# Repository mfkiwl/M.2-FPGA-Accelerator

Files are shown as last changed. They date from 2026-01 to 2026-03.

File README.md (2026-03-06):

# M.2 FPGA Hardware Accelerator Devboard

This is my in-progress FPGA hardware accelerator! It'll essentially plug into an SSD slot on your computer, and function as a programmable FPGA fabric that you can use to practice hardware acceleration and other things in HDL! Not just that though, it also functions as a standalone devboard with USB to JTAG and HDMI and ontop of that, you can use it for hybrid purposes involving external devices AND your computer! 









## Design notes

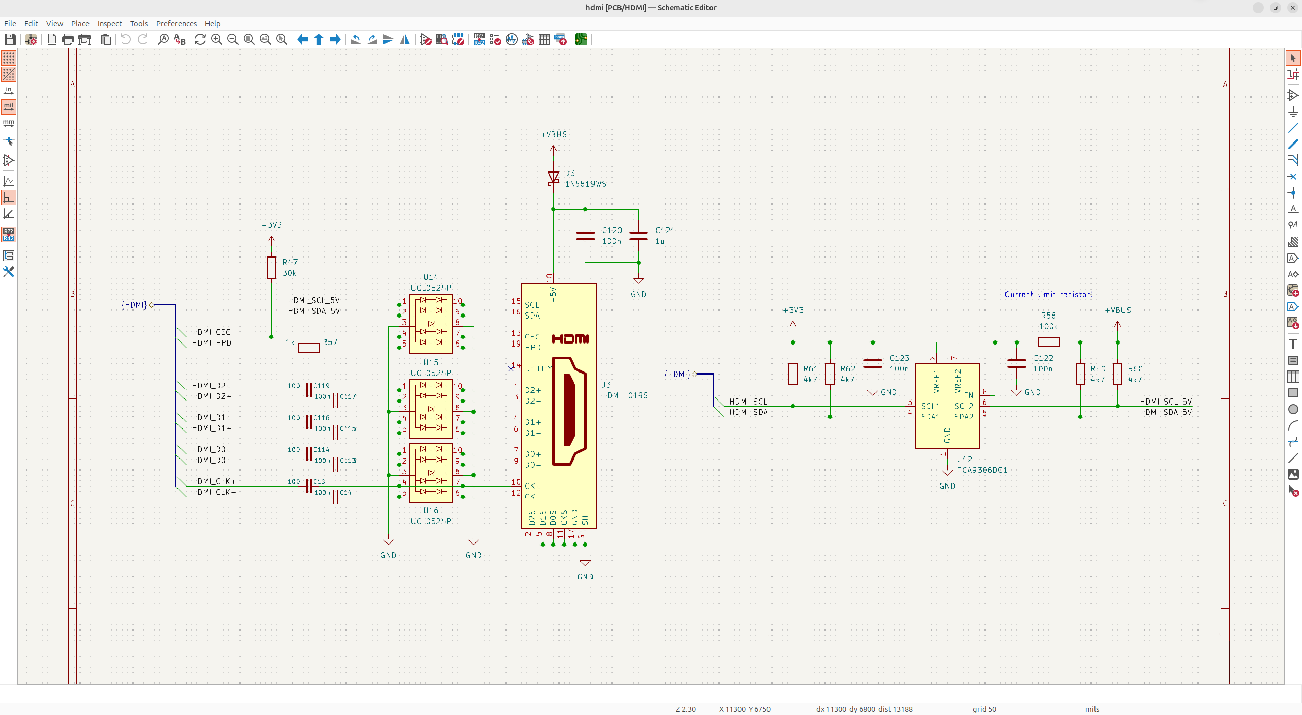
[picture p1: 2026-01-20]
images/Pasted image 20260120061538.png

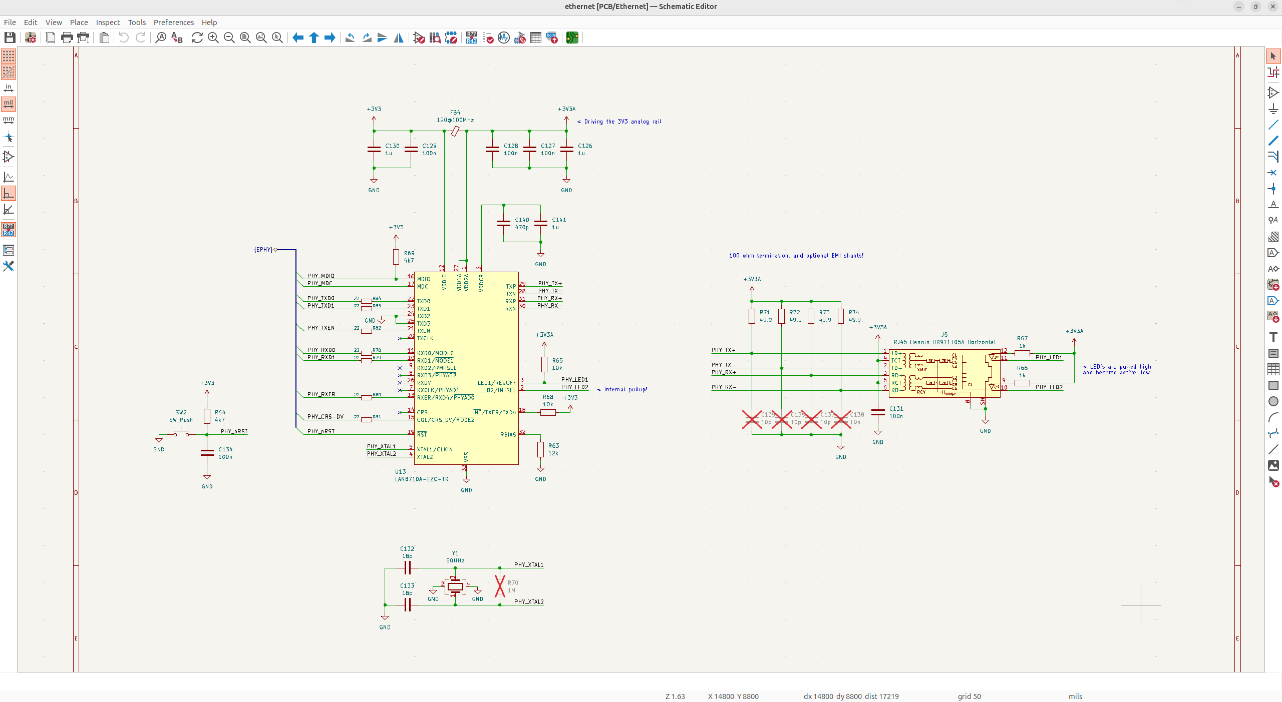
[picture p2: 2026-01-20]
images/Pasted image 20260120062520.png

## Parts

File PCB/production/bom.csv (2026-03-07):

Designator | Footprint | Quantity | Value | LCSC Part #
C1, C101, C103, C126, C130, C133, C134, C141, C142, C15, C152, C153, C159, C160, C166, C167, C2, C21, C22, C23, C32, C33, C37, C40, C41, C42, C43, C44, C56, C66, C68, C70, C87, C89, C90, C94, C98 | 0603 | 37 | 4u7
C10, C11, C12, C3, C4, C5, C6, C7, C8, C9 | 0402 | 10 | 220n
C100, C102, C104, C105, C106, C107, C108, C109, C118, C124, C125, C127, C129, C135, C136, C137, C138, C143, C144, C145, C146, C148, C150, C151, C154, C155, C156, C157, C161, C162, C163, C164, C168, C169, C17, C170, C171, C18, C19, C20, C25, C27, C28, C29, C30, C31, C35, C36, C38, C39, C47, C54, C55, C67, C69, C71, C91, C92, C95, C99 | 0201 | 60 | 470n
C110, C111, C113, C114, C115, C116, C117, C119, C120, C122, C123, C139, C14, C16, C57, C58, C59, C60, C61, C62, C63, C64, C65, C73, C74, C76, C77, C78, C79, C80, C81, C82, C83, C84, C86, C93 | 0402 | 36 | 100n
C112, C121, C46 | 0402 | 3 | 1u
C128, C72 | 0603 | 2 | 47n
C13, C172 | 0402 | 2 | 10n
C131, C132, C140, C147, C149, C158, C165, C34, C45, C49, C51, C53, C75, C85, C88 | 1206 | 15 | 47u
C24 | CP_EIA-3528-21_Kemet-B | 1 | 330u | C542287
C26 | 1206 | 1 | 100u | C15008
C48 | 0402 | 1 | 68pF
C50, C96, C97 | 0402 | 3 | 33p
C52 | 0402 | 1 | 22pF
D1, D2 | 0805 | 2 | KT-0805Y | C2296
D3 | D_SOD-323 | 1 | 1N5819WS | 1N5819WS
D4 | 0805 | 1 | KT-0805G | C2297
FB1, FB2 | 0805 | 2 | 120@100MHz | C5120901
J1 | M.2 M-Key 2242 | 1 | Bus_M.2_Edge_M
J4 | USB_C_Receptacle_HRO_TYPE-C-31-M-12 | 1 | TYPE-C-31-M-12 | C165948
J7 | HDMI_Micro-D_Molex_46765-1xxx | 1 | HDMI_D_1.4 | C711358
L1, L2, L3, L4, L6 | L_Sunlord_SWPA4030S | 5 | 1u5 | C42100
R1, R31 | 0402 | 2 | 100
R10, R11, R12, R13, R34, R38, R39, R40, R41, R45, R46, R5, R51, R53, R54, R7, R9 | 0402 | 17 | 10k
R14, R15, R17, R18, R2, R24, R3, R42, R43, R44, R56, R57, R76, R77 | 0402 | 14 | 1k
R16 | 0402 | 1 | 240
R19, R20, R21, R22, R23, R27, R28, R30, R59, R60, R61, R62 | 0402 | 12 | 4k7
R25, R26, R29, R32, R36, R37, R75 | 0402 | 7 | 22
R33, R47 | 0603 | 2 | 30k
R35, R6 | 0603 | 2 | 4k99
R4 | 0402 | 1 | 2k
R48, R49 | 0402 | 2 | 5k1
R52 | 0402 | 1 | 2k2
R55 | 0402 | 1 | 12k
R58, R65 | 0402 | 2 | 100k
R8 | 0603 | 1 | 8k2
SW1 | SW_SPST_TS-1088-xR020 | 1 | SW_Push | C720477
U1 | Xilinx_FGG484 | 1 | XC7A50T-FGG484
U10 | QFN-64-1EP_9x9mm_P0.5mm_EP4.35x4.35mm | 1 | FT2232HQ
U11 | FBGA-96_8x14mm_Layout9x16_P0.8mm | 1 | MT41J128M16JT-125:K | C426885
U12 | VSSOP-8_2.3x2mm_P0.5mm | 1 | PCA9306DC1 | C129510
U14, U15, U16 | Diodes_UDFN-10_1.0x2.5mm_P0.5mm | 3 | UCL0524P | C2835428
U17 | VQFN-16-1EP_3x3mm_P0.5mm_EP1.68x1.68mm_ThermalVias | 1 | TPS62132
U2 | QFN-28_L5.0-W5.0-P0.50-TL-EP3.2 | 1 | MAX20029ATIA/V+ | C1235515
U3, U4, U6 | Texas_DRT-3 | 3 | TPD2EUSB30
U5 | Texas_VQFN-HR-12_2x2.5mm_P0.5mm_ThermalVias | 1 | TPS2121RUXR | C485916
U7 | W-PDFN-8-1EP_6x5mm_P1.27mm_EP3x3mm | 1 | MT25QL128ABA1EW7-0SIT | C2887898
U9 | SOIC-8_3.9x4.9mm_P1.27mm | 1 | M93C56-WMN6TP
Y2 | Crystal_SMD_3225-4Pin_3.2x2.5mm | 1 | 12MHz | C9002
Y3 | Oscillator_SMD_SiT_PQFN-4Pin_5.0x3.2mm | 1 | 100MHz | C78882

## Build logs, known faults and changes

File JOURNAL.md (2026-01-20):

---
title: FPGA Accelerator
author: Kai Pereira
description: " A low-cost, PCIe FPGA accelerator M.2 M-Key form factor devboard for hobbyists"
created_at: 2025-12-16
---
## The idea - 2 Hours

I've worked on a ton of different boards ranging from keyboards, to motherboards to hackathon badges to even carriers, but now I want to work on something next level.

I've always been fascinated by hybrid computing in a consumer setting and building complicated stuff, so with that in mind, I've come up with my next idea.

FPGA's are becoming much more mainstream for parallelization and computing so I want to explore how hobbyists can leverage this technology in an affordable and cool way.

The thing about FPGA's, is while they're really useful, it's hard to make practical applications of them as a hobbyist, because it's not like you're going to innovate the next big chip or something, but that's where I want to leverage the fact that FPGA's aren't just useful for mainstream chips, but also more niche applications like very specific hardware acceleration, that consumers can actually make cool use of and practice.

Pasted image 20251216201028.png

So the idea is simple, I want a low-cost way, hobbyists can make practical applications of FPGA's in a bunch of different settings.

To do this, I want to provide an FPGA devboard of sorts, that can interface with your computer hardware so you can practice on real-world applications in more niche settings. But I want to go a step further and also make it function as a standard devboard in case you don't have access to an M.2 slot, so I need to break out like standard USB-C and whatnot.

This also means that I want to add other functions like HDMI, maybe even GbE and just generally make it insanely useful to hobbyists!

There's a couple key goals I have for this project:
- Learn to route BGA and high-density impedance controlled traces
- Learn GbE, HDMI and PCIe routing
- Understand at a high level, the physics behind the board
- Focus on routing best practices, specifically minimizing loops

This project has already been similarly done by Phil's lab, but his project was more-so focused on acceleration instead of as a hobbyist development board, but this video will still be really useful to reference during development of this project! https://www.youtube.com/watch?v=8bw80LiCl7g

## Connectors!! - 4 Hours

Now the first thing I have to decided, is what type of edge connector I want to use. Now NVMe SSD's are standard M.2 size, but have different type of "keys" which is essentially where the different holes are on it:

Pasted image 20251219113929.png

NVMe SSD's mostly just use M-Key edge connectors, so that's what I'm going to use.

But now, there's also more than just one type of size, there's actually 5 of them (probably more than that, but the 5 most common)

Pasted image 20251219114039.png

Now 2280 is by far the most common, but I don't actually think I'll use all that space, so for now, I think I'm going to go with 2242 which is decently common still but for other applications most of the time.

The numbering system is really simple. 2242 means 22mm x 42mm, 2280 means 22mm x 80mm.

So now i have to create my footprint and symbol for these edge connectors. I can also easily change my form factor after making the footprint because it's legitimately just the height that changes.

Lucky for me, someone's already made some M.2 footprints and symbols, so I'm going to use these ones from https://github.com/timonsku/M.2-Card-Footprints

Now this person didn't actually make an M-Key, so I had to modify one of the existing ones to make it. M.2 footprints are really interesting, because they literally just remove the pins where the key is and don't really shift anything, so it's easy to make footprints for:

Pasted image 20251219114720.png

Now I was thinking I might be able to use a B+M-Key to be more compatible, but the ECP5 only has a soft SATA PHY or SERDES which would be really complicated and annoying to implement, so I'm just keeping it symbol.

And then this library I downloaded included the symbols already, so I'm all set to get working:

Pasted image 20251219115014.png

## Edge connector and choosing an FPGA - 4 Hours

Now I want to get working on actually wiring the edge connector! The first thing I'm going to do is wire the power and ground.

I decided to use one 100nF cap per pin, and then one 1uF + 10uF per group of them like so:

Pasted image 20251219121205.png

I'm referencing the M.2 PCI express electromechanical datasheet for pins https://picture.iczhiku.com/resource/eetop/sHksKPigIJigRbbx.pdf

Pasted image 20251219121236.png

I've decided to 0402 for 100nF, and 1uF, and then 0603 for 10uF to save as much space as possible, but still be pretty efficient at decoupling.

Next, I need to choose what FPGA I actually want to use. The first thing that comes to mind is the ECP5. It's a small and cheap FPGA with SERDES so it works with PCIe which is really cool. 

It has a faster (5G) and slower version, so I can have gen 2 PCIe speeds which is pretty cool. The minimum 5G FPGA costs around $18.50 https://jlcpcb.com/partdetail/Lattice-LFE5UM5G_25F8MG285C/C1551932 so it's a pretty good option.

But there's also the Xilinx Artix FPGA which is significantly more powerful, the XC7A100T has nearly 4x the LUTS and is way more powerful, but is also significantly larger, having 4x lanes. The price is actually pretty good though, coming in at just $29.

So the Artix FPGA is probably a better option, because the price and accessibility of the ECP5 for the specs I need is just kind of out of scope. It'll also give me really good practice with a really popular AMD FPGA which could be really helpful for the future! 

Now the Xilinx Aritix has MANY different packages, ranging from 12K to 215K LUTs and 720 to 13000 Kb of memory. I also need a minimum of 4 GTP transceivers which are essentially just high speed pins so 15K LUTs minimum.

But let's stay within the price range, so I want under $20 for the FPGA and preferably over 25K LUTs which gives me many good options!

This means I should also increase the size of my board from 2242 to 2280 which I actually wanted an excuse to do, and I can also add all those other features. 

So in the end, I think I'm going to go with the XC7A50T-1FGG484C, the Xilinx Artix 7, with 50K LUTs, coming in at just $17 at minimum quantities, and having 484 pins!!! https://jlcpcb.com/partdetail/AMDXILINX-XC7A50T1FGG484C/C1521780

I think this is honestly the perfect option, and I know Phil's Lab uses the same one, but it's the best for the job!

## Working on the FPGA - 3 Hours

Now that I know I want to use the Artix 7 FPGA, I need to add it into KiCad. I'm really lucky because KiCad actually has this symbol built in, but the footprint doesn't seem to come up, so I'll need to look into that:

Pasted image 20251220104108.png

Pasted image 20251220104157.png

And lucky me, a footprint actually does exist!!

Pasted image 20251220104406.png

Next, I want to figure out what voltage lines I need for my project. Based off of the datasheet, I'll need:
- VCCINT 1V, FPGA fabric logic, lowest voltage for CMOS is 1V
- VCCBRAM 1V. internal block RAM, needs to be really stable
- VMGTAVCC 1V, analog GTP transceivers voltage, might need to be seperate from VCCINT
- VCCAUX 1V8, powers configuration and clocking stuff, 1V8 for noise margin
- VCCO 3V3, powers I/O banks 3V3 because connector is 3V3 and I use 3V3 logic
- VMGTAVTT 1V2, very interesting termination voltage, it basically controls the impedance of the GTP transceiver/PCIe lines, and makes sure they don't see reflections and too much nosie!
- DDR3 Voltage, 1V5 for DDR3 I/O bank pins which are 1V5 for standard DDR3 (1V35 for DDR3L)

Pasted image 20251220165608.png

So now that I have all the theory worked out, I can get working on making the actual thing! 

This was just a bunch of datasheet reading today and a couple video's, but I have a really good idea on how to do this now!

## Decoupling time! - 5 Hours

Decoupling is fairly simple with the Artix 7, the datasheets tell you almost exactly how to do it:

Pasted image 20251221082541.png
Pasted image 20251221082558.png

So just like that, I organized everything and added in the decoupling: 

Pasted image 20251221082621.png

And I'll also need ferrite beads on these lines, but before that, I want to figure out what PMIC I'm going to use. I have 4 rails, and I need 3V3, so a quad switching buck converter would be a really good option! 

I want to do this, because the characteristics of the bucks will help me determine the values of the ferrite beads!

I spent nearly 6 hours straight, fueled from Yerba and classical music trying to find the best buck, and I've found 2 possible options.

The [MAX20029](https://www.analog.com/en/products/max20029.html) is the lower cost option, with up to 1.5A channels, and is fixed/adjustable, though I would only use the fixed part. It's high efficiency, but the efficiency kind of drops off at lower current, but it has a smaller package and is designed for automotive. You can use the same value inductor on all the rails and it has power sequencing. This is the same one that Phil's lab uses, and it's really good!

The [LTC3370](https://www.digikey.ca/en/products/detail/analog-devices-inc/LTC3370IUH-TRPBF/5155587) is a bit more overkill, with strong 2A channels, and really good efficiency characteristics. It's a bit larger and a bit more expensive, and it's a bit overkill, but you can have the same value inductors, and is also a fantastic option! 

I've legitimately looked at 100's of buck converters, and these are probably the 2 best options! 

In the end, I think I'm going to go with the MAX20029 because it has smaller inductors, is cheaper and perfectly fits the specs. Even though it's what phil uses, it honestly just is the superior option and the only downfall is I can't use any of the fixed variants, so I have to use quite a few voltage dividers. 

I've done a lot of research today, so I think I'm going to hop off for now! 

## Power management! - 8 Hours

Now that I've found what PMIC I want to use, we need to add it into KiCad.

But after some second thought, I've decided that the LTC3370 is actually probably a better choice because of it's higher current demands which means better power tolerance, and I want support for all the extra peripherals I might add too. 

So let's add that in! 

The first thing I need to do is create the symbol for my buck converter. After referencing the datatsheet and tuning things up, I've come up with this pretty clean symbol that will probably change to my likings, but it's good as a template, and has all the necessary pins and footprint! 

Pasted image 20251225000450.png

Pasted image 20251225000521.png

Next, I'm going to wire all the important stuff for the buck converter. Per the datasheet, each input should have a 22uF cap, VCC should have 10uF, and each 2A channel output should have 47uF! 

I calculated the voltage dividers using VOUT = VFB(1 + R2/R1), and used 100K as my bottom resistor to minimize my BOM. This gives me a really nice and convenient voltage divider setup:

I also used 2.2uH inductors which are recommended by the datasheet for 2A, and they have a really low ESR to minimize power loss:

Pasted image 20251225000820.png

BUTTTT, this is kind of when I had a brain blast and decided to just outright switch to the MAX20029.

I realized that I would be saving over $7 with the MAX20029 and it has way simpler power sequencing and smaller package, so it's just significantly better.

So let's make the symbol for the MAX20029! I came up with this tall little symbol, I might make it larger but it kind of fits my needs:

Pasted image 20251227142741.png

And then it's really simple wiring, you just need pullups on PG to have a stable state, and also calculate the voltage dividers and frequency matching capacitors:

Pasted image 20251227142844.png

PG1 will go high when it's active, and the pullup just helps to ensure it gets there. There's no voltage divider on 1V0, because the VOUT is already 1V, and then the rest have voltage dividers to get there and frequency matching rounded down to the nearest E6 capacitor!

## More decoupling and filtering - 5 Hours

Now that I've finished with my power supply, I need to figure out how to properly filter it for my analog rails! 

This actually took me a really long time to figure out because I've never fully understood ferrite beads, but after a bit of research and talking with the KiCad guys, I've done a simple but effective implementation in my opinion:

Pasted image 20251229001159.png

I chose 600R@100MHz to filter out the high frequency noise moderately and it's low DCR so it has a minimal drop and is up to 2A. I made a little low pass filter LC filter by adding some shunts to ground, and added a bulk before the cap on MGTAVCC because it's higher current!

I decided to also set up an LTSpice simulation for these ferrite beads, just to make sure everything will be fine, and I can use it in the future for more accurate testing and adjusting once I've finished routing the board!

This took me a really long time to figure out, but I think it turned out really well! 

Pasted image 20251231173655.png

This isn't too relevant right now, but will be really useful once I've finished routing! 

I also fixed up some of the decoupling on my m.2 edge connector because it wasn't using the standard values in my schematic.

Pasted image 20260106130817.png
It actually took me so long to figure out LTSpice, but that was essentially how my day went! 

## Configurations and JTAG, oh no - 15 hours

So now I have the majority of my fundamental power system in place, but I actually need a way to program this thing. The first thing I have to do is configure the artix 7 to work over master SPI. I referenced the datasheet for this part and it pretty much tells you what to do:

Pasted image 20260106131135.png

A 0 means tie it low, and a 1 means tie it high. I also added this DNP resistor in case you want to use the artix 7 built in flash for debugging, so it's just kind of handy:

Pasted image 20260106131305.png

I also learned how buses work, and created a JTAG bus which connects to a hierarchial label which will connect to my USB to JTAG/TC2030.

The next thing I need to figure out is my JTAG. This is how the board will be programmed, the JTAG interface will feed into the artix 7, and the artix 7 will feed it into SPI.

Now the first thing I want to do is add on a TC2030 interface which is a compact way of programming JTAG using this little debugger:

Pasted image 20260106131603.png

I also wanted to have USB to JTAG because it's way easier and actually cheaper to debug with it because you don't need an external probe. Now I probably spent over 10 hours thinking about how I should do my USB to JTAG, I put so much thought into this.

But at the end of the day, Vivado, the tool I'm probably going to use to program my board, and all the other tools only really support FT2232H, and because I'm probably going to be debugging a bunch, I didn't want to bitbang, so I decided to go with the large and expensive IC for programming!

The thing is, I don't have to place the FT2232H in my production runs, only in my prototypes runs so it's perfectly fine to have for prototyping, it'll just cost more for those boards though....

I also wanted to have USB to power and program the board, so I came up with this monstrosity of a schematic:

Pasted image 20260106131956.png

USB-C comes in, get's bucked down and has some ESD protection. The data lines go into the FT2232H USB to JTAG, and then JTAG get's pulled up so nothing's floating, and goes into my bus for use in the configurations schematic. The TC2030 will go underneath the USB-C receptacle and if you DNP the USB to JTAG logic, it'll still be programmable via the probe. Pretty cool huh :D

I did some really good work for these couple days, but I'm still missing some fundamental logic for this circuit that's really important, but we'll see this in the next section!

## Power architecture - 6 Hours

Now there's a bit of a problem that arises with having both USB-C and an m.2 edge connector supplying our board. What if the current just flows right onto the motherboard, completely frying and destroying it.

This is why we need to implement a power mux on our board! I usually try to shy away from power mux's because there's usually a smarter way of solving power issues, but in this case, it was pretty much necessary, and the slight added cost is important so that our board functions smoothly.

I found this nearly perfect IC, which let's met control the ramp up of the inrush, the max current, switchover and so much more, all in a small package! This is THE TPS2121RUXR.

This beauty took me a whole to wrap my head around, but it does everything for me:

Pasted image 20260106132555.png

I prioritized the M.2 connector source because the motherboard is always going to supply smooth power because you need to be able to have a reliable computer right!

And then of course I added some smooth decoupling, and we got that finished after some time! 

I'm going to end off this section here, because now we're going to get into some really technical territory, figuring out the pinouts for my flash, ram, etc. It's going to be a wild ride! 

## Flash storage and configurations - 4 Hours

Now that I've finished with the power architecture of my board, I need to implement all the configurations for my board and also add the flash storage.

The flash storage is fairly simple, there's some fixed pins on the artix 7 for it, so I can just wire it to those with some pullups according to the artix datasheet. I then added some decoupling:

Pasted image 20260111151005.pngPasted image 20260111151023.png

Next, I added a basic configuration to the board to make it work according to UG470:

Pasted image 20260111151114.png

- DONE is wired so that the LED will turn OFF when the configuration is finished and ON when it's actively configuring. 
- INIT is just a configuration pin that tells you if there's any configuration errors and needs to be pulled high <= 4k7R
- PROGRAM is another configuration pin that's used for configuration reset, and I just needed to pull this high. After reading this a second time, I decided to actually add a button to manually reset it if I wanted to, because this board is technically a devboard ya know (shown below)
- CFGBVS is a bank voltage configuration, it's needed because there's configuration pins on multiple banks so to maintain a near the same voltage of all of the them, I pulled this high to tell the artix 7, they're all 3V3 essentially
- And then, VP/VN, VREFP/VREFN and DXP_0/DXN_0 are essentially just part of the XADC to get internal reads of the FPGA and whatnot, and I just tied them low for now to disable all of that, but I want to revisit it, but not necessarily change any of it!

Pasted image 20260111153814.png

## Fun DDR3 wiring time now :D - 6 Hours

Now that I've wired up the flash storage, I need to add in the DDR3 memory! Flash storage is non-volatile which means it stores information long term, retaining all of it without power, while RAM is volatile and is used for active tasks (but you probably knew that ;). 

DDR3 works pretty fast, so you have to pay attention to how you wire it! I chose my RAM from an artix 7 datasheet which specifies the compatible ones you can use, and I chose MT41J128M16JT.

This is a 2 Gb (gigabit) memory with 16 bit data width which means it's 256 MB (2Gb / 8) of memory that can fit 128M words 16 bits wide, because 2Gb / 16 = 128! 

Pasted image 20260111211326.png

I created this custom DDR3 symbol because I like to have my decoupling pins visible so I don't make any dumb mistakes. I did a 100nF cap per VDD pin and then a bulk cap near both sides to keep it stable.

Next, I wired all of the address, command, data and clock buses to hierarchical sheets to keep it clean.

CS# is then tied low, because I'm only using one memory IC, and I have pulldowns on ODT, CKE and RESET as suggested from most reference boards. I put a 100R shunt resistor (an AC resistor) to match the differential impedance of 100R, and then ZQ is tied to 240R which is like a calibration pin and needs to be tied with this exact value! 

You'll notice a perfect split voltage divider on Vref, which is essentially just half of VCC, and it needs to be really precise to distinguish cleanly between high and low data signals for fast DDR3 signals. I put a bunch of decoupling on it to make sure it's really precise with very low noise! 

And that's our DDR3 wired, it was a lot more complicated to do than I described, but that's the gist of it! 

## PCIe and the GTP WHAA transceivers ;) - 5 Hours

Now that I've added DDR3 in, I can power on my board, fully program it and execute commands on it too! Now I need to wire the PCIe lanes to the GTP transceivers which lets me board connect to your computer via the m.2 connector! 

Remember earlier how we added in the m.2 connector for power, well now I just have to wire all the lanes up and came up with this:

Pasted image 20260111213647.png

I changed up the decoupling to instead be a mid range cap per group of pins, because all I really care about is dampening the inrush when plugging the board in/out and powering it on. 

Now let's list out what all of these signals are for! All except for SUSCLK are SATA only pins, and SUSCLK is just for low power states, when you sleep your computer and want to still maintain basic functions which I don't want.

Next, I actually modified my old symbol to create this edge connector symbol which basically just inverses the PCIe text to be more accurate of what's happening on our board. So the pins that were originally receiving PCIe in the form of a bus, are SENDING them now on our board. So all of these transmits, are what's transmitting to our card.

It's mutually known that the side receiving the signals should handle it's own AC coupling, so my FPGA TX lanes, which are sending from the edge connector, and receiving into my board, are going to be AC coupled! 

Because PCIe is close to a fundamental square waveform, it's got sharp edges. So these capacitors in parallel filter out the DC noise, and only allow the switching waveform noise to pass through, pretty cool huh! I used 220nF because it's suggested for if you want multiple generation backwards compatibility because you can use like gen 3 in gen 2 systems, gen 4 in gen 2 and so on and so forth.

CLK also has AC coupling because the direction isn't fixed so they should both be handling it regardless! 

Next, you'll notice 22R dampening resistors on some of the command lines. These are the longer and slower command lines which just travel really far, so I just want to make sure nothing got messed up on the way. PERST is a bit faster so I don't want to cause anti-resonance by adding in dampening resistors on it.

Now we need to just wire these PCIe signals into our FPGA, and BOOM, we're done!

Pasted image 20260111214553.png

We don't use the other clock and it's probably reserved for some other uses, so I'm just going to no connect it for now! I want to double check I did this right later, but it should be fine! 

## Time to HDMI - 6 Hours

Because I want my FPGA hardware accelerator devboard to function as a standalone devboard, I really want to add HDMI so that I can use it as a linux capable device, and some other very fun shenanigans. 

Because you could plug it into both your computer and HDMI, you could do fun things like low latency video output or video processing or even data visualization for the whole acceleration!

So I came up with this little schematic:

![[Pasted image 20260120061538.png]]

First of all, I don't want ethernet powering my board, so I added a diode to prevent that, and it's connected to VBUS so if USB is plugged in, you get the extra features from HDMI.

I want to actually add a really small boost onto the board so that I can get these features, so I'll think about the best way of adding that! 

My board is pretty noisy, so I added a 1uF cap just because I can, and then of course 100nF for basic decoupling.

The only signals that actually need level shifting is DDC because it's I2C so it's decently fast and important signals. I decided to do some fancy current limiting on HPD so it's a really weak 5V signal that can't damage my FPGA but the FPGA can clamp the voltage to still be able to read it! 

And then CEC is just the electronics control and it's a 3V3 signal that I just need a weak pullup on! 

I added ESD protection to all of the lines, just because I want to create a pretty professional board, and I also added minor AC coupling because it's really fast edge-rate signals.

I think I had a really strong fundamental understanding of this wiring which I'm really proud of myself for, but I really need to get that 5V sorted out, and a $1 boost might be the best way to do that. 

## Ethernet shenanigans - 7

The second peripheral I wanted to add onto the board is ethernet! 

Ethernet is really cool to add to an FPGA board like this, because it allows you to use the FPGA as like a firewall of sort, or even send signals, and it just has some really neat use cases.

I decided to use a magjack with integrated magnetics and other useful stuff because I don't want to have to worry about all of that working with ethernet for the first time. 

![[Pasted image 20260120062520.png]]

First, you'll notice really strong pullups on MDI lines. These aren't actually pullups, and are instead parallel termination. Essentially when signal reflections hit these lines, they'll sink into the power/ground instead of just continuously reflecting, and this is why it's on the analog rail, so the power can get filtered! 

Next, you'll notice my basic decoupling and termination on TX/RX lanes. The RX termination will be close to the PHY, and the TX termination will be closer to the MAC.

RMII needs a 50 MHz crystal, so I've added that in, alongside a feedback resistor which just makes the crystal function smoothly, but you don't really need that so it's just DNP.

I added a button onto the ethernet PHY to force reset, because it's a devboard, I just want a bit more customization, so I decided to just add this!

Finally, we have the LED's, one is pulled up internally, and one needs an external pullup, but once they have pullups they act as current sinks so I can just wire those as sinks to the PHY LED's.

And BOOM, we have ethernet fully wired on our board! I'm really excited to work more with ethernet and understand the PHY and magnetics some more, because they seem really cool!

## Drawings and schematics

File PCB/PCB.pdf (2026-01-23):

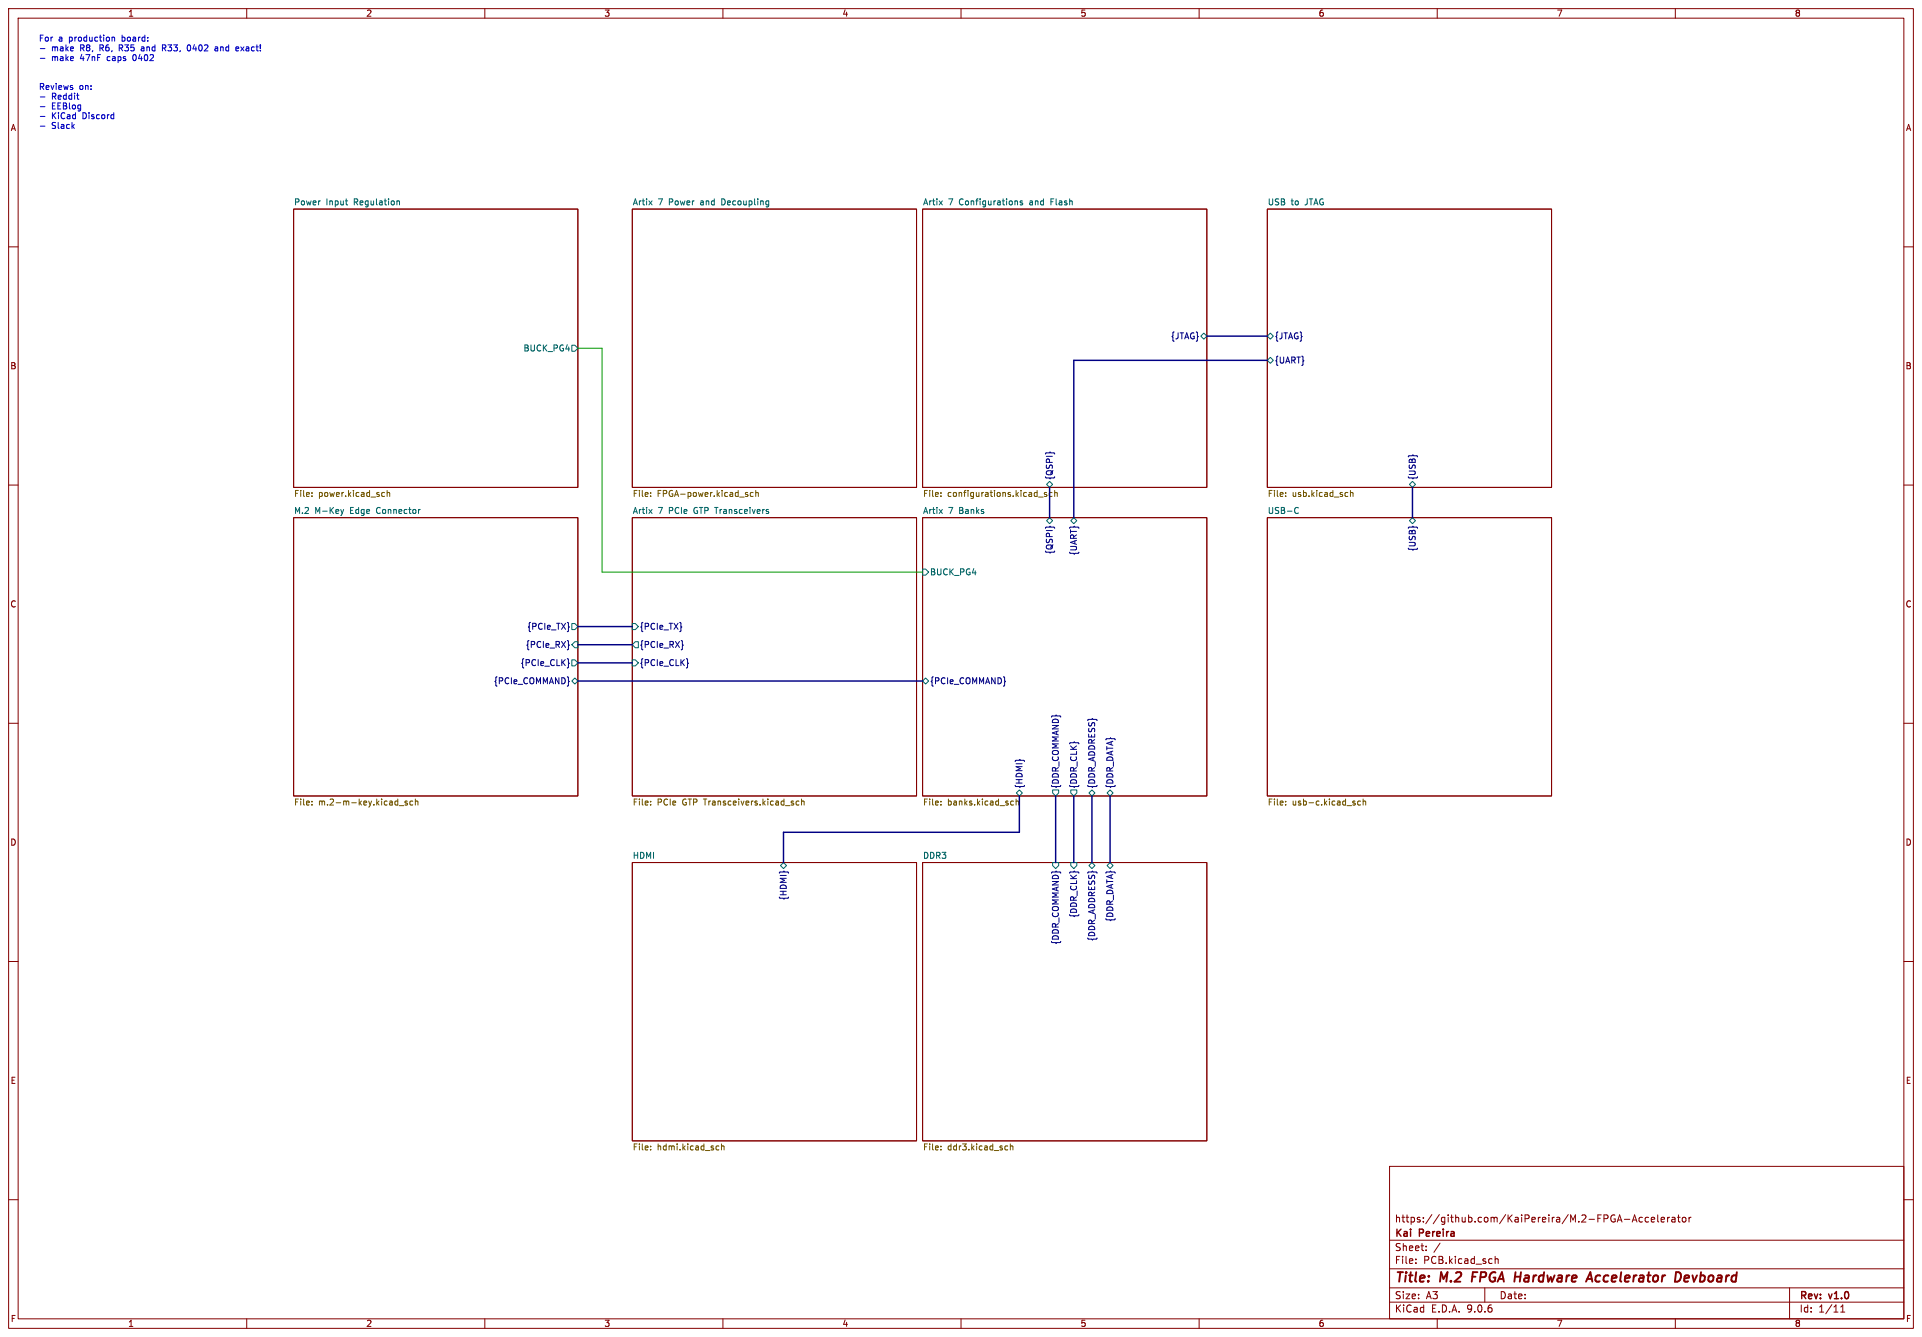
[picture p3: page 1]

BUCK_PG4 Power Input Regulation File: power.kicad_sch

Artix 7 Power and Decoupling File: FPGA-power.kicad_sch

{PCIe_COMMAND} M.2 M-Key Edge Connector File: m.2-m-key.kicad_sch

{PCIe_CLK} Artix 7 PCIe GTP Transceivers File: PCIe GTP Transceivers.kicad_sch

https://github.com/KaiPereira/M.2-FPGA-Accelerator

Id: 1/11 Title: M.2 FPGA Hardware Accelerator Devboard

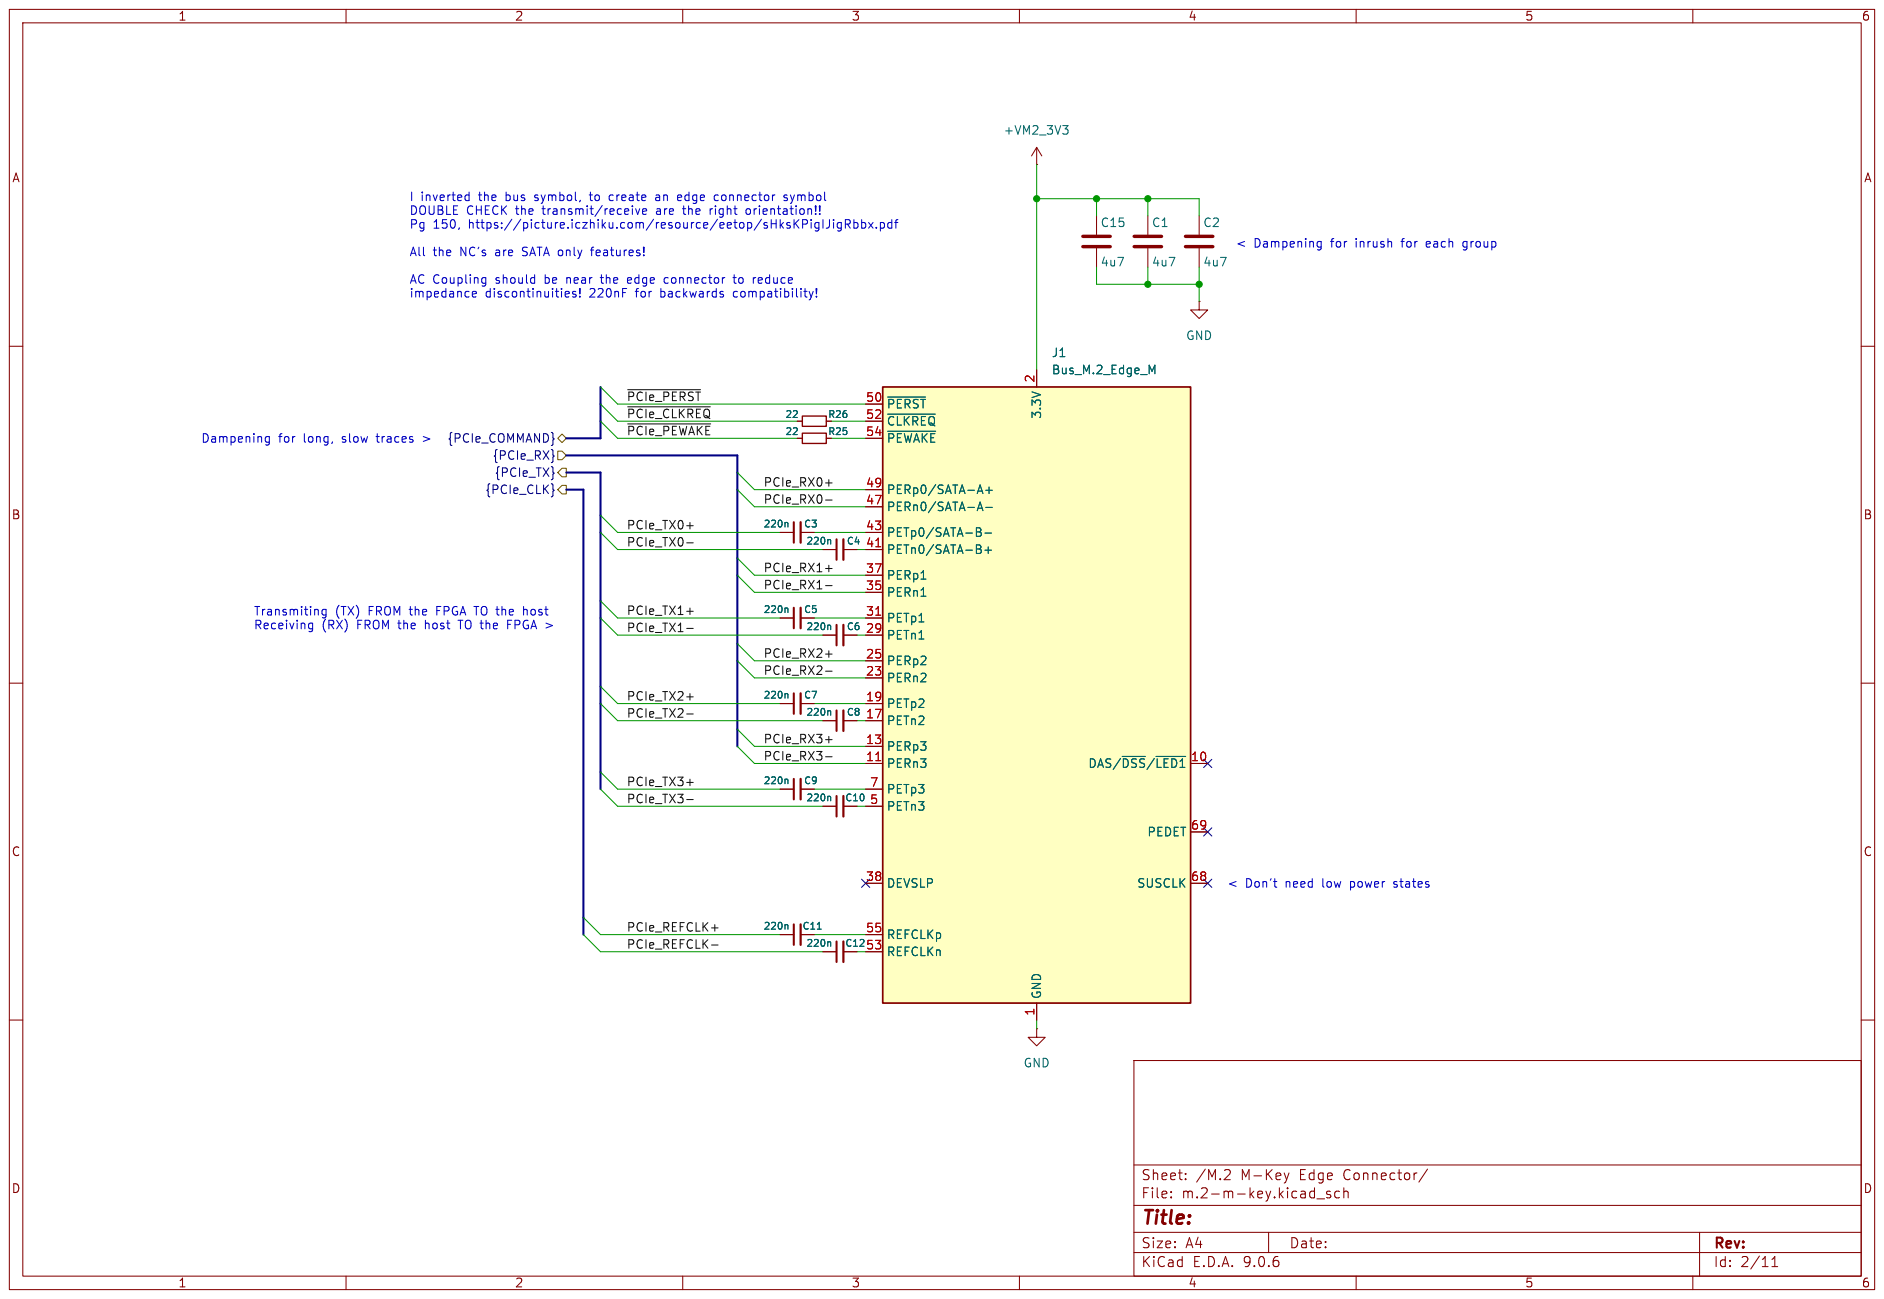
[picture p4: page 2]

1 DAS/~{DSS}/~{LED1} 10 PEDET 69 SUSCLK 68

< Don't need low power states

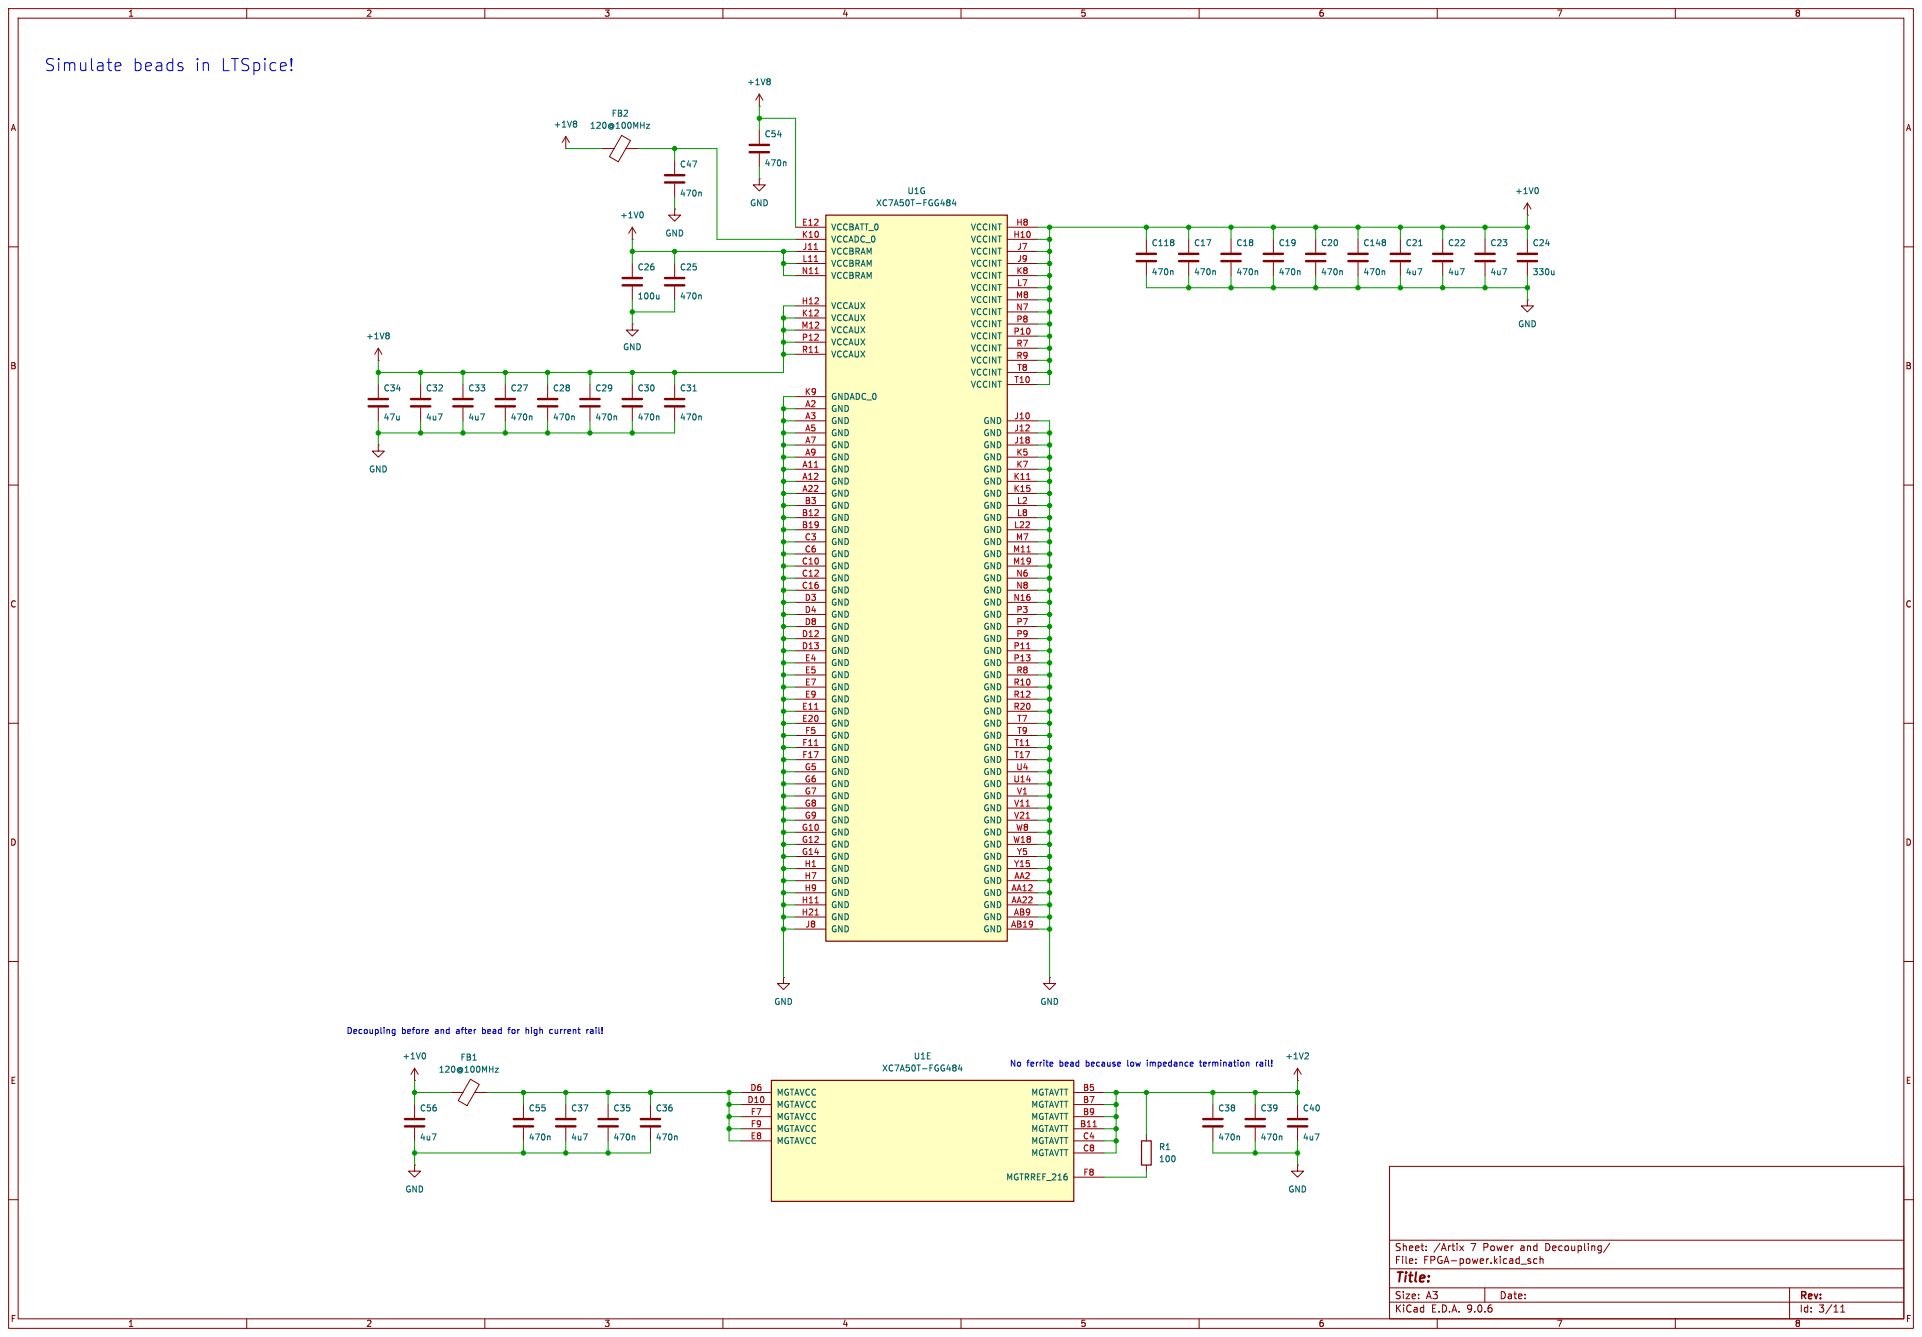
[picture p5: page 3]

Simulate beads in LTSpice!

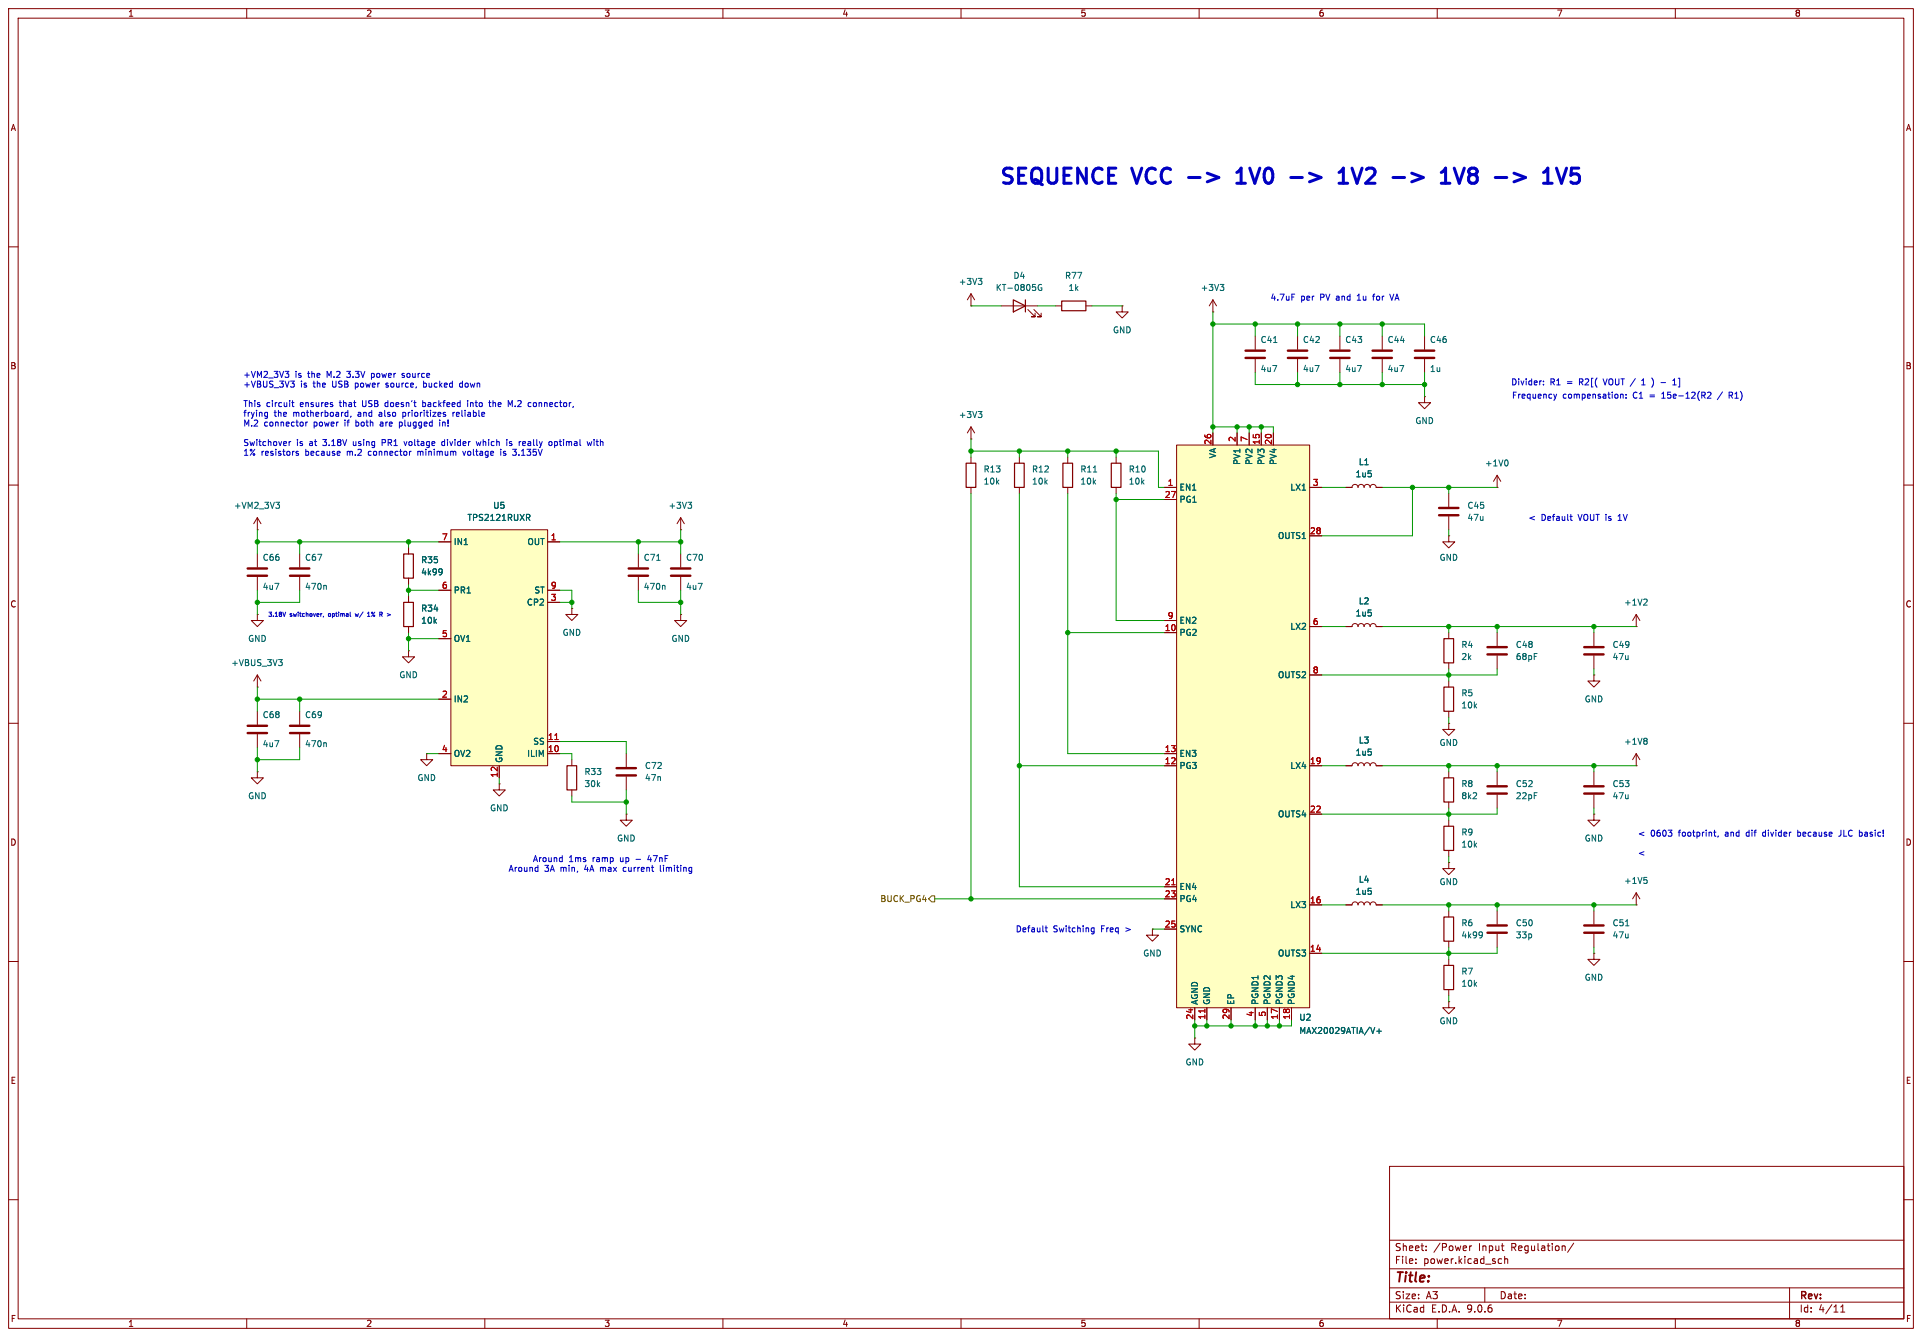
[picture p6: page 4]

4.7uF per PV and 1u for VA

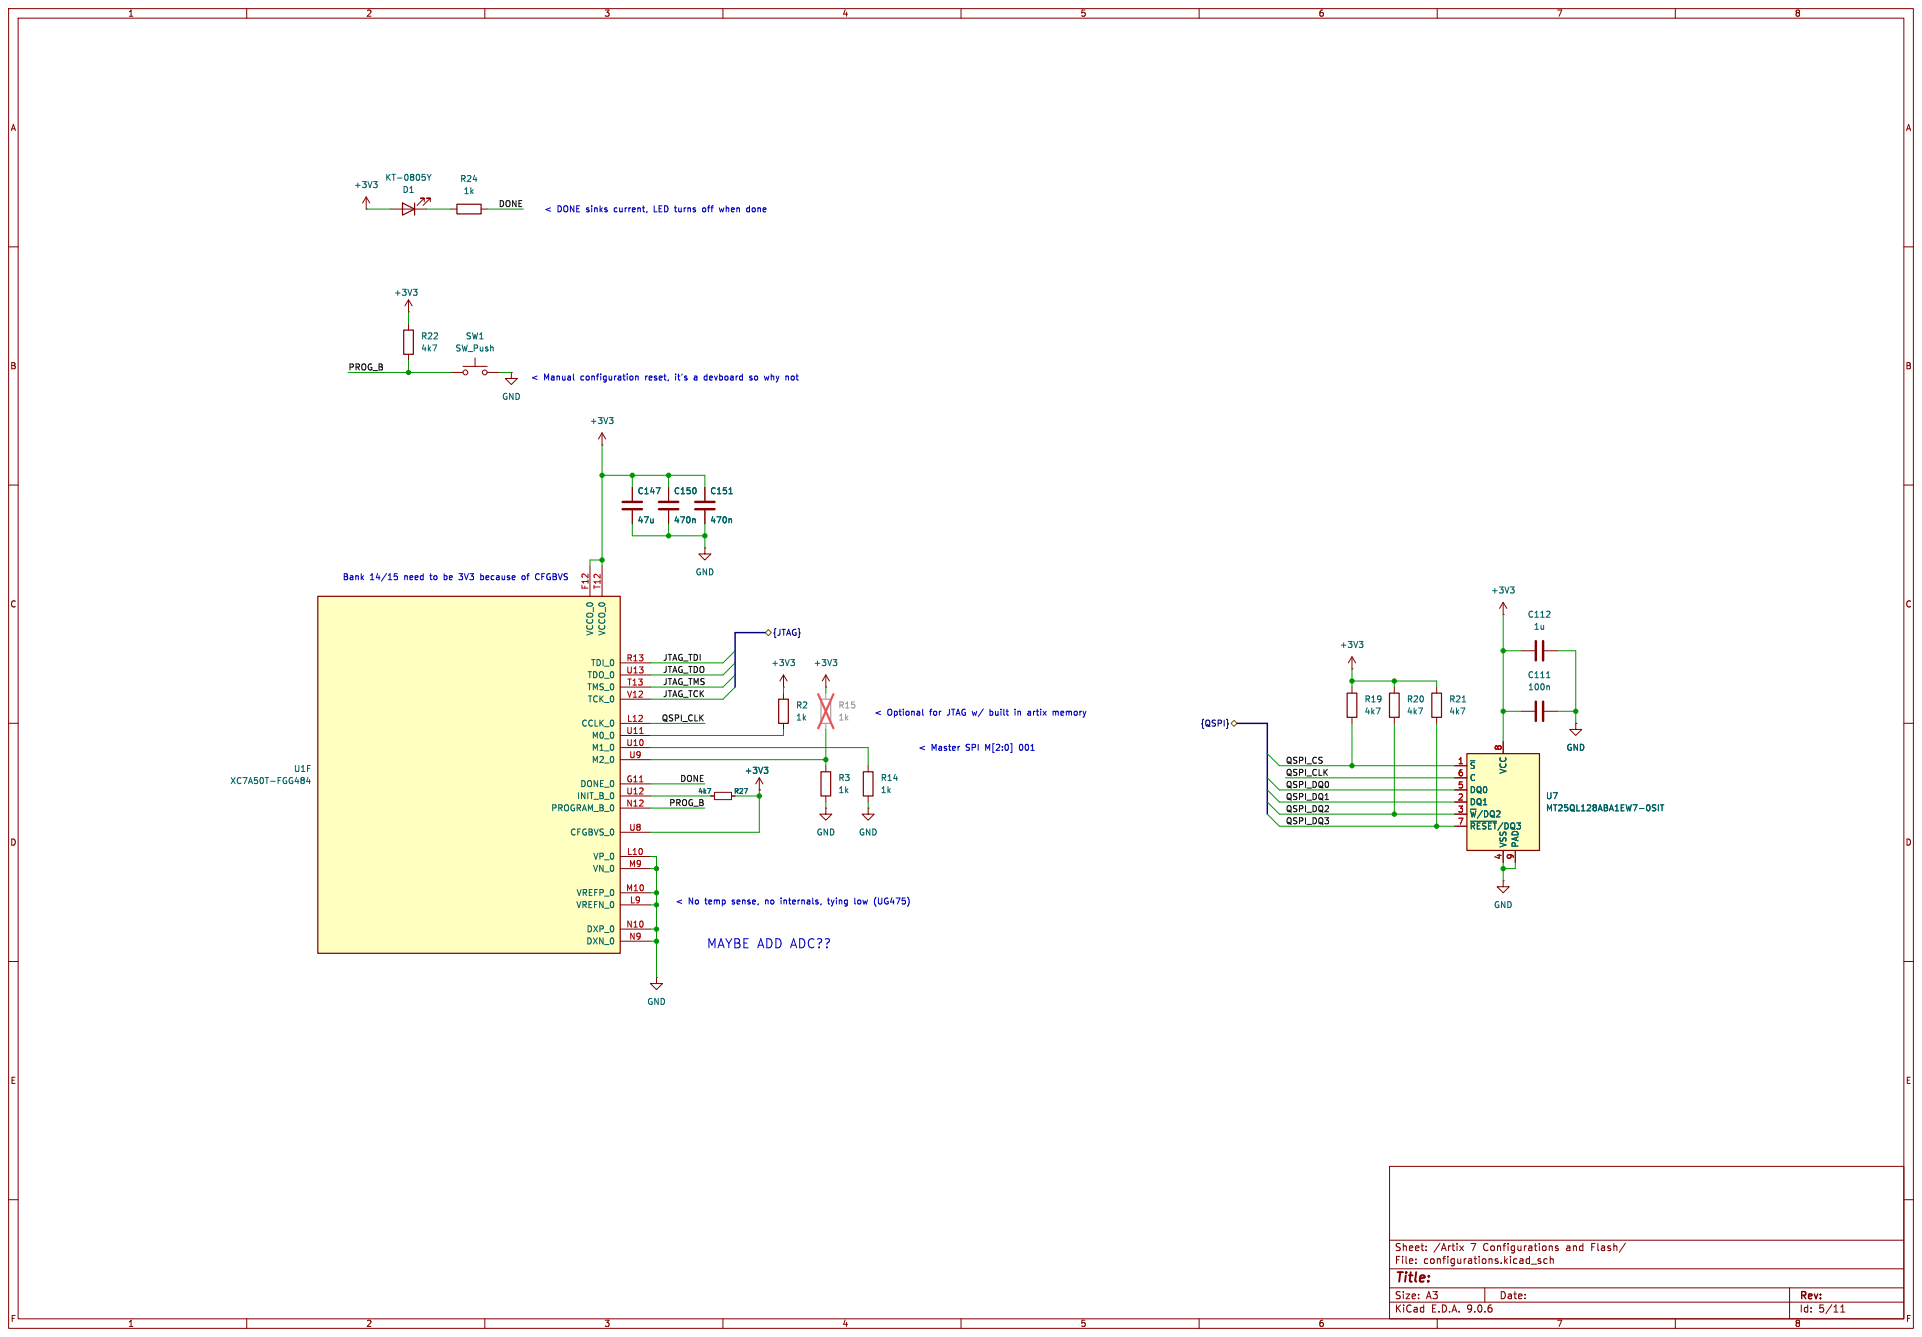
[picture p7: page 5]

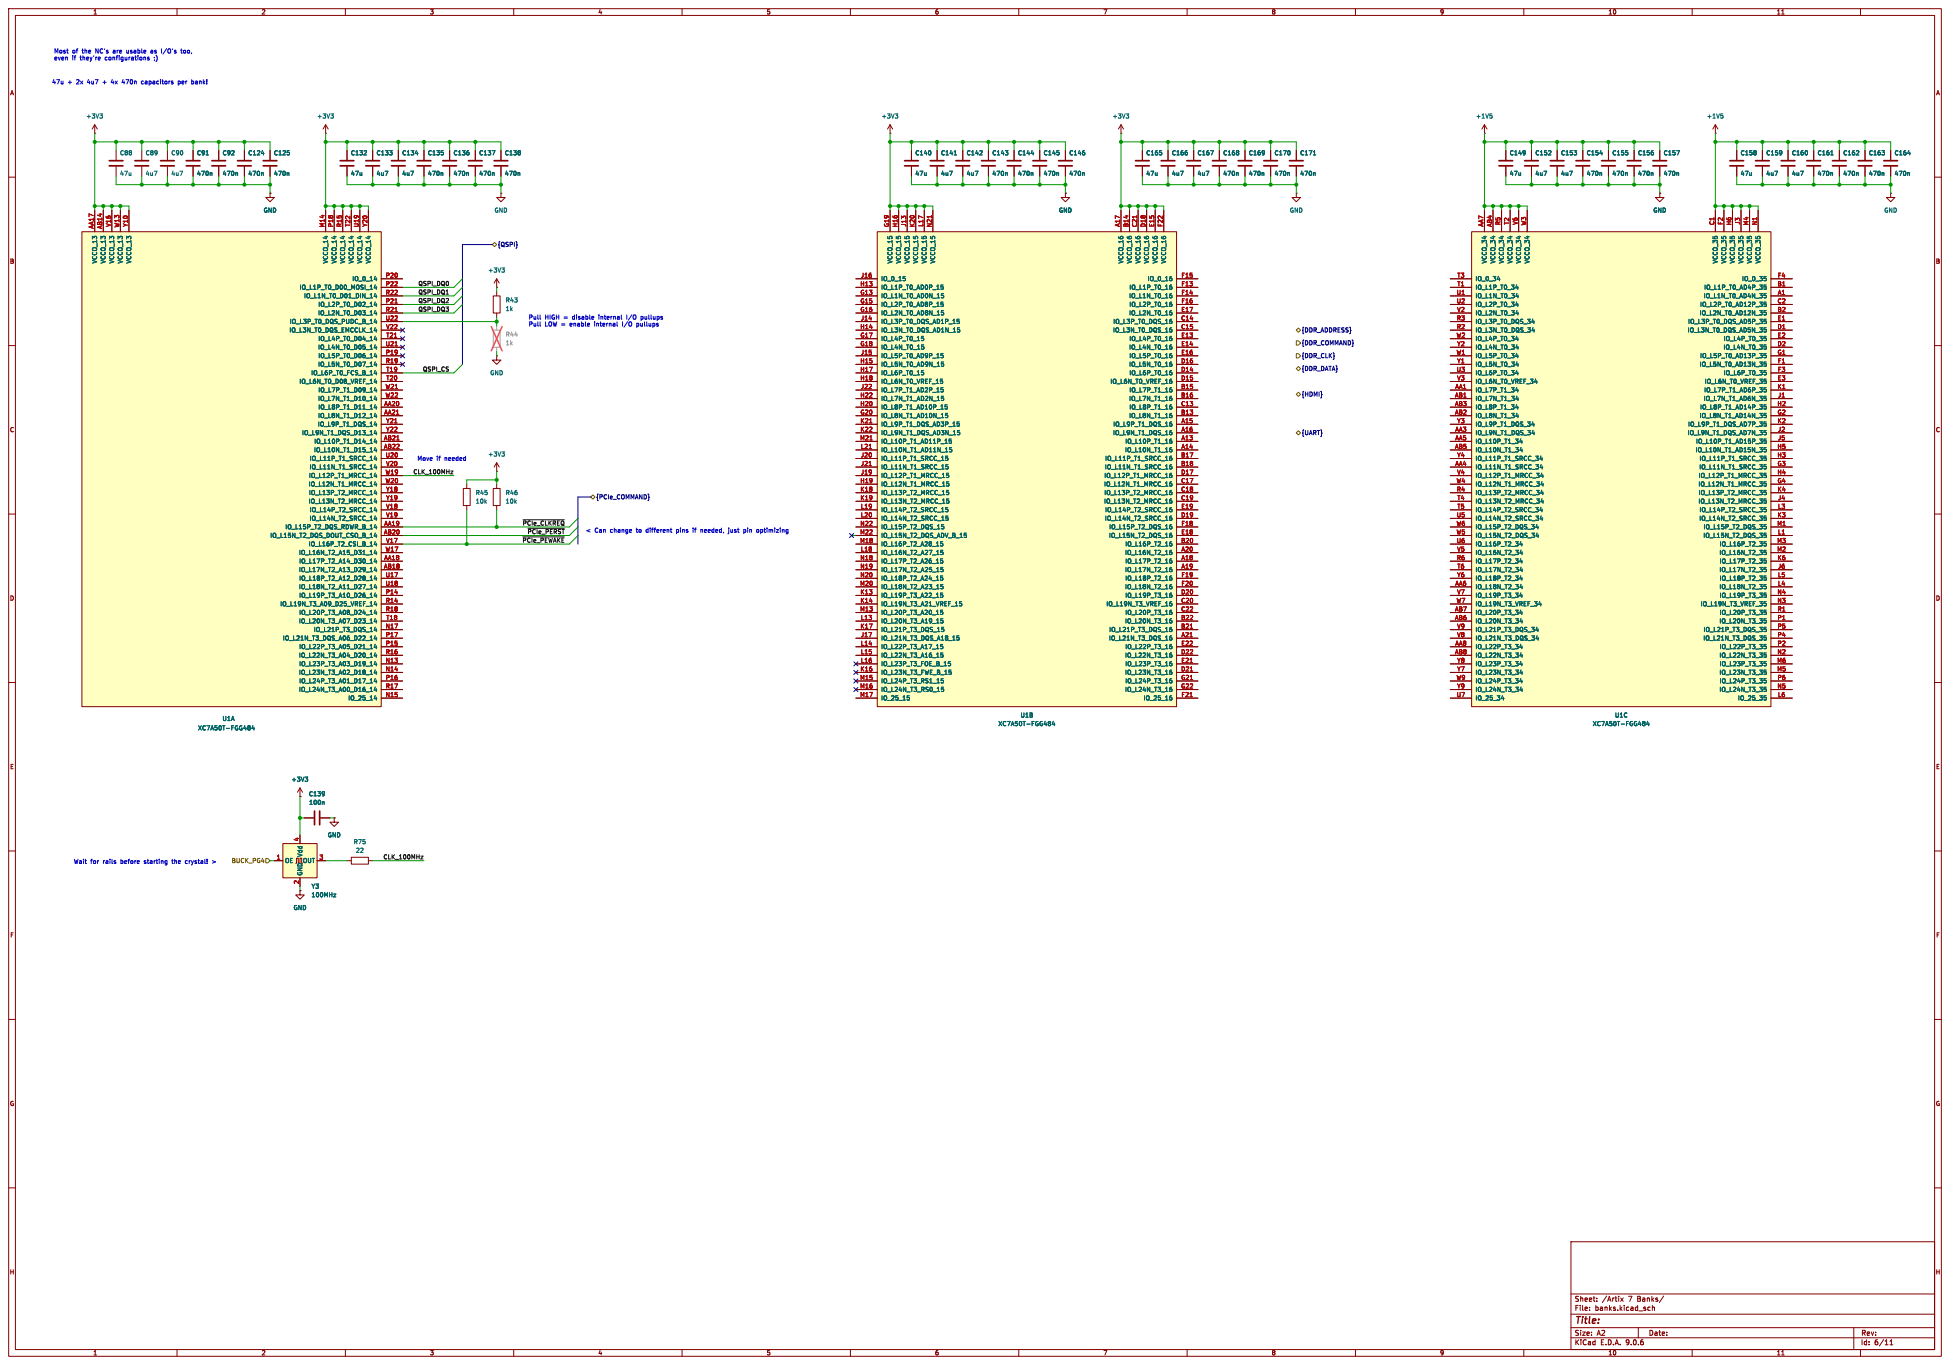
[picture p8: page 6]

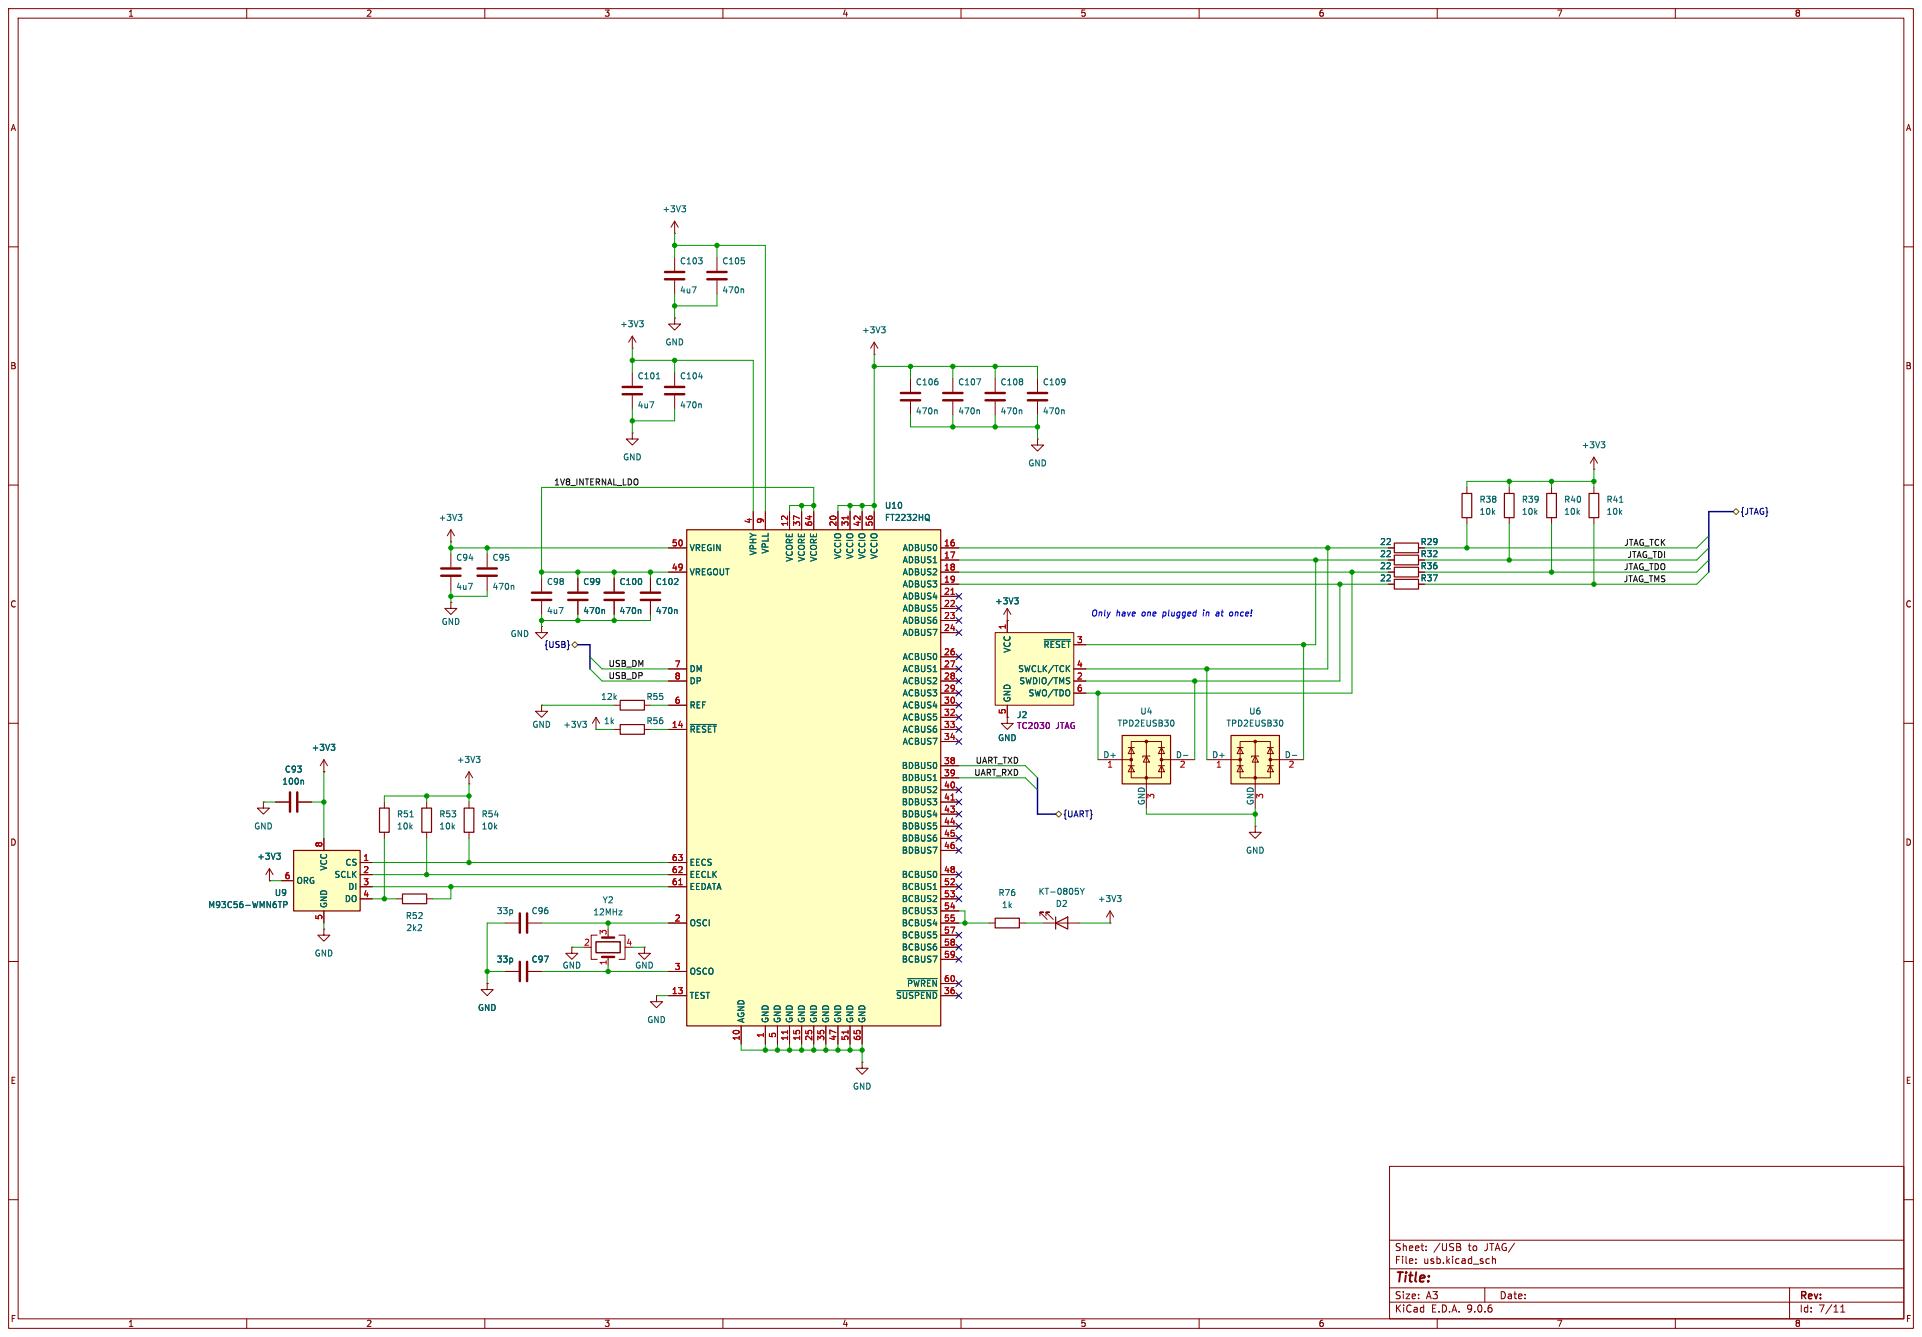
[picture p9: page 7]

Only have one plugged in at once! U10 FT2232HQ

5 VCORE 12 GND 11 VCORE 37 GND 15 VCORE 64 GND 25 GND 35 VCCIO 20 GND 47 VCCIO 31 GND 51 VCCIO 42 GND 65 VCCIO 56 ADBUS0 16 ADBUS1 17 ADBUS2 18 ADBUS3 19 ADBUS4 21 ADBUS5 22 ADBUS6 23 ADBUS7 24 ACBUS0 26 ACBUS1 27 ACBUS2 28 ACBUS3 29 ACBUS4 30 ACBUS5 32 ACBUS6 33 ACBUS7 34 BDBUS0 38 BDBUS1 39 BDBUS2 40 BDBUS3 41 BDBUS4 43 BDBUS5 44 BDBUS6 45 BDBUS7 46 BCBUS0 48 BCBUS1 52 BCBUS2 53 BCBUS3 54 BCBUS4 55 BCBUS5 57 BCBUS6 58 BCBUS7 59 ~{PWREN}60 ~{SUSPEND}36 C102

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

5 CS 1 SCLK 2 DI 3 DO 4 +3V3

5 ~{RESET}3 SWCLK/TCK 4 SWDIO/TMS 2 SWO/TDO 6 GND

5 ~{RESET}3 SWCLK/TCK 4 SWDIO/TMS 2 SWO/TDO 6

5 CS 1 SCLK 2 DI 3 DO U9 4 M93C56-WMN6TP

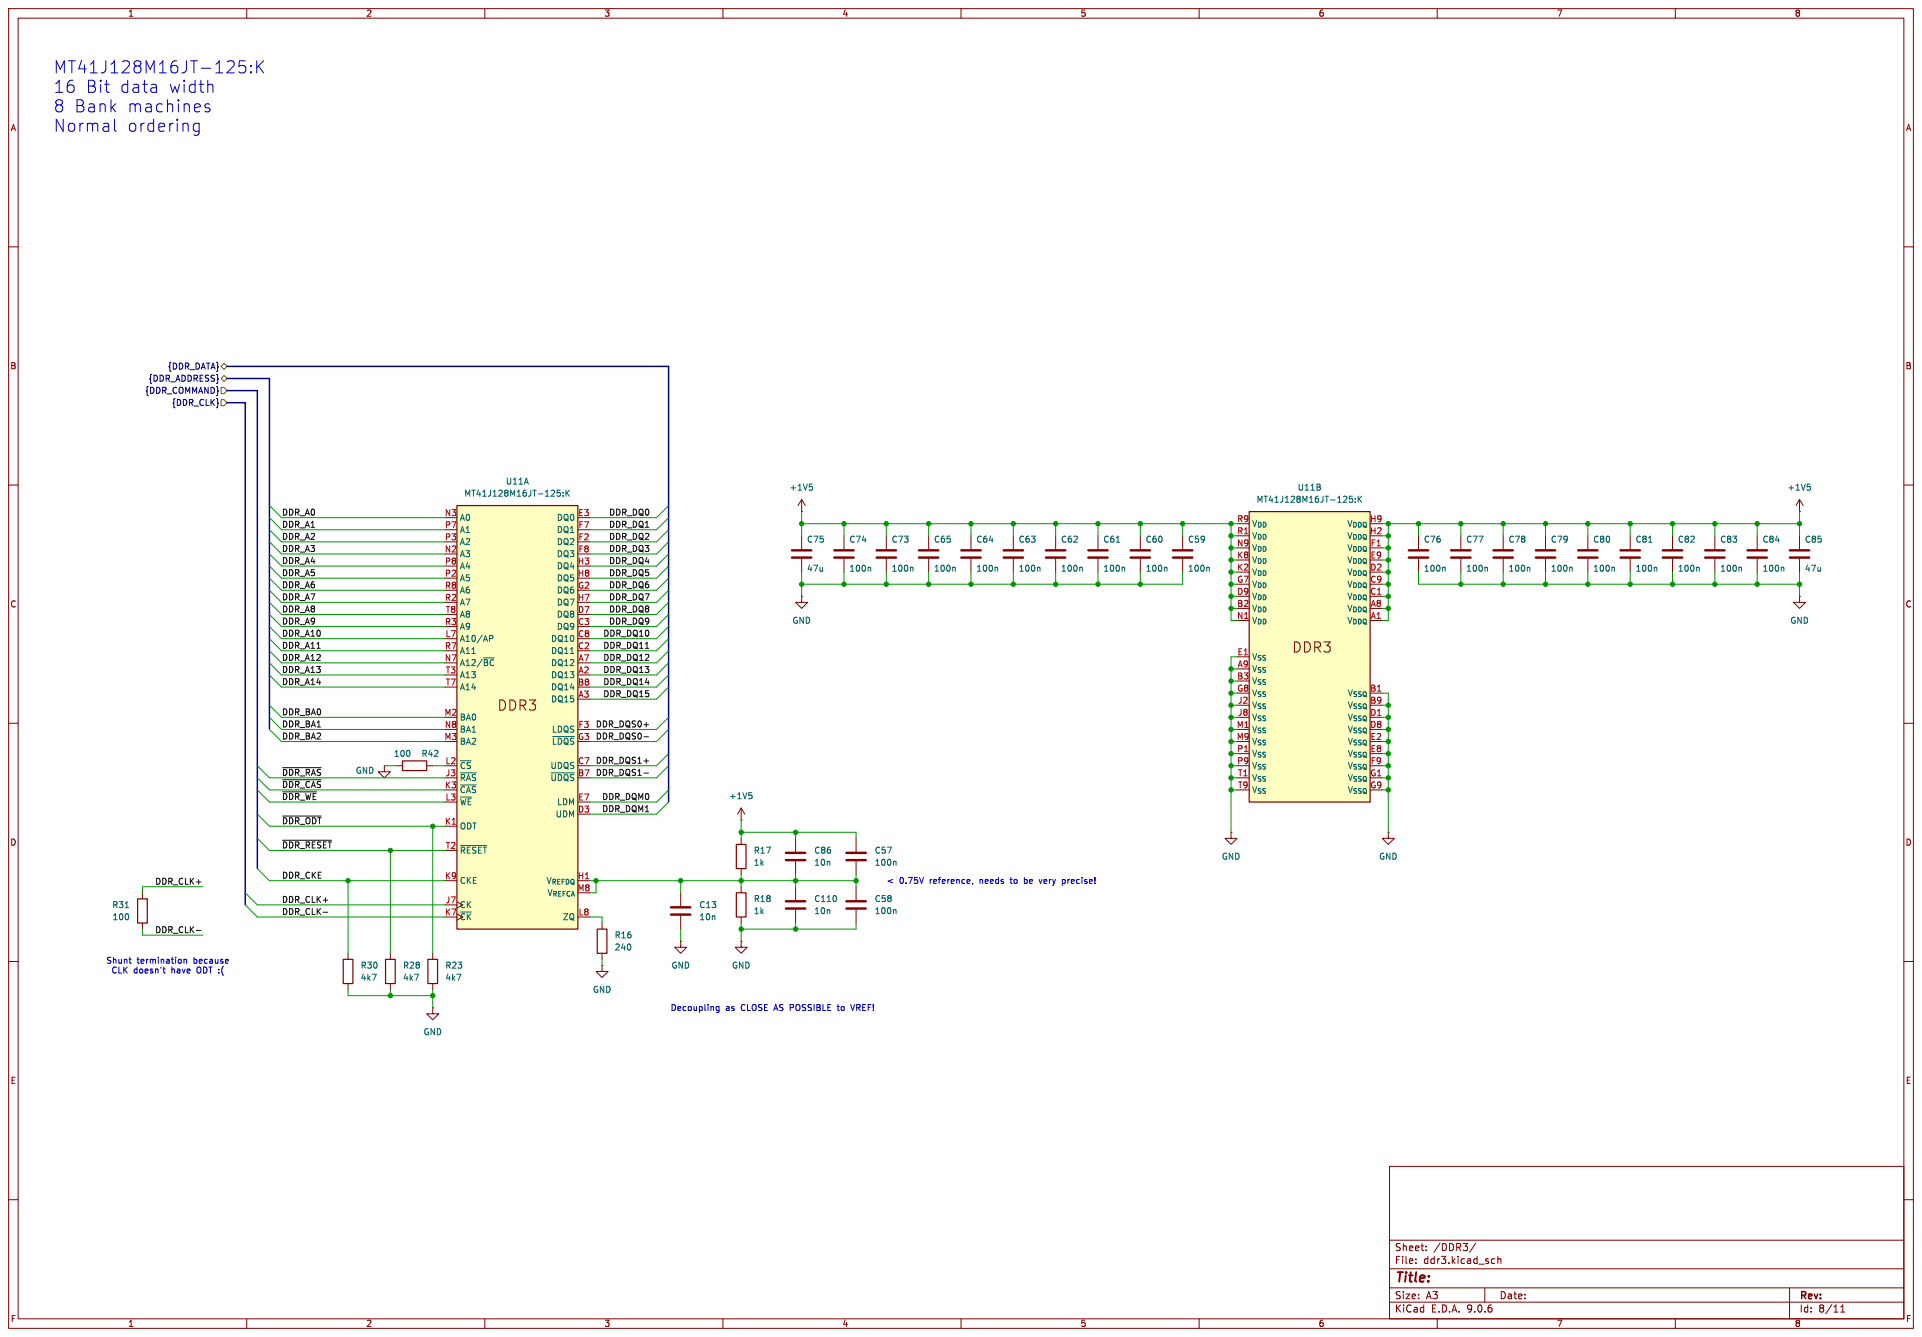
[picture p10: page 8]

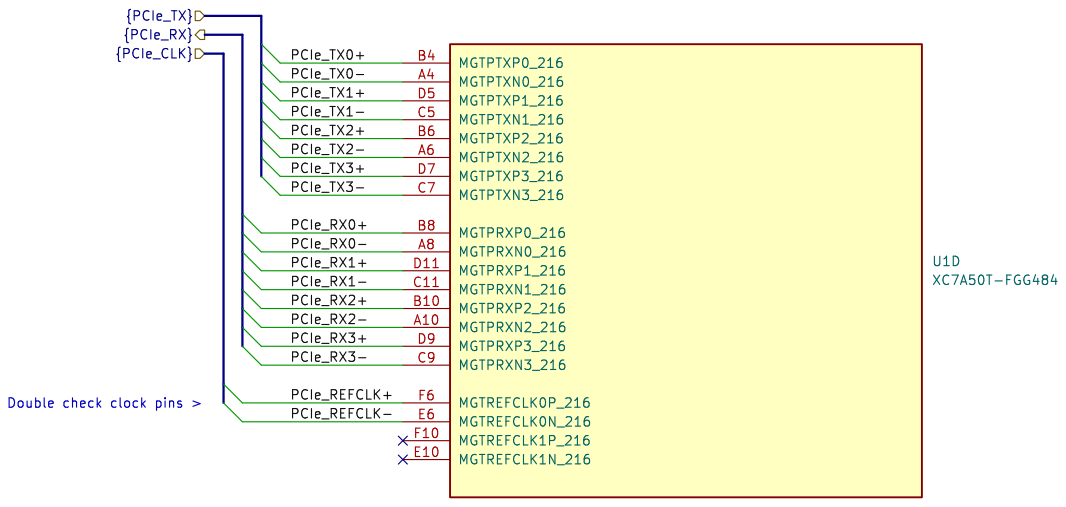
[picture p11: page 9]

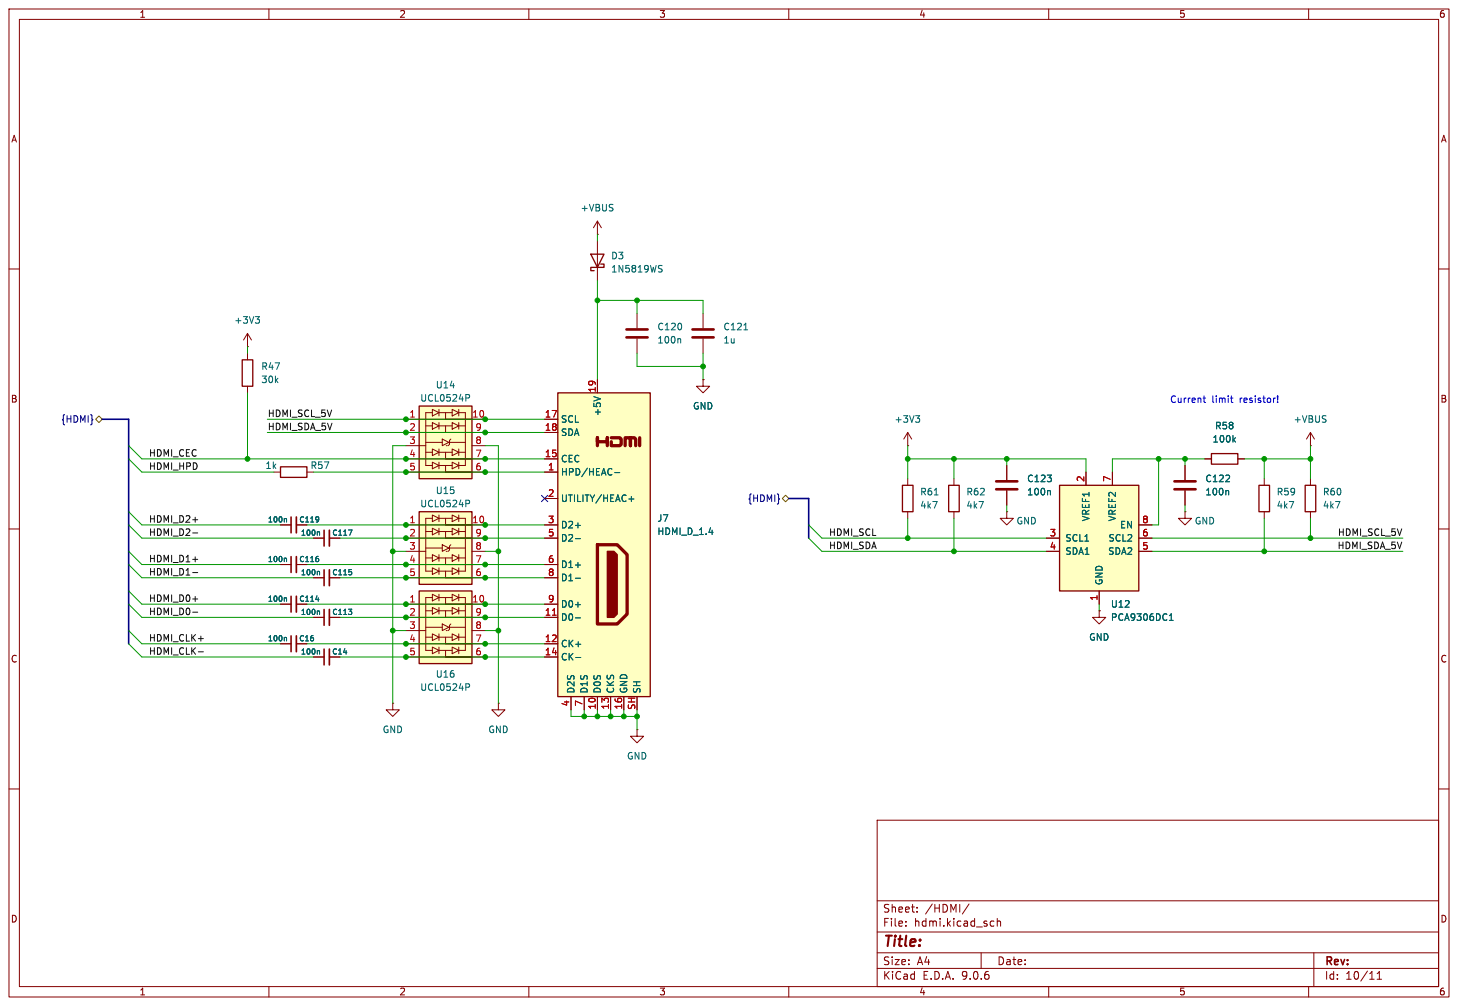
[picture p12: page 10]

7 +5V 19 D0S 10 CKS 13 GND 16 SH SH

7 +5V 19 D0S 10 CKS 13 GND 16 SH SH GND

Id: 10/11 Title: File: hdmi.kicad_sch Sheet: /HDMI/

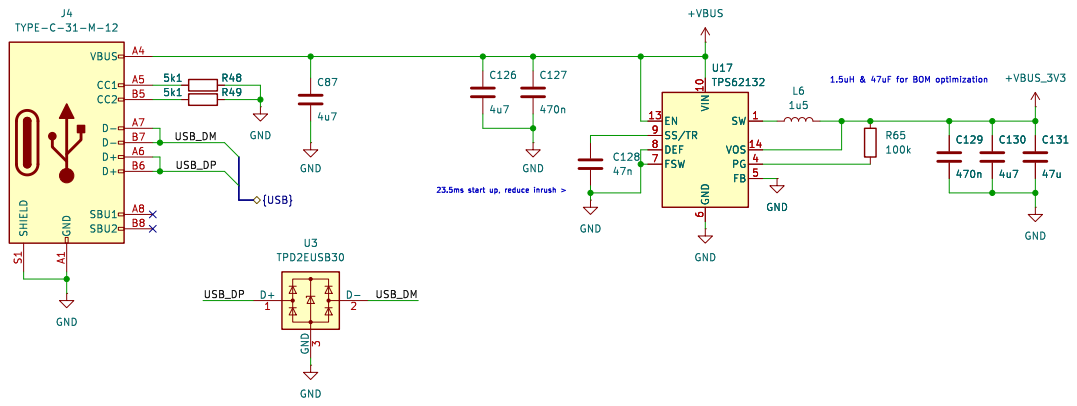
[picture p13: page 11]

6 SW 1 VOS 14 PG 4 FB 5 U17 TPS62132 D+

6 SW 1 VOS 14 PG 4 FB 5

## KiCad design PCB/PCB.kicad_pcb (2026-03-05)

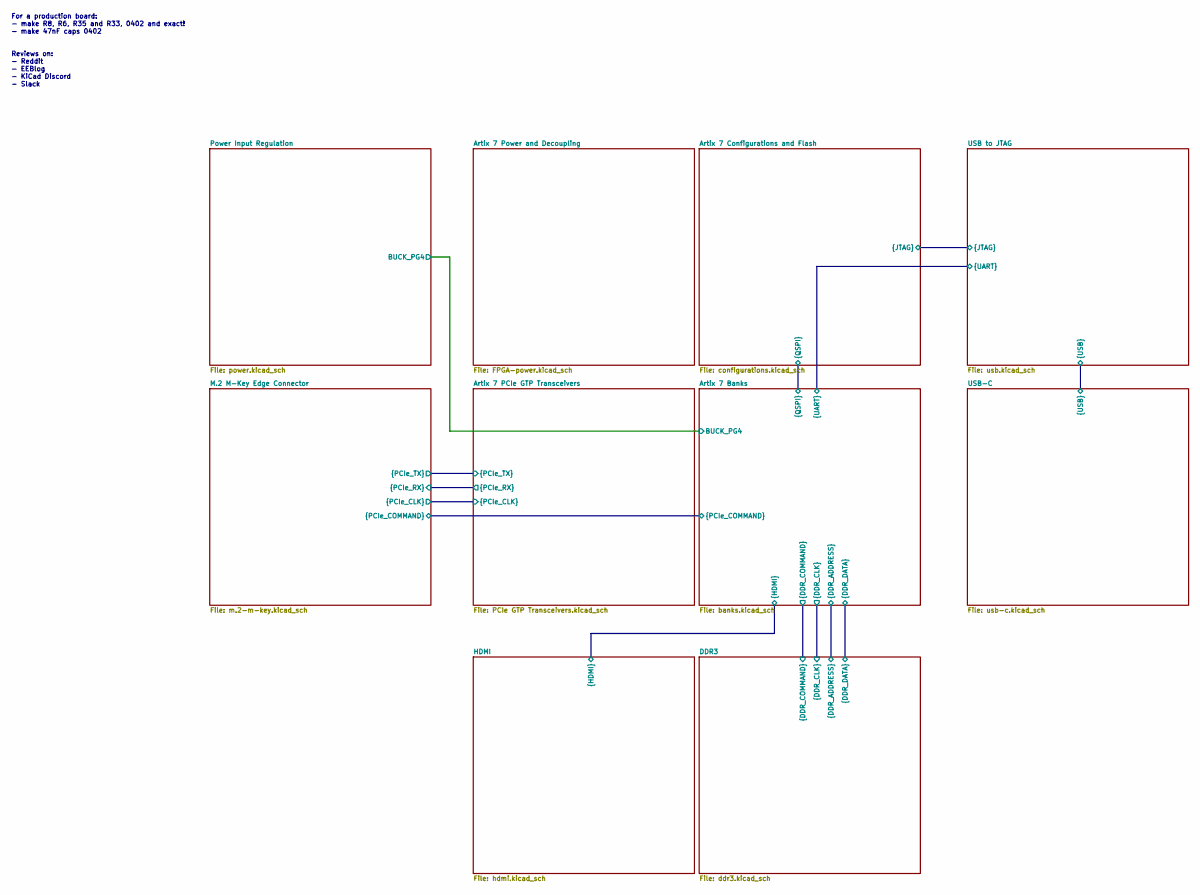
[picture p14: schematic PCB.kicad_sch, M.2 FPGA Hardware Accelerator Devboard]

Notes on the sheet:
For a production board: - make R8, R6, R35 and R33, 0402 and exact! - make 47nF caps 0402
Reviews on: - Reddit - EEBlog - KiCad Discord - Slack

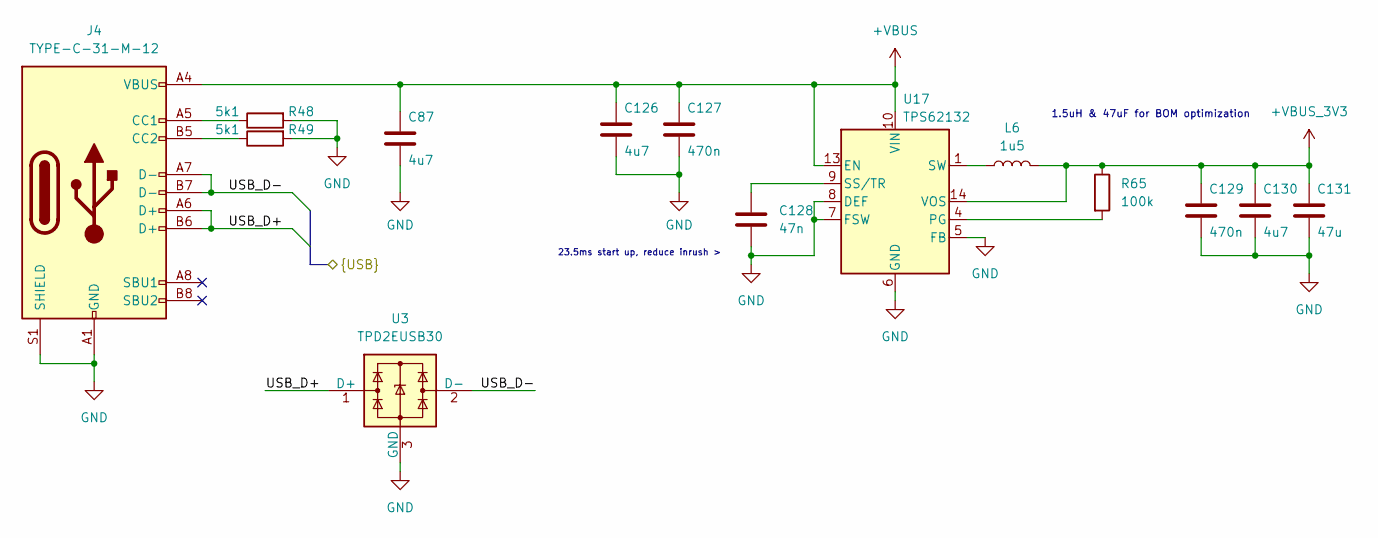
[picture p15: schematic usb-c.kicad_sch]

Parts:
C87, C126, C130: 4u7; C_0603_1608Metric
C127, C129: 470n; C_0201_0603Metric
C128: 47n; C_0603_1608Metric
C131: 47u; C_1206_3216Metric
J4: TYPE-C-31-M-12; USB_C_Receptacle_HRO_TYPE-C-31-M-12; MPN TYPE-C-31-M-12; LCSC C165948
L6: 1u5; L_Sunlord_SWPA4030S; MPN SWPA4030S1R5NT; LCSC C42100
R48, R49: 5k1; R_0402_1005Metric
R65: 100k; R_0402_1005Metric
U3: TPD2EUSB30; Texas_DRT-3
U17: TPS62132; VQFN-16-1EP_3x3mm_P0.5mm_EP1.68x1.68mm_ThermalVias

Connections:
+VBUS: C87.1, C126.1, C127.1, J4.A4 (VBUS), J4.A9 (VBUS), J4.B4 (VBUS), J4.B9 (VBUS), U17.10 (VIN), U17.11 (VIN), U17.12 (VIN), U17.13 (EN); also elsewhere on the board
+VBUS_3V3: C129.1, C130.1, C131.1, L6.2, R65.1, U17.14 (VOS); also elsewhere on the board
/USB to JTAG/USB_D+: J4.A6 (D+), J4.B6 (D+), U3.1 (D+); also elsewhere on the board
/USB to JTAG/USB_D-: J4.A7 (D-), J4.B7 (D-), U3.2 (D-); also elsewhere on the board
GND: C87.2, C126.2, C127.2, C128.2, C129.2, C130.2, C131.2, J4.A1 (GND), J4.A12 (GND), J4.B1 (GND), J4.B12 (GND), J4.S1 (SHIELD), R48.2, R49.2, U3.3 (GND), U17.5 (FB), U17.6 (GND), U17.7 (FSW), U17.8 (DEF), U17.15 (GND), U17.16 (GND), U17.17 (GND); also elsewhere on the board
unnamed: J4.A5 (CC1), R48.1
unnamed: J4.B5 (CC2), R49.1
unnamed: L6.1, U17.1 (SW), U17.2 (SW), U17.3 (SW)
unnamed: R65.2, U17.4 (PG)
unnamed: C128.1, U17.9 (SS/TR)

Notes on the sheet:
23.5ms start up, reduce inrush >
1.5uH & 47uF for BOM optimization

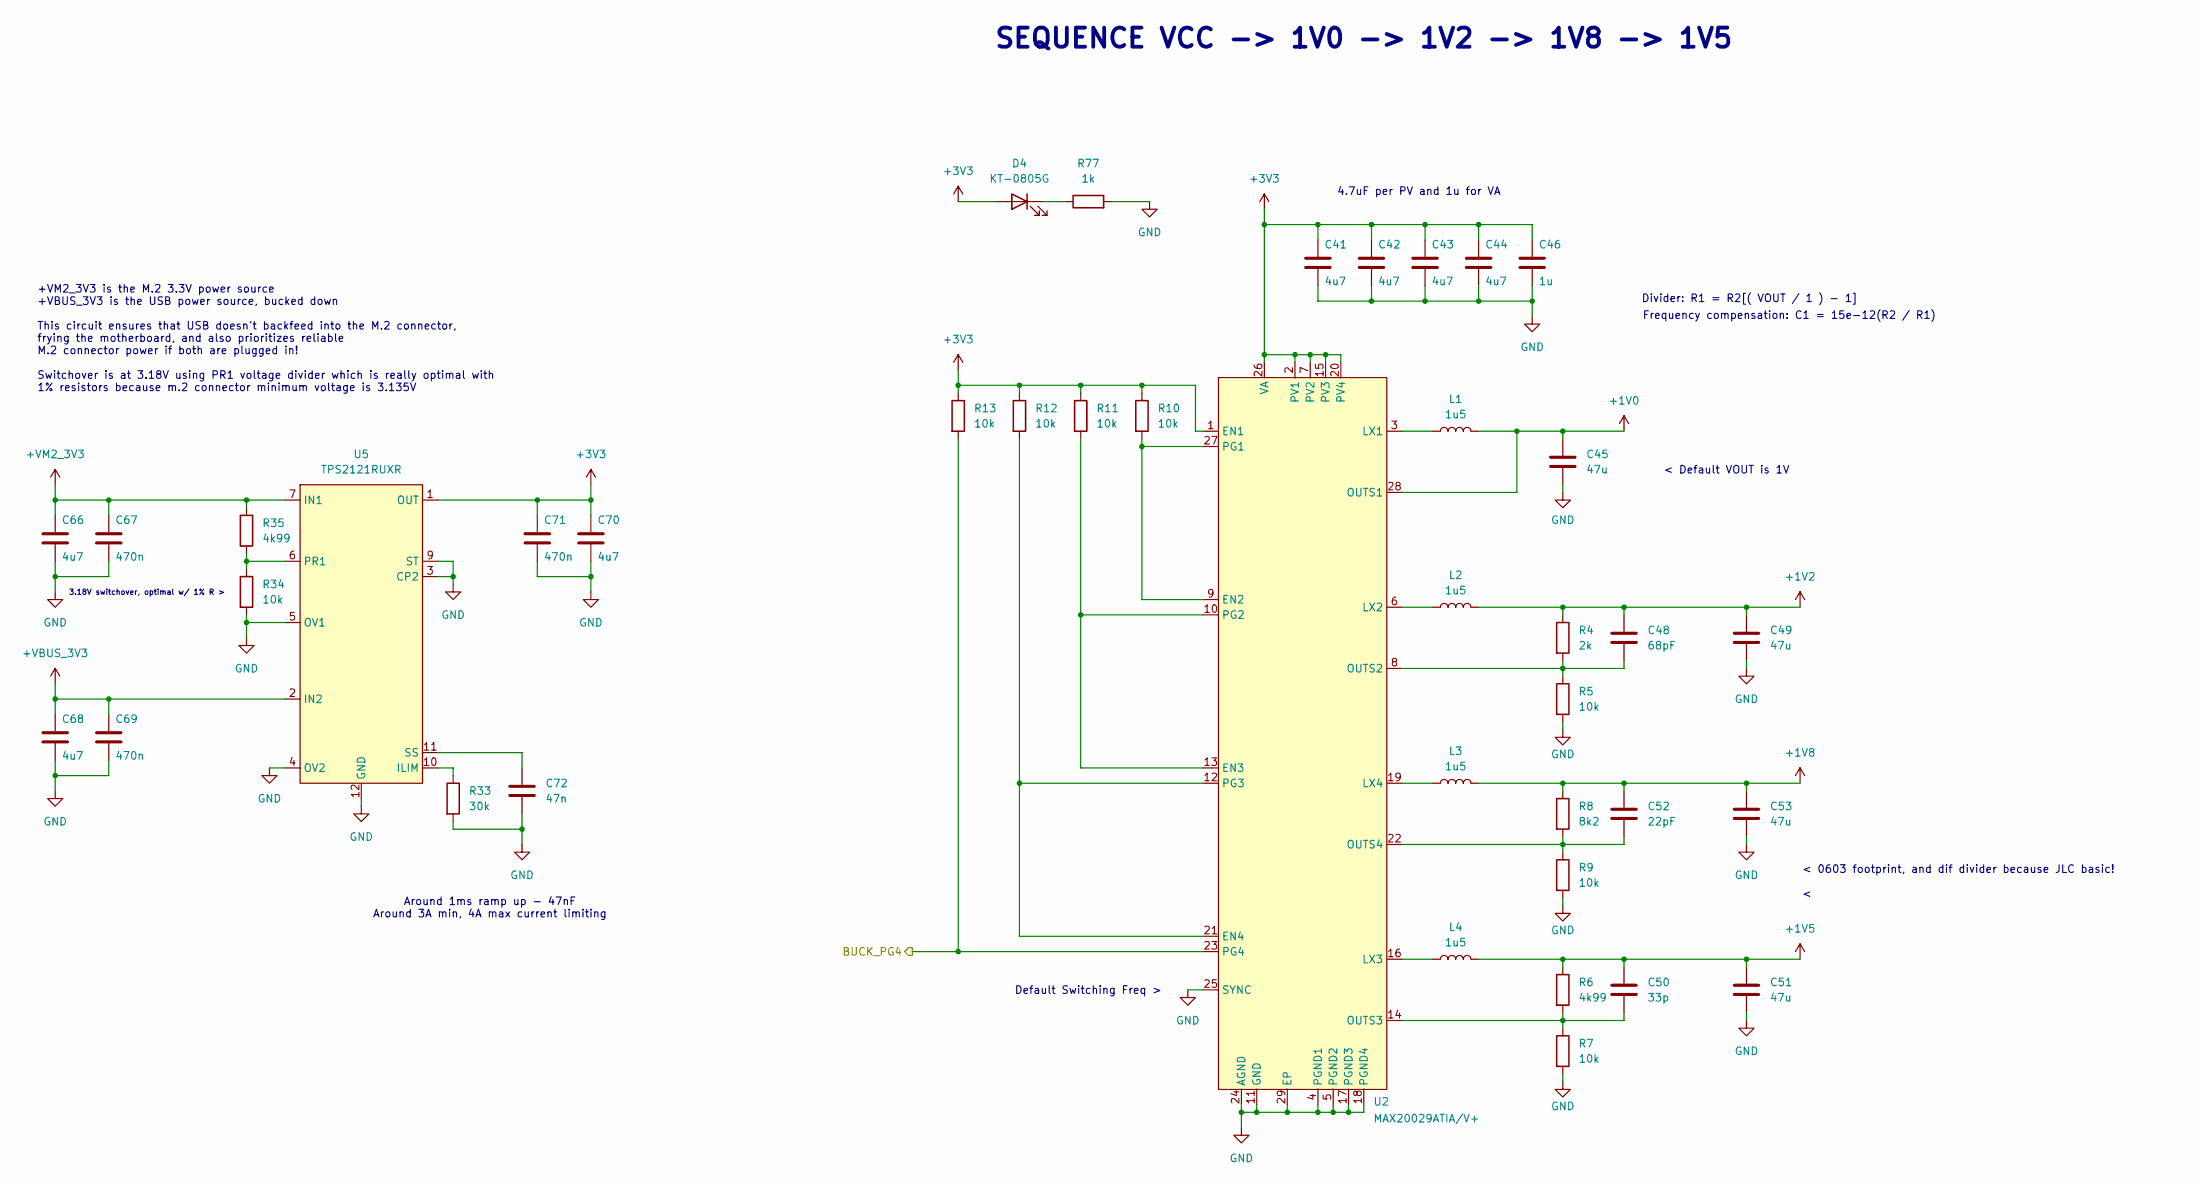
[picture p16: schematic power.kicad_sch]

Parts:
C41, C42, C43, C44, C66, C68, C70: 4u7; C_0603_1608Metric
C45, C49, C51, C53: 47u; C_1206_3216Metric
C46: 1u; C_0402_1005Metric
C48: 68pF; C_0402_1005Metric
C50: 33p; C_0402_1005Metric
C52: 22pF; C_0402_1005Metric
C67, C69, C71: 470n; C_0201_0603Metric
C72: 47n; C_0603_1608Metric
D4: KT-0805G; LED_0805_2012Metric; MPN KT-0805G; LCSC C2297
L1, L2, L3, L4: 1u5; L_Sunlord_SWPA4030S; MPN SWPA4030S1R5NT; LCSC C42100
R4: 2k; R_0402_1005Metric
R5, R7, R9, R10, R11, R12, R13, R34: 10k; R_0402_1005Metric
R6, R35: 4k99; R_0603_1608Metric
R8: 8k2; R_0603_1608Metric
R33: 30k; R_0603_1608Metric
R77: 1k; R_0402_1005Metric
U2: MAX20029ATIA/V+; QFN-28_L5.0-W5.0-P0.50-TL-EP3.2; LCSC Part C1235515
U5: TPS2121RUXR; Texas_VQFN-HR-12_2x2.5mm_P0.5mm_ThermalVias; MPN TPS2121RUXR; LCSC C485916

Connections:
+1V0: C45.1, L1.2, U2.28 (OUTS1); also elsewhere on the board
+1V2: C48.1, C49.1, L2.2, R4.1; also elsewhere on the board
+1V5: C50.1, C51.1, L4.2, R6.1; also elsewhere on the board
+1V8: C52.1, C53.1, L3.2, R8.1; also elsewhere on the board
+3V3: C41.1, C42.1, C43.1, C44.1, C46.1, C70.1, C71.1, D4.2 (A), R10.1, R11.1, R12.1, R13.1, U2.1 (EN1), U2.2 (PV1), U2.7 (PV2), U2.15 (PV3), U2.20 (PV4), U2.26 (VA), U5.1 (OUT), U5.8 (OUT); also elsewhere on the board
+VBUS_3V3: C68.1, C69.1, U5.2 (IN2); also elsewhere on the board
+VM2_3V3: C66.1, C67.1, R35.1, U5.7 (IN1); also elsewhere on the board
/Artix 7 Banks/BUCK_PG4: R13.2, U2.23 (PG4); also elsewhere on the board
GND: C41.2, C42.2, C43.2, C44.2, C45.2, C46.2, C49.2, C51.2, C53.2, C66.2, C67.2, C68.2, C69.2, C70.2, C71.2, C72.2, R5.2, R7.2, R9.2, R33.2, R34.2, R77.2, U2.4 (PGND1), U2.5 (PGND2), U2.11 (GND), U2.17 (PGND3), U2.18 (PGND4), U2.24 (AGND), U2.25 (SYNC), U2.29 (EP), U5.3 (CP2), U5.4 (OV2), U5.5 (OV1), U5.9 (ST), U5.12 (GND); also elsewhere on the board
unnamed: D4.1 (K), R77.1
unnamed: R10.2, U2.9 (EN2), U2.27 (PG1)
unnamed: R11.2, U2.10 (PG2), U2.13 (EN3)
unnamed: R12.2, U2.12 (PG3), U2.21 (EN4)
unnamed: L1.1, U2.3 (LX1)
unnamed: L2.1, U2.6 (LX2)
unnamed: L4.1, U2.16 (LX3)
unnamed: L3.1, U2.19 (LX4)
unnamed: C48.2, R4.2, R5.1, U2.8 (OUTS2)
unnamed: C50.2, R6.2, R7.1, U2.14 (OUTS3)
unnamed: C52.2, R8.2, R9.1, U2.22 (OUTS4)
unnamed: R33.1, U5.10 (ILIM)
unnamed: R34.1, R35.2, U5.6 (PR1)
unnamed: C72.1, U5.11 (SS)

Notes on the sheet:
Default Switching Freq >
Divider: R1 = R2[( VOUT / 1 ) − 1]
4.7uF per PV and 1u for VA
< 0603 footprint, and dif divider because JLC basic! <
Around 1ms ramp up - 47nF Around 3A min, 4A max current limiting
Frequency compensation: C1 = 15e-12(R2 / R1)
SEQUENCE VCC -> 1V0 -> 1V2 -> 1V8 -> 1V5
+VM2_3V3 is the M.2 3.3V power source +VBUS_3V3 is the USB power source, bucked down This circuit ensures that USB doesn't backfeed into the M.2 connector, frying the motherboard, and also prioritizes reliable M.2 connector power if both are plugged in! Switchover is at 3.18V using PR1 voltage divi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
< Default VOUT is 1V
3.18V switchover, optimal w/ 1% R >

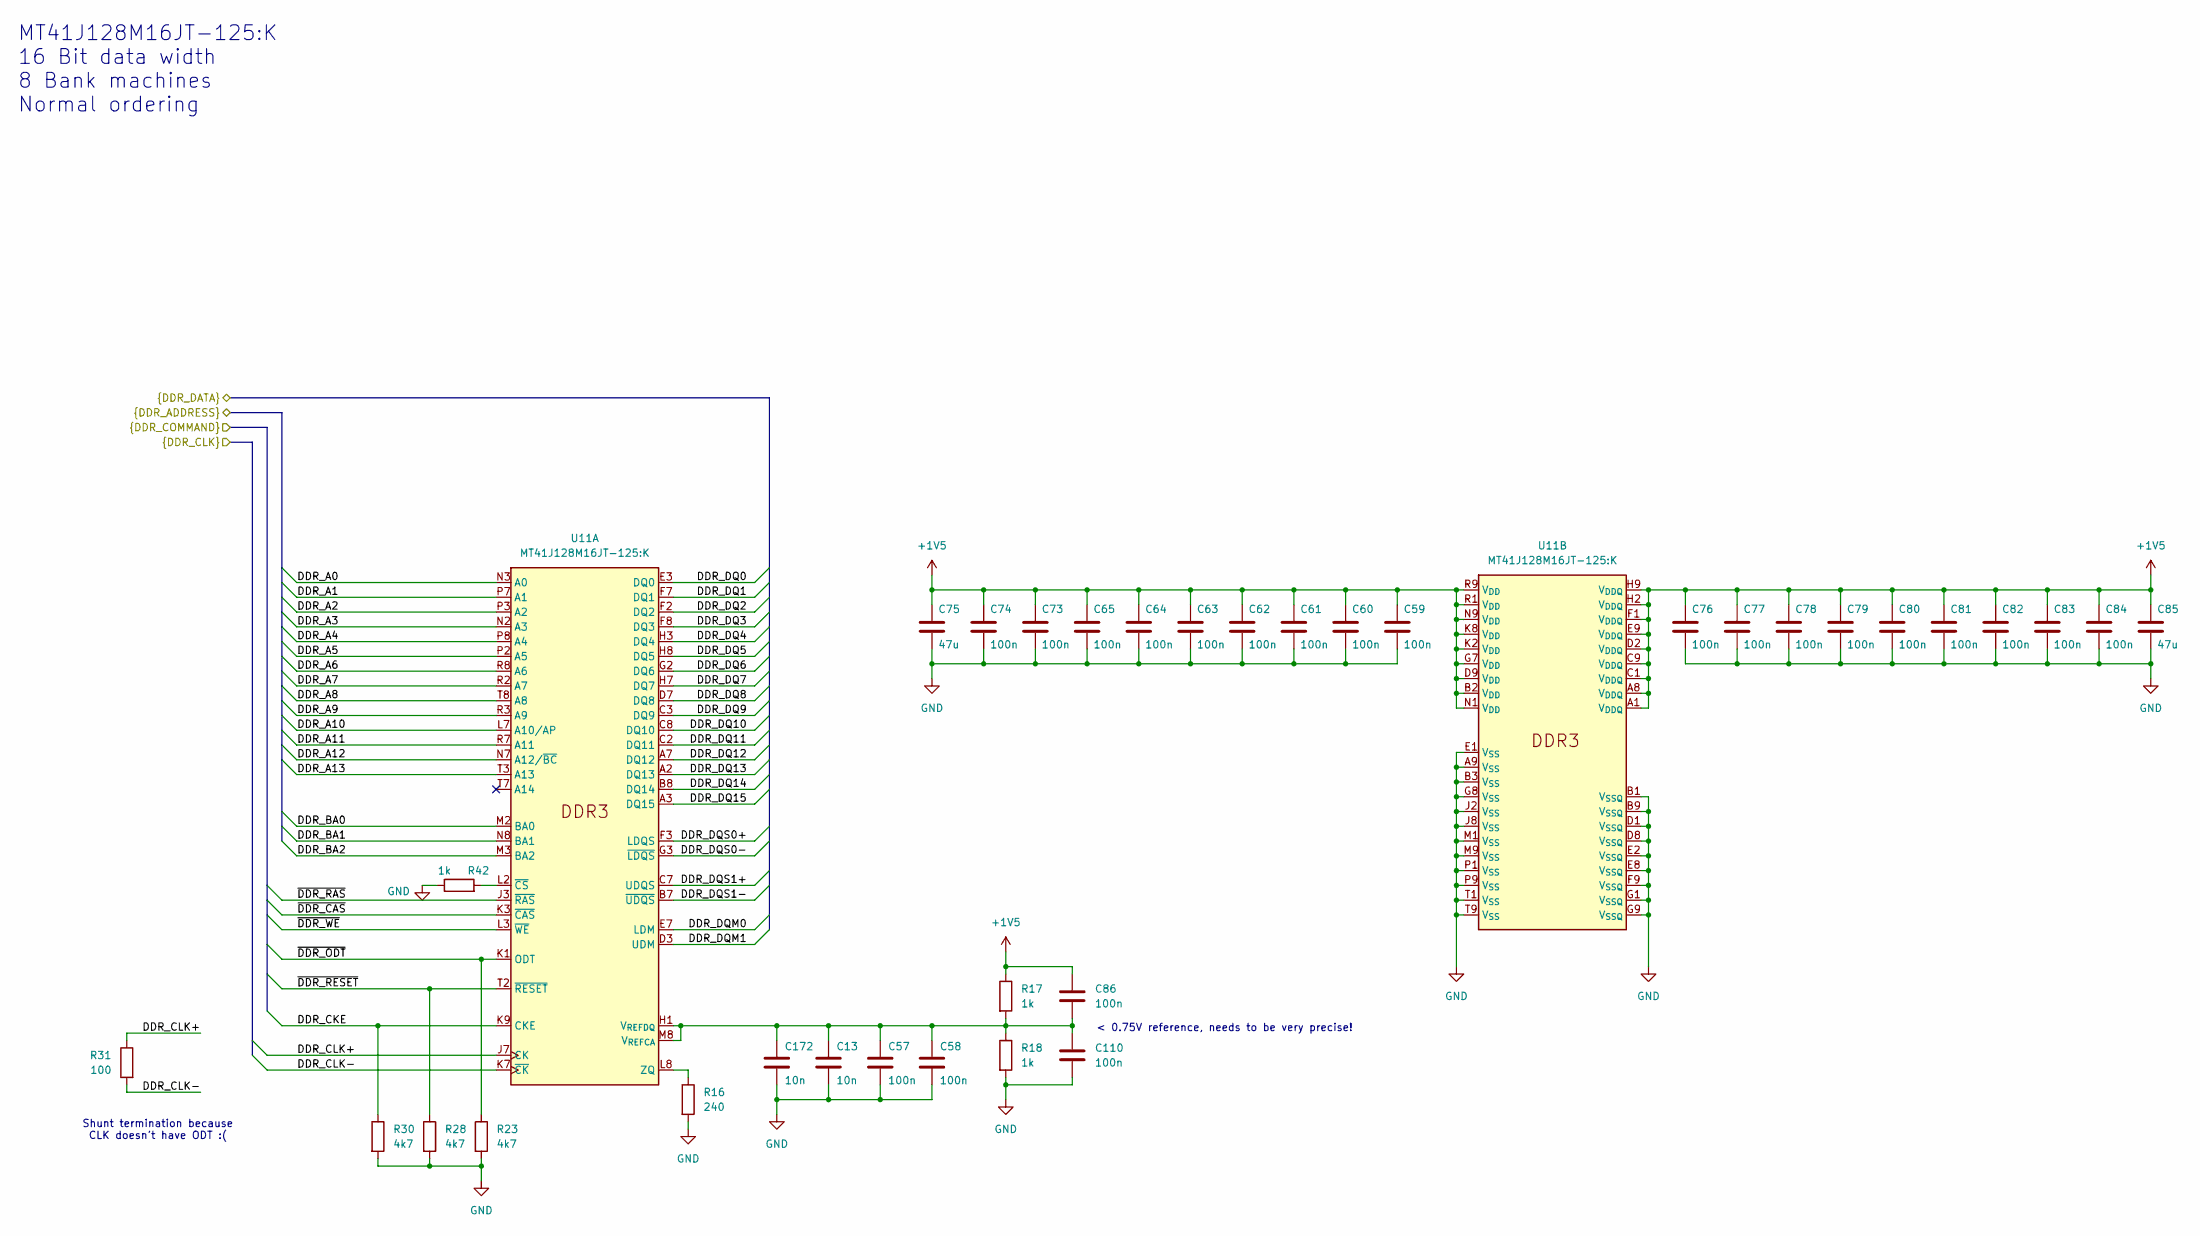
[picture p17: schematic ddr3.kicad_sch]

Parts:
C13, C172: 10n; C_0402_1005Metric
C57, C58, C59, C60, C61, C62, C63, C64, C65, C73, C74, C76, C77, C78, C79, C80, C81, C82, C83, C84, C86, C110: 100n; C_0402_1005Metric
C75, C85: 47u; C_1206_3216Metric
R16: 240; R_0402_1005Metric
R17, R18, R42: 1k; R_0402_1005Metric
R23, R28, R30: 4k7; R_0402_1005Metric
R31: 100; R_0402_1005Metric
U11: MT41J128M16JT-125:K; FBGA-96_8x14mm_Layout9x16_P0.8mm; MPN MT41J128M16JT-125:K; LCSC C426885

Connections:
+1V5: C59.1, C60.1, C61.1, C62.1, C63.1, C64.1, C65.1, C73.1, C74.1, C75.1, C76.1, C77.1, C78.1, C79.1, C80.1, C81.1, C82.1, C83.1, C84.1, C85.1, C86.1, R17.1, U11.A1 (V_{DDQ}), U11.A8 (V_{DDQ}), U11.B2 (V_{DD}), U11.C1 (V_{DDQ}), U11.C9 (V_{DDQ}), U11.D2 (V_{DDQ}), U11.D9 (V_{DD}), U11.E9 (V_{DDQ}), U11.F1 (V_{DDQ}), U11.G7 (V_{DD}), U11.H2 (V_{DDQ}), U11.H9 (V_{DDQ}), U11.K2 (V_{DD}), U11.K8 (V_{DD}), U11.N1 (V_{DD}), U11.N9 (V_{DD}), U11.R1 (V_{DD}), U11.R9 (V_{DD}); also elsewhere on the board
/Artix 7 Banks/DDR_A0: U11.N3 (A0); also elsewhere on the board
/Artix 7 Banks/DDR_A1: U11.P7 (A1); also elsewhere on the board
/Artix 7 Banks/DDR_A2: U11.P3 (A2); also elsewhere on the board
/Artix 7 Banks/DDR_A3: U11.N2 (A3); also elsewhere on the board
/Artix 7 Banks/DDR_A4: U11.P8 (A4); also elsewhere on the board
/Artix 7 Banks/DDR_A5: U11.P2 (A5); also elsewhere on the board
/Artix 7 Banks/DDR_A6: U11.R8 (A6); also elsewhere on the board
/Artix 7 Banks/DDR_A7: U11.R2 (A7); also elsewhere on the board
/Artix 7 Banks/DDR_A8: U11.T8 (A8); also elsewhere on the board
/Artix 7 Banks/DDR_A9: U11.R3 (A9); also elsewhere on the board
/Artix 7 Banks/DDR_A10: U11.L7 (A10/AP); also elsewhere on the board
/Artix 7 Banks/DDR_A11: U11.R7 (A11); also elsewhere on the board
/Artix 7 Banks/DDR_A12: U11.N7 (A12/~BC); also elsewhere on the board
/Artix 7 Banks/DDR_A13: U11.T3 (A13); also elsewhere on the board
/Artix 7 Banks/DDR_BA0: U11.M2 (BA0); also elsewhere on the board
/Artix 7 Banks/DDR_BA1: U11.N8 (BA1); also elsewhere on the board
/Artix 7 Banks/DDR_BA2: U11.M3 (BA2); also elsewhere on the board
/Artix 7 Banks/DDR_CKE: R30.1, U11.K9 (CKE); also elsewhere on the board
/Artix 7 Banks/DDR_CLK+: R31.1, U11.J7 (CK); also elsewhere on the board
/Artix 7 Banks/DDR_CLK-: R31.2, U11.K7 (~CK); also elsewhere on the board
/Artix 7 Banks/DDR_DQ0: U11.E3 (DQ0); also elsewhere on the board
/Artix 7 Banks/DDR_DQ1: U11.F7 (DQ1); also elsewhere on the board
/Artix 7 Banks/DDR_DQ2: U11.F2 (DQ2); also elsewhere on the board
/Artix 7 Banks/DDR_DQ3: U11.F8 (DQ3); also elsewhere on the board
/Artix 7 Banks/DDR_DQ4: U11.H3 (DQ4); also elsewhere on the board
/Artix 7 Banks/DDR_DQ5: U11.H8 (DQ5); also elsewhere on the board
/Artix 7 Banks/DDR_DQ6: U11.G2 (DQ6); also elsewhere on the board
/Artix 7 Banks/DDR_DQ7: U11.H7 (DQ7); also elsewhere on the board
/Artix 7 Banks/DDR_DQ8: U11.D7 (DQ8); also elsewhere on the board
/Artix 7 Banks/DDR_DQ9: U11.C3 (DQ9); also elsewhere on the board
/Artix 7 Banks/DDR_DQ10: U11.C8 (DQ10); also elsewhere on the board
/Artix 7 Banks/DDR_DQ11: U11.C2 (DQ11); also elsewhere on the board
/Artix 7 Banks/DDR_DQ12: U11.A7 (DQ12); also elsewhere on the board
/Artix 7 Banks/DDR_DQ13: U11.A2 (DQ13); also elsewhere on the board
/Artix 7 Banks/DDR_DQ14: U11.B8 (DQ14); also elsewhere on the board
/Artix 7 Banks/DDR_DQ15: U11.A3 (DQ15); also elsewhere on the board
/Artix 7 Banks/DDR_DQM0: U11.E7 (LDM); also elsewhere on the board
/Artix 7 Banks/DDR_DQM1: U11.D3 (UDM); also elsewhere on the board
/Artix 7 Banks/DDR_DQS0+: U11.F3 (LDQS); also elsewhere on the board
/Artix 7 Banks/DDR_DQS0-: U11.G3 (~LDQS); also elsewhere on the board
/Artix 7 Banks/DDR_DQS1+: U11.C7 (UDQS); also elsewhere on the board
/Artix 7 Banks/DDR_DQS1-: U11.B7 (~UDQS); also elsewhere on the board
/Artix 7 Banks/~DDR_CAS: U11.K3 (~CAS); also elsewhere on the board
/Artix 7 Banks/~DDR_ODT: R23.1, U11.K1 (ODT); also elsewhere on the board
/Artix 7 Banks/~DDR_RAS: U11.J3 (~RAS); also elsewhere on the board
/Artix 7 Banks/~DDR_RESET: R28.1, U11.T2 (~RESET); also elsewhere on the board
/Artix 7 Banks/~DDR_WE: U11.L3 (~WE); also elsewhere on the board
GND: C13.2, C57.2, C58.2, C59.2, C60.2, C61.2, C62.2, C63.2, C64.2, C65.2, C73.2, C74.2, C75.2, C76.2, C77.2, C78.2, C79.2, C80.2, C81.2, C82.2, C83.2, C84.2, C85.2, C110.2, C172.2, R16.2, R18.2, R23.2, R28.2, R30.2, R42.1, U11.A9 (V_{SS}), U11.B1 (V_{SSQ}), U11.B3 (V_{SS}), U11.B9 (V_{SSQ}), U11.D1 (V_{SSQ}), U11.D8 (V_{SSQ}), U11.E1 (V_{SS}), U11.E2 (V_{SSQ}), U11.E8 (V_{SSQ}), U11.F9 (V_{SSQ}), U11.G1 (V_{SSQ}), U11.G8 (V_{SS}), U11.G9 (V_{SSQ}), U11.J2 (V_{SS}), U11.J8 (V_{SS}), U11.M1 (V_{SS}), U11.M9 (V_{SS}), U11.P1 (V_{SS}), U11.P9 (V_{SS}), U11.T1 (V_{SS}), U11.T9 (V_{SS}); also elsewhere on the board
unnamed: C13.1, C57.1, C58.1, C86.2, C110.1, C172.1, R17.2, R18.1, U11.H1 (V_{REFDQ}), U11.M8 (V_{REFCA})
unnamed: R16.1, U11.L8 (ZQ)
unnamed: R42.2, U11.L2 (~CS)

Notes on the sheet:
MT41J128M16JT-125:K 16 Bit data width 8 Bank machines Normal ordering
< 0.75V reference, needs to be very precise!
Shunt termination because CLK doesn't have ODT :(

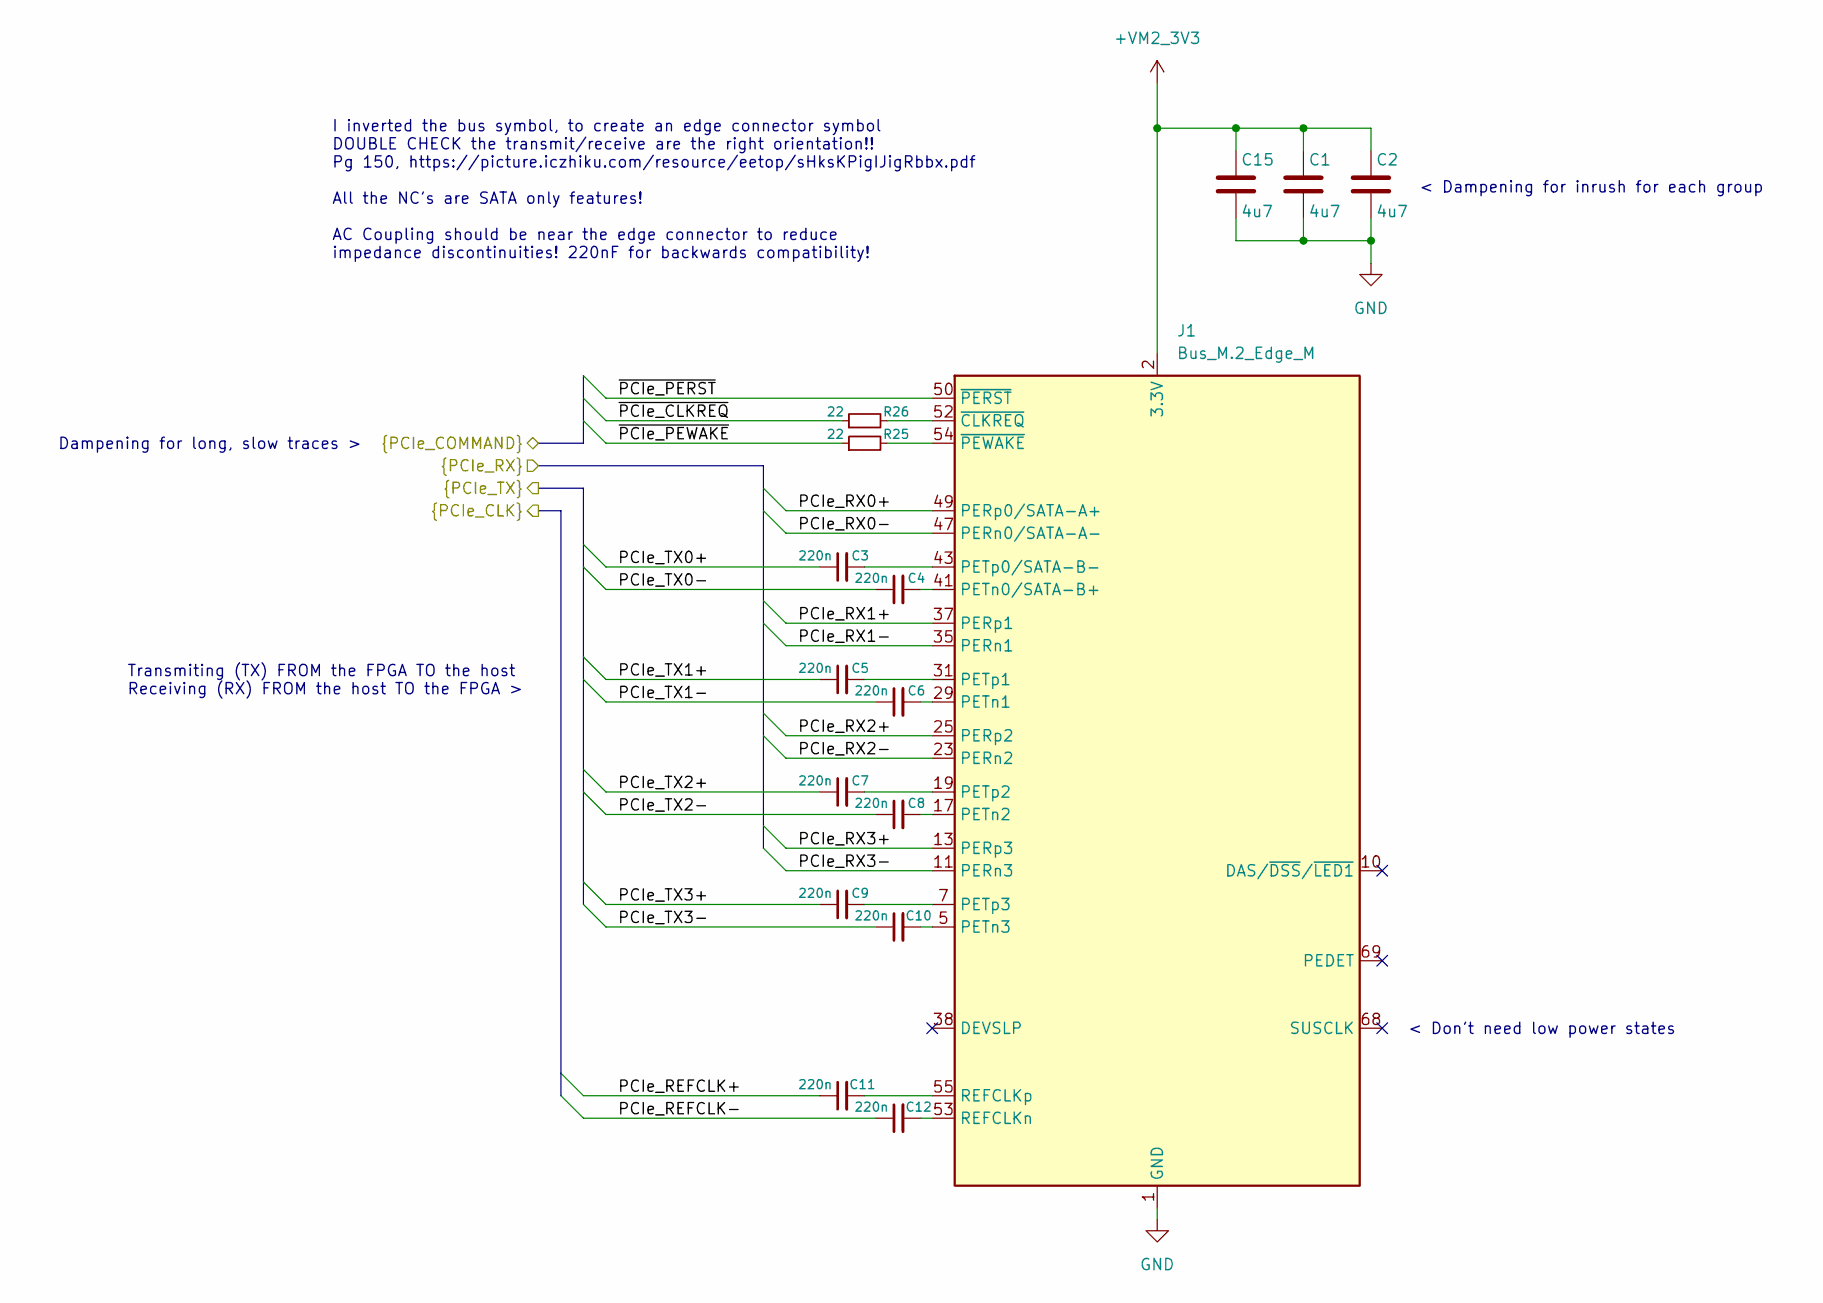
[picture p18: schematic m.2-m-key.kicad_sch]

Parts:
C1, C2, C15: 4u7; C_0603_1608Metric
C3, C4, C5, C6, C7, C8, C9, C10, C11, C12: 220n; C_0402_1005Metric
J1: Bus_M.2_Edge_M; M.2 M-Key 2242
R25, R26: 22; R_0402_1005Metric

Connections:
+VM2_3V3: C1.1, C2.1, C15.1, J1.2 (3.3V), J1.4 (3.3V), J1.12 (3.3V), J1.14 (3.3V), J1.16 (3.3V), J1.18 (3.3V), J1.70 (3.3V), J1.72 (3.3V), J1.74 (3.3V); also elsewhere on the board
/Artix 7 Banks/~PCIe_CLKREQ: R26.1; also elsewhere on the board
/Artix 7 Banks/~PCIe_PERST: J1.50 (~PERST); also elsewhere on the board
/Artix 7 Banks/~PCIe_PEWAKE: R25.1; also elsewhere on the board
/Artix 7 PCIe GTP Transceivers/PCIe_REFCLK+: C11.1; also elsewhere on the board
/Artix 7 PCIe GTP Transceivers/PCIe_REFCLK-: C12.1; also elsewhere on the board
/Artix 7 PCIe GTP Transceivers/PCIe_RX0+: J1.49 (PERp0/SATA-A+); also elsewhere on the board
/Artix 7 PCIe GTP Transceivers/PCIe_RX0-: J1.47 (PERn0/SATA-A-); also elsewhere on the board
/Artix 7 PCIe GTP Transceivers/PCIe_RX1+: J1.37 (PERp1); also elsewhere on the board
/Artix 7 PCIe GTP Transceivers/PCIe_RX1-: J1.35 (PERn1); also elsewhere on the board
/Artix 7 PCIe GTP Transceivers/PCIe_RX2+: J1.25 (PERp2); also elsewhere on the board
/Artix 7 PCIe GTP Transceivers/PCIe_RX2-: J1.23 (PERn2); also elsewhere on the board
/Artix 7 PCIe GTP Transceivers/PCIe_RX3+: J1.13 (PERp3); also elsewhere on the board
/Artix 7 PCIe GTP Transceivers/PCIe_RX3-: J1.11 (PERn3); also elsewhere on the board
/Artix 7 PCIe GTP Transceivers/PCIe_TX0+: C3.1; also elsewhere on the board
/Artix 7 PCIe GTP Transceivers/PCIe_TX0-: C4.1; also elsewhere on the board
/Artix 7 PCIe GTP Transceivers/PCIe_TX1+: C5.1; also elsewhere on the board
/Artix 7 PCIe GTP Transceivers/PCIe_TX1-: C6.1; also elsewhere on the board
/Artix 7 PCIe GTP Transceivers/PCIe_TX2+: C7.1; also elsewhere on the board
/Artix 7 PCIe GTP Transceivers/PCIe_TX2-: C8.1; also elsewhere on the board
/Artix 7 PCIe GTP Transceivers/PCIe_TX3+: C9.1; also elsewhere on the board
/Artix 7 PCIe GTP Transceivers/PCIe_TX3-: C10.1; also elsewhere on the board
GND: C1.2, C2.2, C15.2, J1.1 (GND), J1.3 (GND), J1.9 (GND), J1.15 (GND), J1.21 (GND), J1.27 (GND), J1.33 (GND), J1.39 (GND), J1.45 (GND), J1.51 (GND), J1.57 (GND), J1.71 (GND), J1.73 (GND), J1.75 (GND); also elsewhere on the board
unnamed: C4.2, J1.41 (PETn0/SATA-B+)
unnamed: C6.2, J1.29 (PETn1)
unnamed: C8.2, J1.17 (PETn2)
unnamed: C10.2, J1.5 (PETn3)
unnamed: C3.2, J1.43 (PETp0/SATA-B-)
unnamed: C5.2, J1.31 (PETp1)
unnamed: C7.2, J1.19 (PETp2)
unnamed: C9.2, J1.7 (PETp3)
unnamed: C12.2, J1.53 (REFCLKn)
unnamed: C11.2, J1.55 (REFCLKp)
unnamed: J1.52 (~CLKREQ), R26.2
unnamed: J1.54 (~PEWAKE), R25.2

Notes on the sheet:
Transmiting (TX) FROM the FPGA TO the host Receiving (RX) FROM the host TO the FPGA >
Dampening for long, slow traces >
< Don't need low power states
< Dampening for inrush for each group
I inverted the bus symbol, to create an edge connector symbol DOUBLE CHECK the transmit/receive are the right orientation!! Pg 150, https://picture.iczhiku.com/resource/eetop/sHksKPigIJigRbbx.pdf All the NC's are SATA only features! AC Coupling should be near the edge connector to reduce impedance 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

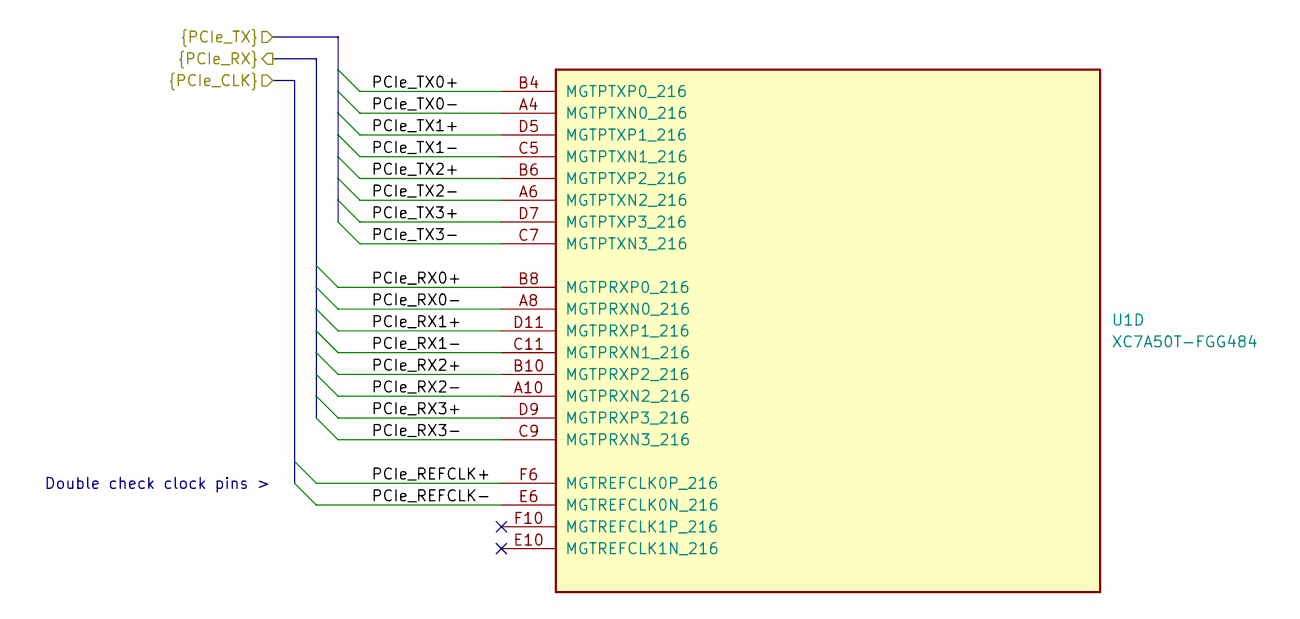
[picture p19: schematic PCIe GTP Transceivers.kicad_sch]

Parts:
U1: XC7A50T-FGG484; Xilinx_FGG484

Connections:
/Artix 7 PCIe GTP Transceivers/PCIe_REFCLK+: U1.F6 (MGTREFCLK0P_216); also elsewhere on the board
/Artix 7 PCIe GTP Transceivers/PCIe_REFCLK-: U1.E6 (MGTREFCLK0N_216); also elsewhere on the board
/Artix 7 PCIe GTP Transceivers/PCIe_RX0+: U1.B8 (MGTPRXP0_216); also elsewhere on the board
/Artix 7 PCIe GTP Transceivers/PCIe_RX0-: U1.A8 (MGTPRXN0_216); also elsewhere on the board
/Artix 7 PCIe GTP Transceivers/PCIe_RX1+: U1.D11 (MGTPRXP1_216); also elsewhere on the board
/Artix 7 PCIe GTP Transceivers/PCIe_RX1-: U1.C11 (MGTPRXN1_216); also elsewhere on the board
/Artix 7 PCIe GTP Transceivers/PCIe_RX2+: U1.B10 (MGTPRXP2_216); also elsewhere on the board
/Artix 7 PCIe GTP Transceivers/PCIe_RX2-: U1.A10 (MGTPRXN2_216); also elsewhere on the board
/Artix 7 PCIe GTP Transceivers/PCIe_RX3+: U1.D9 (MGTPRXP3_216); also elsewhere on the board
/Artix 7 PCIe GTP Transceivers/PCIe_RX3-: U1.C9 (MGTPRXN3_216); also elsewhere on the board
/Artix 7 PCIe GTP Transceivers/PCIe_TX0+: U1.B4 (MGTPTXP0_216); also elsewhere on the board
/Artix 7 PCIe GTP Transceivers/PCIe_TX0-: U1.A4 (MGTPTXN0_216); also elsewhere on the board
/Artix 7 PCIe GTP Transceivers/PCIe_TX1+: U1.D5 (MGTPTXP1_216); also elsewhere on the board
/Artix 7 PCIe GTP Transceivers/PCIe_TX1-: U1.C5 (MGTPTXN1_216); also elsewhere on the board
/Artix 7 PCIe GTP Transceivers/PCIe_TX2+: U1.B6 (MGTPTXP2_216); also elsewhere on the board
/Artix 7 PCIe GTP Transceivers/PCIe_TX2-: U1.A6 (MGTPTXN2_216); also elsewhere on the board
/Artix 7 PCIe GTP Transceivers/PCIe_TX3+: U1.D7 (MGTPTXP3_216); also elsewhere on the board
/Artix 7 PCIe GTP Transceivers/PCIe_TX3-: U1.C7 (MGTPTXN3_216); also elsewhere on the board

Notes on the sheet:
Double check clock pins >

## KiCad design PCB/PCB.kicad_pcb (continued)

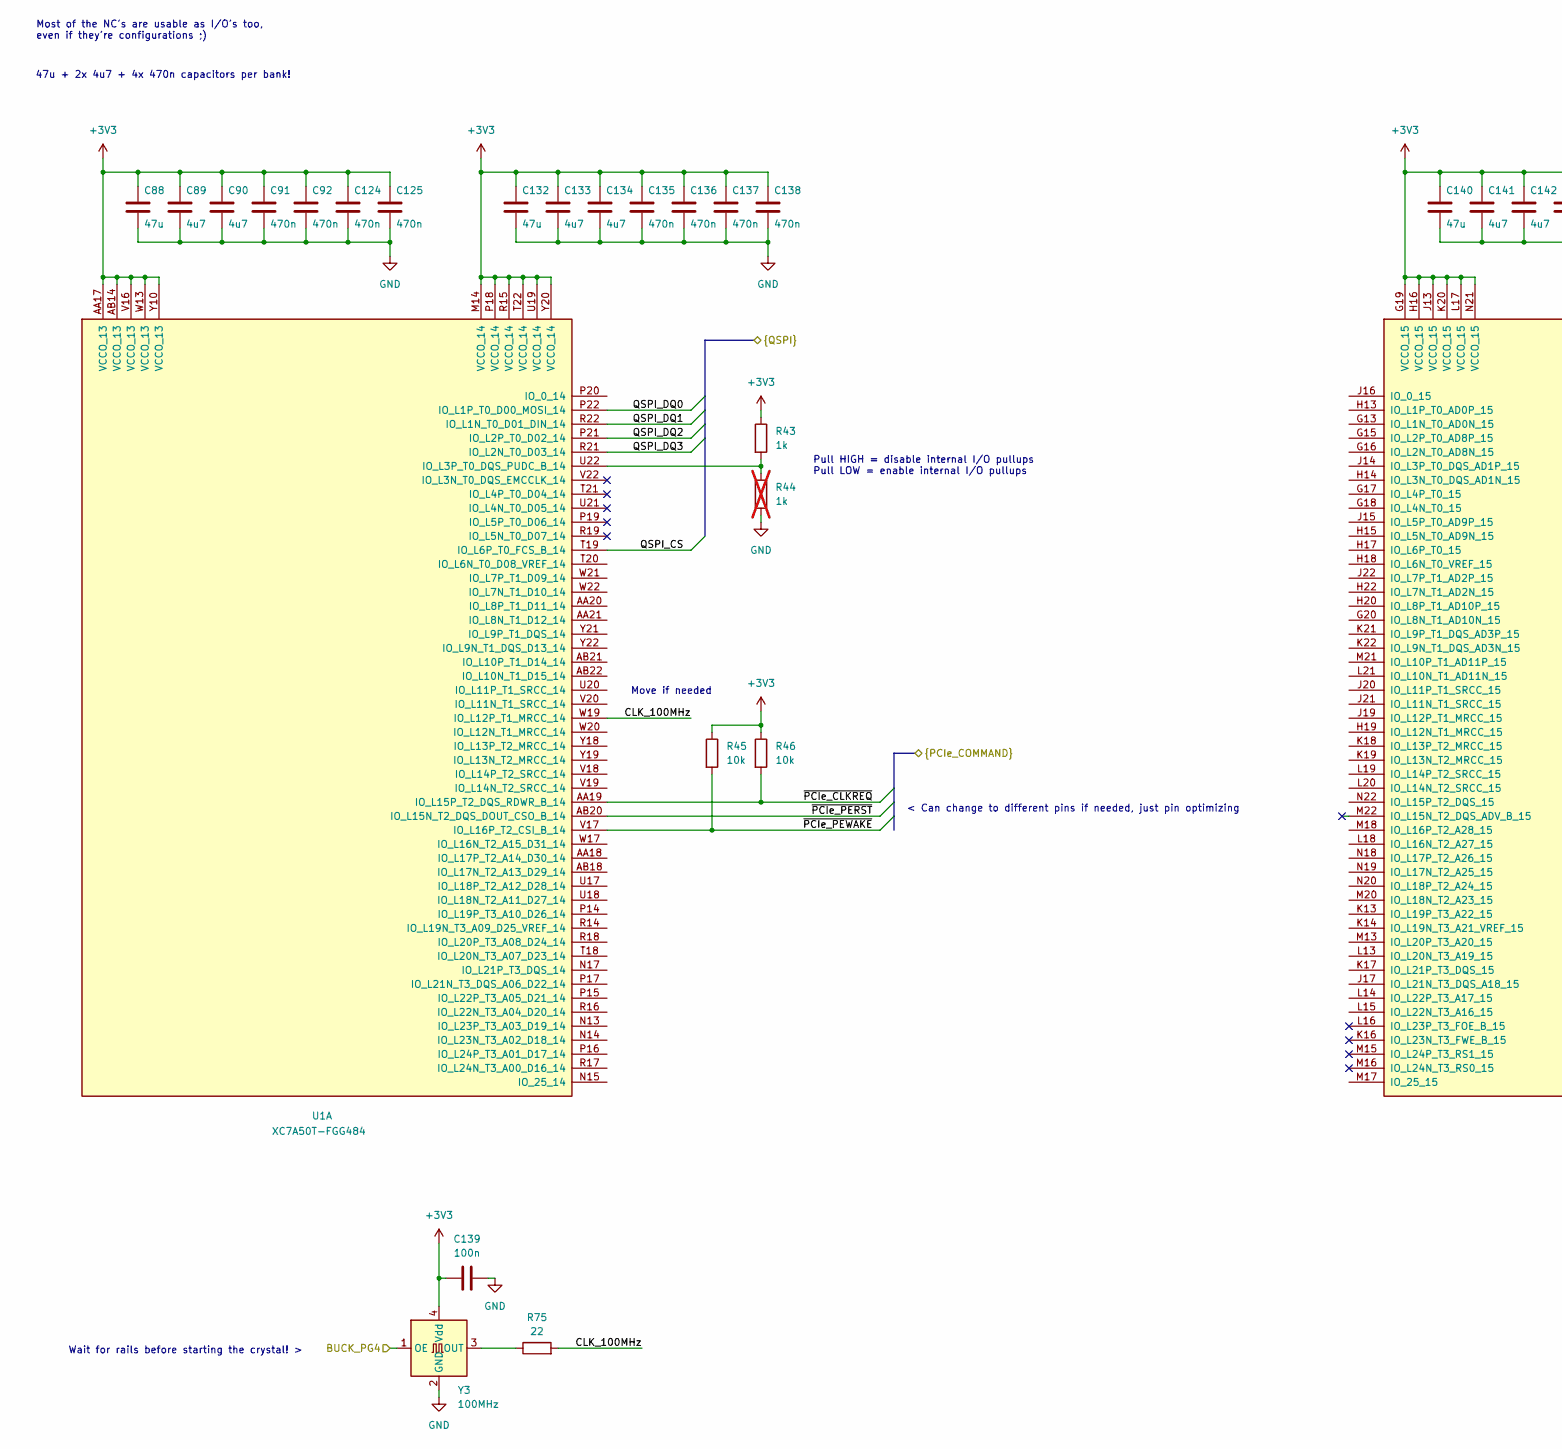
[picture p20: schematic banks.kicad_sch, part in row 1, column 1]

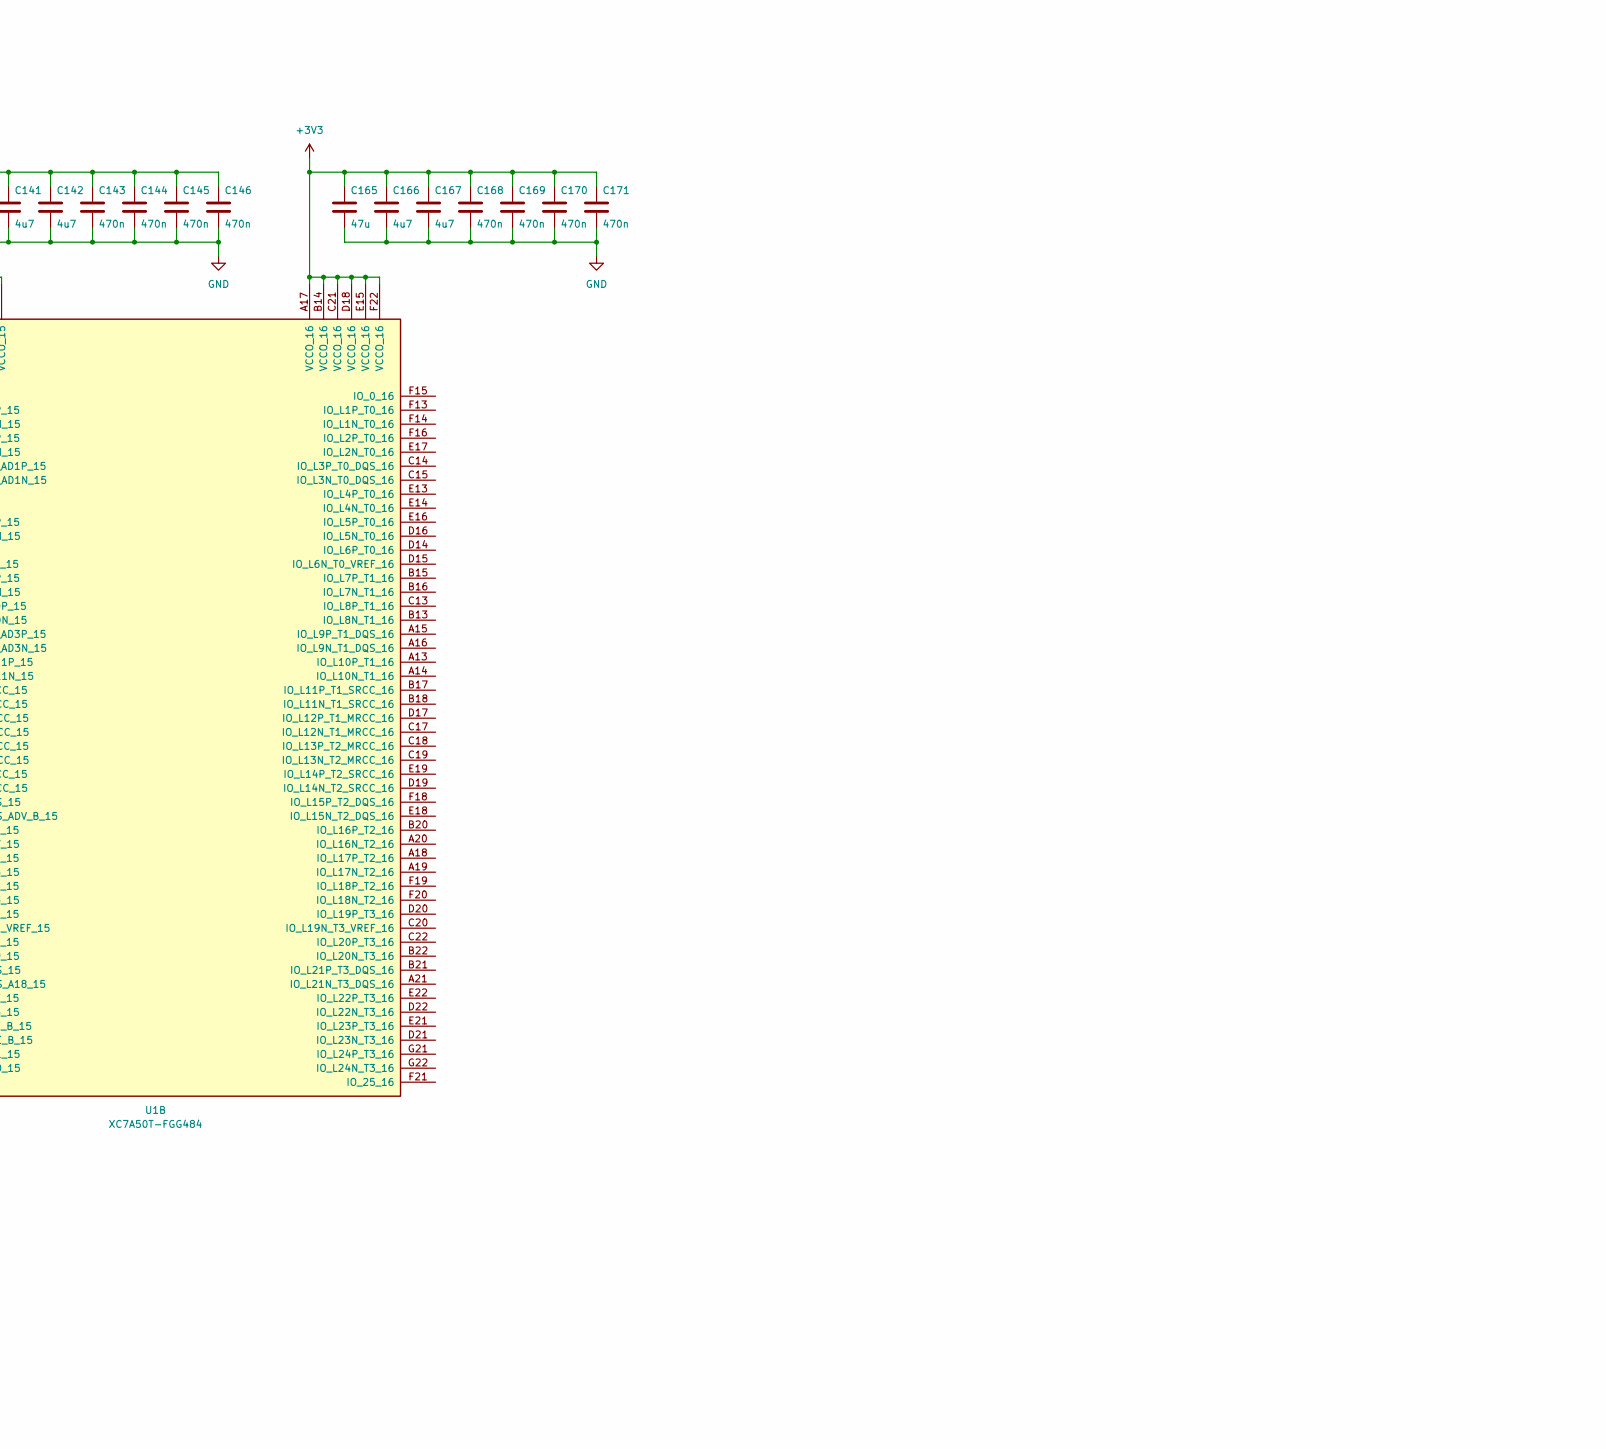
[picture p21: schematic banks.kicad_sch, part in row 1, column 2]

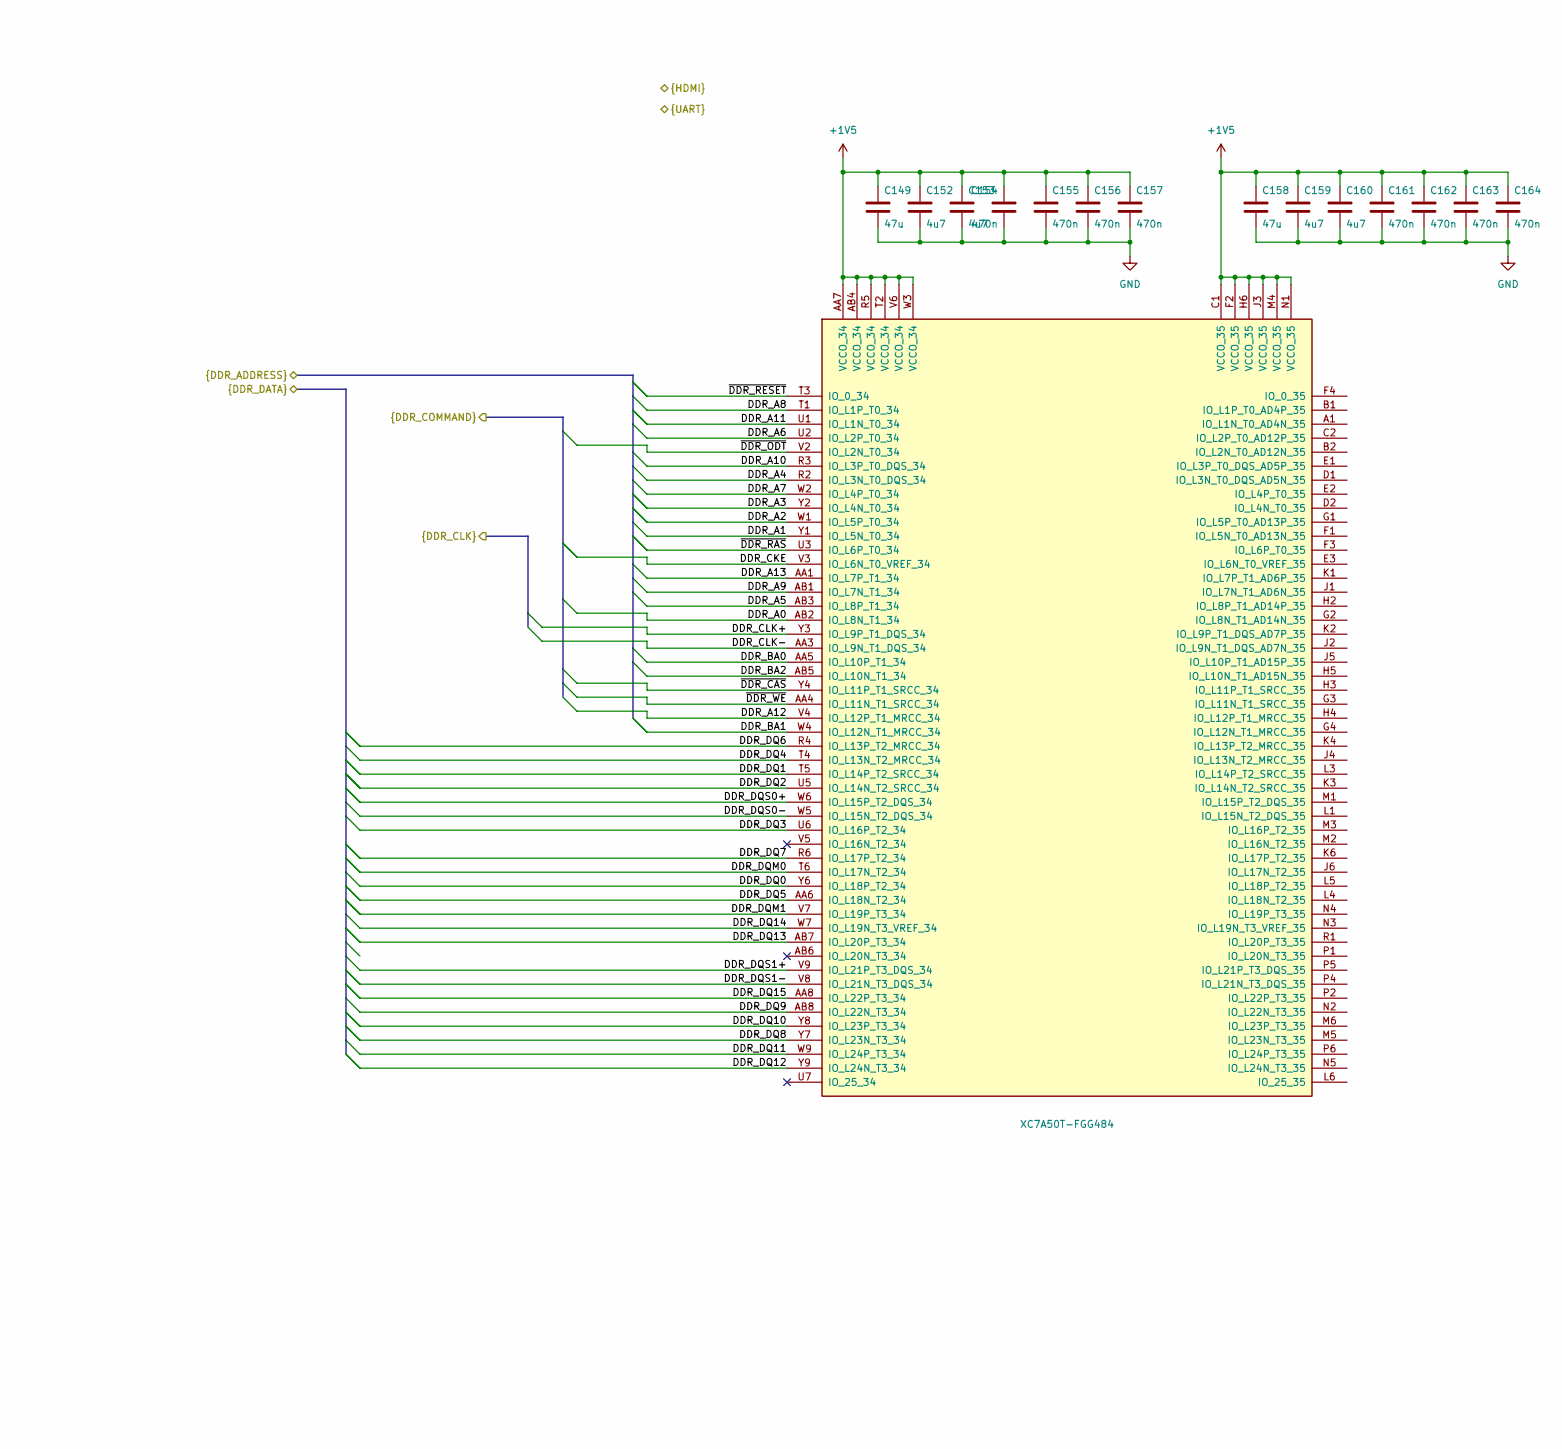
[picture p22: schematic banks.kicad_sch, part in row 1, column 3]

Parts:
C88, C132, C140, C149, C158, C165: 47u; C_1206_3216Metric
C89, C90, C133, C134, C141, C142, C152, C153, C159, C160, C166, C167: 4u7; C_0603_1608Metric
C91, C92, C124, C125, C135, C136, C137, C138, C143, C144, C145, C146, C154, C155, C156, C157, C161, C162, C163, C164, C168, C169, C170, C171: 470n; C_0201_0603Metric
C139: 100n; C_0402_1005Metric
R43: 1k; R_0402_1005Metric
R44: 1k; R_0402_1005Metric; not fitted
R45, R46: 10k; R_0402_1005Metric
R75: 22; R_0402_1005Metric
U1: XC7A50T-FGG484; Xilinx_FGG484
Y3: 100MHz; Oscillator_SMD_SiT_PQFN-4Pin_5.0x3.2mm; MPN SIT8008BI-32-33E-100.000000; LCSC C78882

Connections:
+1V5: C149.1, C152.1, C153.1, C154.1, C155.1, C156.1, C157.1, C158.1, C159.1, C160.1, C161.1, C162.1, C163.1, C164.1, U1.AA7 (VCCO_34), U1.AB4 (VCCO_34), U1.C1 (VCCO_35), U1.F2 (VCCO_35), U1.H6 (VCCO_35), U1.J3 (VCCO_35), U1.M4 (VCCO_35), U1.N1 (VCCO_35), U1.R5 (VCCO_34), U1.T2 (VCCO_34), U1.V6 (VCCO_34), U1.W3 (VCCO_34); also elsewhere on the board
+3V3: C88.1, C89.1, C90.1, C91.1, C92.1, C124.1, C125.1, C132.1, C133.1, C134.1, C135.1, C136.1, C137.1, C138.1, C139.1, C140.1, C141.1, C142.1, C143.1, C144.1, C145.1, C146.1, C165.1, C166.1, C167.1, C168.1, C169.1, C170.1, C171.1, R43.1, R45.1, R46.1, U1.A17 (VCCO_16), U1.AA17 (VCCO_13), U1.AB14 (VCCO_13), U1.B14 (VCCO_16), U1.C21 (VCCO_16), U1.D18 (VCCO_16), U1.E15 (VCCO_16), U1.F22 (VCCO_16), U1.G19 (VCCO_15), U1.H16 (VCCO_15), U1.J13 (VCCO_15), U1.K20 (VCCO_15), U1.L17 (VCCO_15), U1.M14 (VCCO_14), U1.N21 (VCCO_15), U1.P18 (VCCO_14), U1.R15 (VCCO_14), U1.T22 (VCCO_14), U1.U19 (VCCO_14), U1.V16 (VCCO_13), U1.W13 (VCCO_13), U1.Y10 (VCCO_13), U1.Y20 (VCCO_14), Y3.4 (Vdd); also elsewhere on the board
/Artix 7 Banks/BUCK_PG4: Y3.1 (OE); also elsewhere on the board
/Artix 7 Banks/CLK_100MHz: R75.2, U1.W19 (IO_L12P_T1_MRCC_14)
/Artix 7 Banks/DDR_A0: U1.AB2 (IO_L8N_T1_34); also elsewhere on the board
/Artix 7 Banks/DDR_A1: U1.Y1 (IO_L5N_T0_34); also elsewhere on the board
/Artix 7 Banks/DDR_A2: U1.W1 (IO_L5P_T0_34); also elsewhere on the board
/Artix 7 Banks/DDR_A3: U1.Y2 (IO_L4N_T0_34); also elsewhere on the board
/Artix 7 Banks/DDR_A4: U1.R2 (IO_L3N_T0_DQS_34); also elsewhere on the board
/Artix 7 Banks/DDR_A5: U1.AB3 (IO_L8P_T1_34); also elsewhere on the board
/Artix 7 Banks/DDR_A6: U1.U2 (IO_L2P_T0_34); also elsewhere on the board
/Artix 7 Banks/DDR_A7: U1.W2 (IO_L4P_T0_34); also elsewhere on the board
/Artix 7 Banks/DDR_A8: U1.T1 (IO_L1P_T0_34); also elsewhere on the board
/Artix 7 Banks/DDR_A9: U1.AB1 (IO_L7N_T1_34); also elsewhere on the board
/Artix 7 Banks/DDR_A10: U1.R3 (IO_L3P_T0_DQS_34); also elsewhere on the board
/Artix 7 Banks/DDR_A11: U1.U1 (IO_L1N_T0_34); also elsewhere on the board
/Artix 7 Banks/DDR_A12: U1.V4 (IO_L12P_T1_MRCC_34); also elsewhere on the board
/Artix 7 Banks/DDR_A13: U1.AA1 (IO_L7P_T1_34); also elsewhere on the board
/Artix 7 Banks/DDR_BA0: U1.AA5 (IO_L10P_T1_34); also elsewhere on the board
/Artix 7 Banks/DDR_BA1: U1.W4 (IO_L12N_T1_MRCC_34); also elsewhere on the board
/Artix 7 Banks/DDR_BA2: U1.AB5 (IO_L10N_T1_34); also elsewhere on the board
/Artix 7 Banks/DDR_CKE: U1.V3 (IO_L6N_T0_VREF_34); also elsewhere on the board
/Artix 7 Banks/DDR_CLK+: U1.Y3 (IO_L9P_T1_DQS_34); also elsewhere on the board
/Artix 7 Banks/DDR_CLK-: U1.AA3 (IO_L9N_T1_DQS_34); also elsewhere on the board
/Artix 7 Banks/DDR_DQ0: U1.Y6 (IO_L18P_T2_34); also elsewhere on the board
/Artix 7 Banks/DDR_DQ1: U1.T5 (IO_L14P_T2_SRCC_34); also elsewhere on the board
/Artix 7 Banks/DDR_DQ2: U1.U5 (IO_L14N_T2_SRCC_34); also elsewhere on the board
/Artix 7 Banks/DDR_DQ3: U1.U6 (IO_L16P_T2_34); also elsewhere on the board
/Artix 7 Banks/DDR_DQ4: U1.T4 (IO_L13N_T2_MRCC_34); also elsewhere on the board
/Artix 7 Banks/DDR_DQ5: U1.AA6 (IO_L18N_T2_34); also elsewhere on the board
/Artix 7 Banks/DDR_DQ6: U1.R4 (IO_L13P_T2_MRCC_34); also elsewhere on the board
/Artix 7 Banks/DDR_DQ7: U1.R6 (IO_L17P_T2_34); also elsewhere on the board
/Artix 7 Banks/DDR_DQ8: U1.Y7 (IO_L23N_T3_34); also elsewhere on the board
/Artix 7 Banks/DDR_DQ9: U1.AB8 (IO_L22N_T3_34); also elsewhere on the board
/Artix 7 Banks/DDR_DQ10: U1.Y8 (IO_L23P_T3_34); also elsewhere on the board
/Artix 7 Banks/DDR_DQ11: U1.W9 (IO_L24P_T3_34); also elsewhere on the board
/Artix 7 Banks/DDR_DQ12: U1.Y9 (IO_L24N_T3_34); also elsewhere on the board
/Artix 7 Banks/DDR_DQ13: U1.AB7 (IO_L20P_T3_34); also elsewhere on the board
/Artix 7 Banks/DDR_DQ14: U1.W7 (IO_L19N_T3_VREF_34); also elsewhere on the board
/Artix 7 Banks/DDR_DQ15: U1.AA8 (IO_L22P_T3_34); also elsewhere on the board
/Artix 7 Banks/DDR_DQM0: U1.T6 (IO_L17N_T2_34); also elsewhere on the board
/Artix 7 Banks/DDR_DQM1: U1.V7 (IO_L19P_T3_34); also elsewhere on the board
/Artix 7 Banks/DDR_DQS0+: U1.W6 (IO_L15P_T2_DQS_34); also elsewhere on the board
/Artix 7 Banks/DDR_DQS0-: U1.W5 (IO_L15N_T2_DQS_34); also elsewhere on the board
/Artix 7 Banks/DDR_DQS1+: U1.V9 (IO_L21P_T3_DQS_34); also elsewhere on the board
/Artix 7 Banks/DDR_DQS1-: U1.V8 (IO_L21N_T3_DQS_34); also elsewhere on the board
/Artix 7 Banks/QSPI_CS: U1.T19 (IO_L6P_T0_FCS_B_14); also elsewhere on the board
/Artix 7 Banks/QSPI_DQ0: U1.P22 (IO_L1P_T0_D00_MOSI_14); also elsewhere on the board
/Artix 7 Banks/QSPI_DQ1: U1.R22 (IO_L1N_T0_D01_DIN_14); also elsewhere on the board
/Artix 7 Banks/QSPI_DQ2: U1.P21 (IO_L2P_T0_D02_14); also elsewhere on the board
/Artix 7 Banks/QSPI_DQ3: U1.R21 (IO_L2N_T0_D03_14); also elsewhere on the board
/Artix 7 Banks/~DDR_CAS: U1.Y4 (IO_L11P_T1_SRCC_34); also elsewhere on the board
/Artix 7 Banks/~DDR_ODT: U1.V2 (IO_L2N_T0_34); also elsewhere on the board
/Artix 7 Banks/~DDR_RAS: U1.U3 (IO_L6P_T0_34); also elsewhere on the board
/Artix 7 Banks/~DDR_RESET: U1.T3 (IO_0_34); also elsewhere on the board
/Artix 7 Banks/~DDR_WE: U1.AA4 (IO_L11N_T1_SRCC_34); also elsewhere on the board
/Artix 7 Banks/~PCIe_CLKREQ: R46.2, U1.AA19 (IO_L15P_T2_DQS_RDWR_B_14); also elsewhere on the board
/Artix 7 Banks/~PCIe_PERST: U1.AB20 (IO_L15N_T2_DQS_DOUT_CSO_B_14); also elsewhere on the board
/Artix 7 Banks/~PCIe_PEWAKE: R45.2, U1.V17 (IO_L16P_T2_CSI_B_14); also elsewhere on the board
GND: C88.2, C89.2, C90.2, C91.2, C92.2, C124.2, C125.2, C132.2, C133.2, C134.2, C135.2, C136.2, C137.2, C138.2, C139.2, C140.2, C141.2, C142.2, C143.2, C144.2, C145.2, C146.2, C149.2, C152.2, C153.2, C154.2, C155.2, C156.2, C157.2, C158.2, C159.2, C160.2, C161.2, C162.2, C163.2, C164.2, C165.2, C166.2, C167.2, C168.2, C169.2, C170.2, C171.2, R44.2, Y3.2 (GND); also elsewhere on the board
unnamed: R43.2, R44.1, U1.U22 (IO_L3P_T0_DQS_PUDC_B_14)
unnamed: R75.1, Y3.3 (OUT)

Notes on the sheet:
Most of the NC's are usable as I/O's too, even if they're configurations ;)
47u + 2x 4u7 + 4x 470n capacitors per bank!
Move if needed
Wait for rails before starting the crystal! >
Pull HIGH = disable internal I/O pullups Pull LOW = enable internal I/O pullups
< Can change to different pins if needed, just pin optimizing

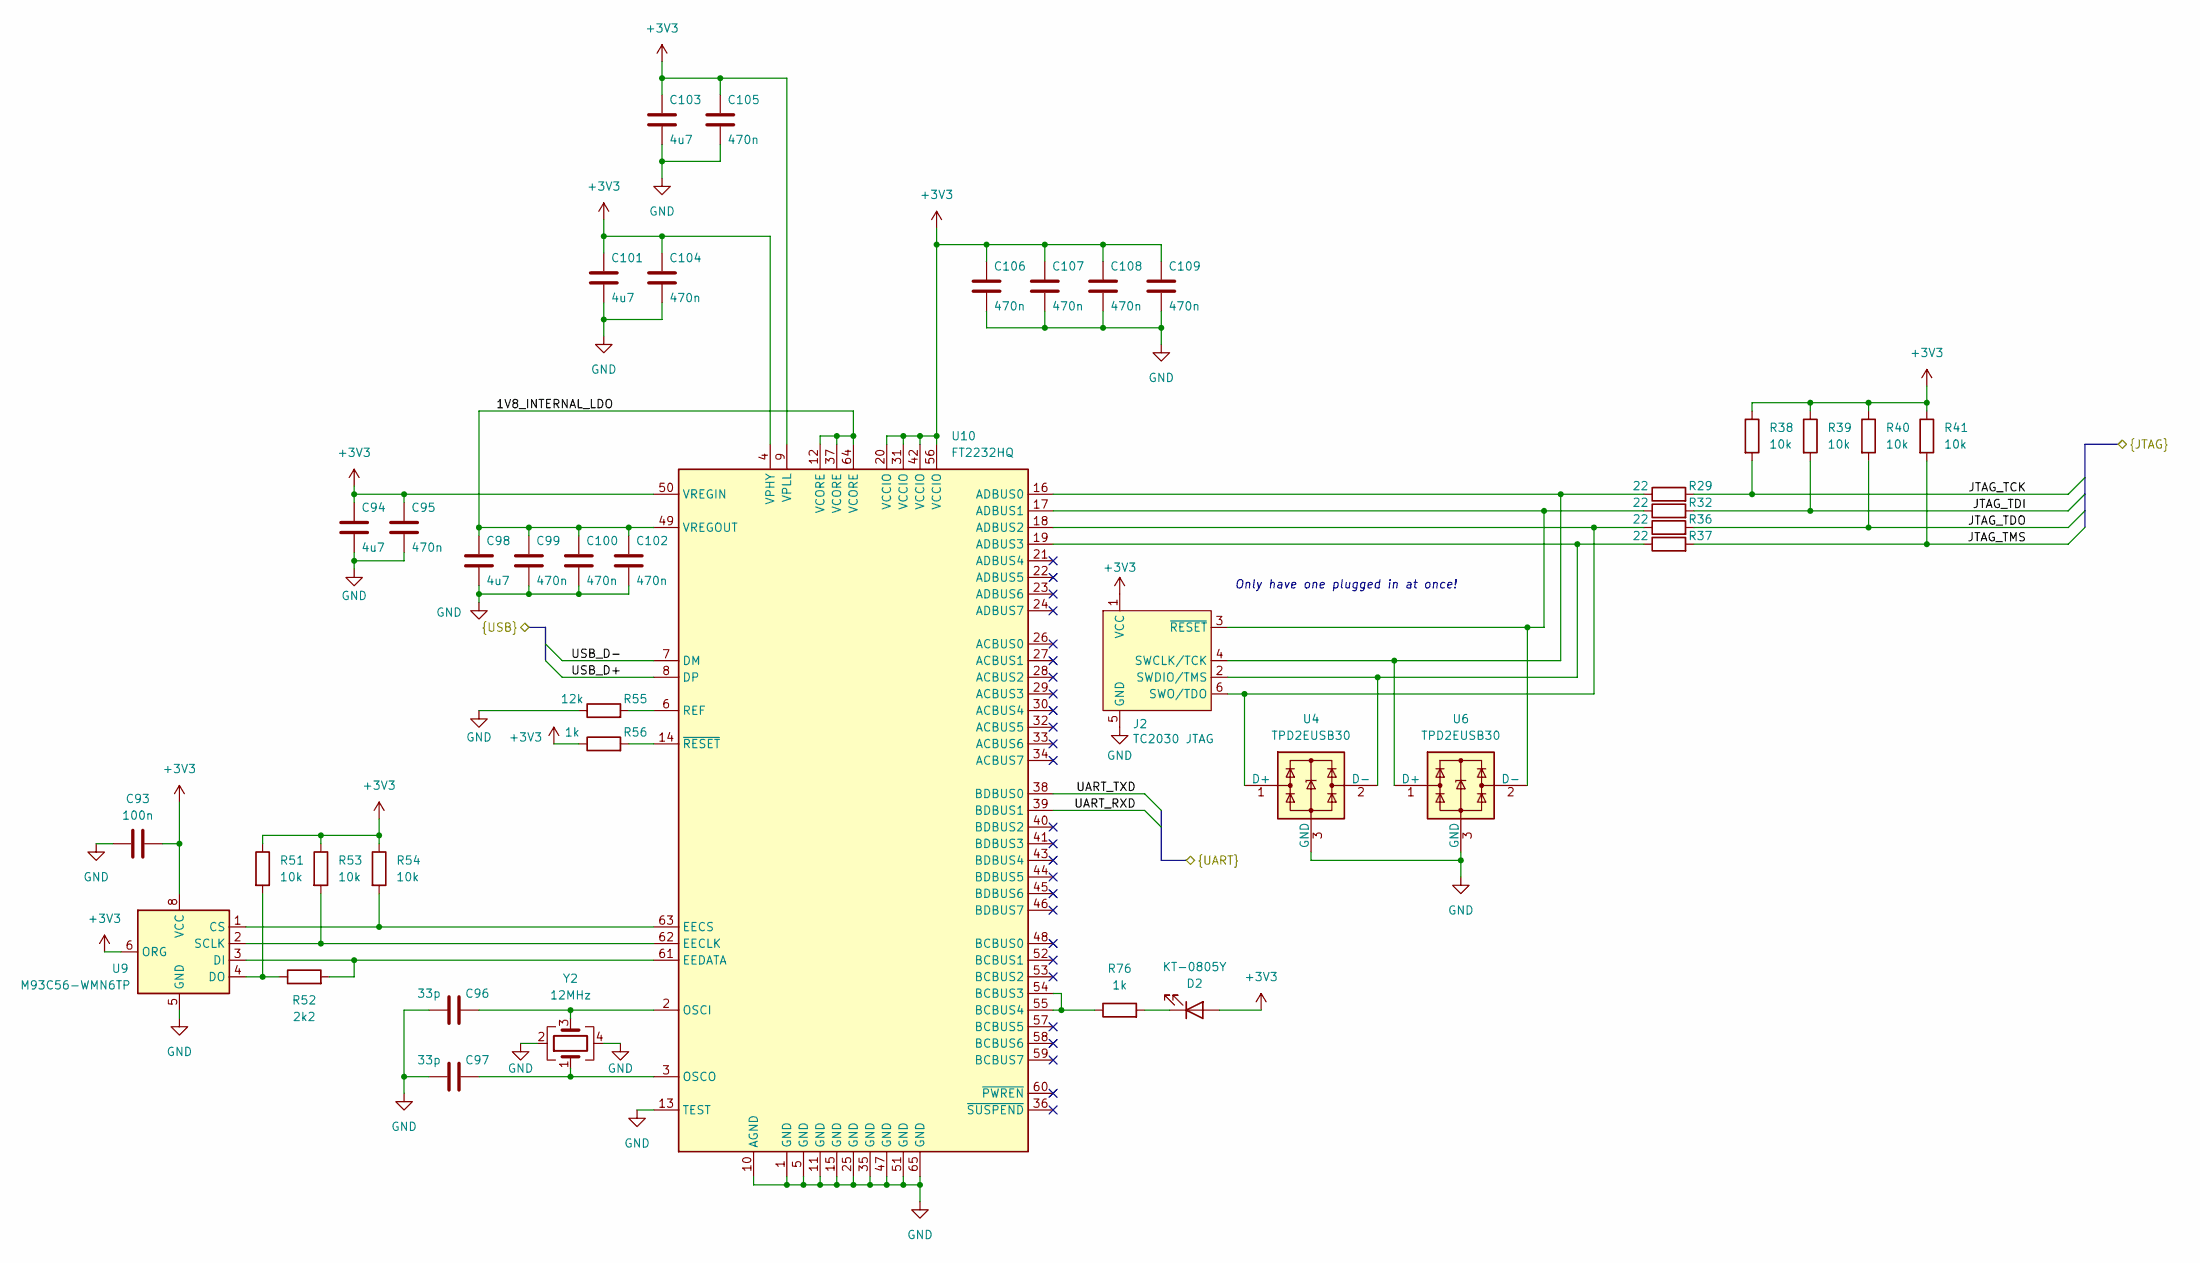
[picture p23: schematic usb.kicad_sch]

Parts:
C93: 100n; C_0402_1005Metric
C94, C98, C101, C103: 4u7; C_0603_1608Metric
C95, C99, C100, C102, C104, C105, C106, C107, C108, C109: 470n; C_0201_0603Metric
C96, C97: 33p; C_0402_1005Metric
D2: KT-0805Y; LED_0805_2012Metric; MPN KT-0805Y; LCSC C2296
J2: Conn_ARM_SWD_TagConnect_TC2030; Tag-Connect_TC2030-IDC-FP_2x03_P1.27mm_Vertical
R29, R32, R36, R37: 22; R_0402_1005Metric
R38, R39, R40, R41, R51, R53, R54: 10k; R_0402_1005Metric
R52: 2k2; R_0402_1005Metric
R55: 12k; R_0402_1005Metric
R56, R76: 1k; R_0402_1005Metric
U4, U6: TPD2EUSB30; Texas_DRT-3
U9: M93C56-WMN6TP; SOIC-8_3.9x4.9mm_P1.27mm
U10: FT2232HQ; QFN-64-1EP_9x9mm_P0.5mm_EP4.35x4.35mm
Y2: 12MHz; Crystal_SMD_3225-4Pin_3.2x2.5mm; MPN X322512MSB4SI; LCSC C9002

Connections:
+3V3: C93.2, C94.1, C95.1, C101.1, C103.1, C104.1, C105.1, C106.1, C107.1, C108.1, C109.1, D2.2 (A), J2.1 (VCC), R38.1, R39.1, R40.1, R41.1, R51.1, R53.1, R54.1, R56.1, U9.6 (ORG), U9.8 (VCC), U10.4 (VPHY), U10.9 (VPLL), U10.20 (VCCIO), U10.31 (VCCIO), U10.42 (VCCIO), U10.50 (VREGIN), U10.56 (VCCIO); also elsewhere on the board
/Artix 7 Banks/UART_RXD: U10.39 (BDBUS1)
/Artix 7 Banks/UART_TXD: U10.38 (BDBUS0)
/Artix 7 Configurations and Flash/JTAG_TCK: R29.2, R38.2; also elsewhere on the board
/Artix 7 Configurations and Flash/JTAG_TDI: R32.2, R39.2; also elsewhere on the board
/Artix 7 Configurations and Flash/JTAG_TDO: R36.2, R40.2; also elsewhere on the board
/Artix 7 Configurations and Flash/JTAG_TMS: R37.2, R41.2; also elsewhere on the board
/USB to JTAG/1V8_INTERNAL_LDO: C98.1, C99.1, C100.1, C102.1, U10.12 (VCORE), U10.37 (VCORE), U10.49 (VREGOUT), U10.64 (VCORE)
/USB to JTAG/USB_D+: U10.8 (DP); also elsewhere on the board
/USB to JTAG/USB_D-: U10.7 (DM); also elsewhere on the board
GND: C93.1, C94.2, C95.2, C96.1, C97.1, C98.2, C99.2, C100.2, C101.2, C102.2, C103.2, C104.2, C105.2, C106.2, C107.2, C108.2, C109.2, J2.5 (GND), R55.1, U4.3 (GND), U6.3 (GND), U9.5 (GND), U10.1 (GND), U10.5 (GND), U10.10 (AGND), U10.11 (GND), U10.13 (TEST), U10.15 (GND), U10.25 (GND), U10.35 (GND), U10.47 (GND), U10.51 (GND), U10.65 (GND), Y2.2, Y2.4; also elsewhere on the board
unnamed: D2.1 (K), R76.2
unnamed: J2.4 (SWCLK/TCK), R29.1, U6.1 (D+), U10.16 (ADBUS0)
unnamed: J2.2 (SWDIO/TMS), R37.1, U4.2 (D-), U10.19 (ADBUS3)
unnamed: J2.6 (SWO/TDO), R36.1, U4.1 (D+), U10.18 (ADBUS2)
unnamed: J2.3 (~RESET), R32.1, U6.2 (D-), U10.17 (ADBUS1)
unnamed: R51.2, R52.1, U9.4 (DO)
unnamed: R76.1, U10.54 (BCBUS3), U10.55 (BCBUS4)
unnamed: R53.2, U9.2 (SCLK), U10.62 (EECLK)
unnamed: R54.2, U9.1 (CS), U10.63 (EECS)
unnamed: R52.2, U9.3 (DI), U10.61 (EEDATA)
unnamed: C96.2, U10.2 (OSCI), Y2.3
unnamed: C97.2, U10.3 (OSCO), Y2.1
unnamed: R55.2, U10.6 (REF)
unnamed: R56.2, U10.14 (~RESET)

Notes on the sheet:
Only have one plugged in at once!

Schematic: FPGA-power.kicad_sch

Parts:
C17, C18, C19, C20, C25, C27, C28, C29, C30, C31, C35, C36, C38, C39, C47, C54, C55, C118, C148: 470n; C_0201_0603Metric
C21, C22, C23, C32, C33, C37, C40, C56: 4u7; C_0603_1608Metric
C24: 330u; CP_EIA-3528-21_Kemet-B; MPN ETPE330MA9GB; LCSC C542287
C26: 100u; C_1206_3216Metric; MPN CL31A107MQHNNNE; LCSC C15008
C34: 47u; C_1206_3216Metric
FB1, FB2: 120@100MHz; L_0805_2012Metric; MPN 742792023; LCSC C5120901
R1: 100; R_0402_1005Metric
U1: XC7A50T-FGG484; Xilinx_FGG484

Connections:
+1V0: C17.1, C18.1, C19.1, C20.1, C21.1, C22.1, C23.1, C24.1, C25.1, C26.1, C56.1, C118.1, C148.1, FB1.1, U1.H8 (VCCINT), U1.H10 (VCCINT), U1.J7 (VCCINT), U1.J9 (VCCINT), U1.J11 (VCCBRAM), U1.K8 (VCCINT), U1.L7 (VCCINT), U1.L11 (VCCBRAM), U1.M8 (VCCINT), U1.N7 (VCCINT), U1.N11 (VCCBRAM), U1.P8 (VCCINT), U1.P10 (VCCINT), U1.R7 (VCCINT), U1.R9 (VCCINT), U1.T8 (VCCINT), U1.T10 (VCCINT); also elsewhere on the board
+1V2: C38.1, C39.1, C40.1, R1.2, U1.B5 (MGTAVTT), U1.B7 (MGTAVTT), U1.B9 (MGTAVTT), U1.B11 (MGTAVTT), U1.C4 (MGTAVTT), U1.C8 (MGTAVTT); also elsewhere on the board
+1V8: C27.1, C28.1, C29.1, C30.1, C31.1, C32.1, C33.1, C34.1, C54.1, FB2.1, U1.E12 (VCCBATT_0), U1.H12 (VCCAUX), U1.K12 (VCCAUX), U1.M12 (VCCAUX), U1.P12 (VCCAUX), U1.R11 (VCCAUX); also elsewhere on the board
GND: C17.2, C18.2, C19.2, C20.2, C21.2, C22.2, C23.2, C24.2, C25.2, C26.2, C27.2, C28.2, C29.2, C30.2, C31.2, C32.2, C33.2, C34.2, C35.2, C36.2, C37.2, C38.2, C39.2, C40.2, C47.2, C54.2, C55.2, C56.2, C118.2, C148.2, U1.A2 (GND), U1.A3 (GND), U1.A5 (GND), U1.A7 (GND), U1.A9 (GND), U1.A11 (GND), U1.A12 (GND), U1.A22 (GND), U1.AA2 (GND), U1.AA12 (GND), U1.AA22 (GND), U1.AB9 (GND), U1.AB19 (GND), U1.B3 (GND), U1.B12 (GND), U1.B19 (GND), U1.C3 (GND), U1.C6 (GND), U1.C10 (GND), U1.C12 (GND), U1.C16 (GND), U1.D3 (GND), U1.D4 (GND), U1.D8 (GND), U1.D12 (GND), U1.D13 (GND), U1.E4 (GND), U1.E5 (GND), U1.E7 (GND), U1.E9 (GND), U1.E11 (GND), U1.E20 (GND), U1.F5 (GND), U1.F11 (GND), U1.F17 (GND), U1.G5 (GND), U1.G6 (GND), U1.G7 (GND), U1.G8 (GND), U1.G9 (GND), U1.G10 (GND), U1.G12 (GND), U1.G14 (GND), U1.H1 (GND), U1.H7 (GND), U1.H9 (GND), U1.H11 (GND), U1.H21 (GND), U1.J8 (GND), U1.J10 (GND), U1.J12 (GND), U1.J18 (GND), U1.K5 (GND), U1.K7 (GND), U1.K9 (GNDADC_0), U1.K11 (GND), U1.K15 (GND), U1.L2 (GND), U1.L8 (GND), U1.L22 (GND), U1.M7 (GND), U1.M11 (GND), U1.M19 (GND), U1.N6 (GND), U1.N8 (GND), U1.N16 (GND), U1.P3 (GND), U1.P7 (GND), U1.P9 (GND), U1.P11 (GND), U1.P13 (GND), U1.R8 (GND), U1.R10 (GND), U1.R12 (GND), U1.R20 (GND), U1.T7 (GND), U1.T9 (GND), U1.T11 (GND), U1.T17 (GND), U1.U4 (GND), U1.U14 (GND), U1.V1 (GND), U1.V11 (GND), U1.V21 (GND), U1.W8 (GND), U1.W18 (GND), U1.Y5 (GND), U1.Y15 (GND); also elsewhere on the board
unnamed: C35.1, C36.1, C37.1, C55.1, FB1.2, U1.D6 (MGTAVCC), U1.D10 (MGTAVCC), U1.E8 (MGTAVCC), U1.F7 (MGTAVCC), U1.F9 (MGTAVCC)
unnamed: R1.1, U1.F8 (MGTRREF_216)
unnamed: C47.1, FB2.2, U1.K10 (VCCADC_0)

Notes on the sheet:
No ferrite bead because low impedance termination rail!
Decoupling before and after bead for high current rail!
Simulate beads in LTSpice!

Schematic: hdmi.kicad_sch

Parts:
C14, C16, C113, C114, C115, C116, C117, C119, C120, C122, C123: 100n; C_0402_1005Metric
C121: 1u; C_0402_1005Metric
D3: 1N5819WS; D_SOD-323; MPN 1N5819WS
J7: HDMI_D_1.4; HDMI_Micro-D_Molex_46765-1xxx; MPN HYC23-HDMID19-650; LCSC C711358
R47: 30k; R_0603_1608Metric
R57: 1k; R_0402_1005Metric
R58: 100k; R_0402_1005Metric
R59, R60, R61, R62: 4k7; R_0402_1005Metric
U12: PCA9306DC1; VSSOP-8_2.3x2mm_P0.5mm; MPN PCA9306DC1; LCSC C129510
U14, U15, U16: UCL0524P; Diodes_UDFN-10_1.0x2.5mm_P0.5mm; MPN UCL0524P; LCSC C2835428

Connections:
+3V3: C123.1, R47.1, R61.1, R62.1, U12.2 (VREF1); also elsewhere on the board
+VBUS: D3.2 (A), R58.1, R59.1, R60.1; also elsewhere on the board
/Artix 7 Banks/HDMI_CEC: J7.15 (CEC), R47.2, U14.4, U14.7
/Artix 7 Banks/HDMI_CLK+: C16.1
/Artix 7 Banks/HDMI_CLK-: C14.1
/Artix 7 Banks/HDMI_D0+: C114.1
/Artix 7 Banks/HDMI_D0-: C113.1
/Artix 7 Banks/HDMI_D1+: C116.1
/Artix 7 Banks/HDMI_D1-: C115.1
/Artix 7 Banks/HDMI_D2+: C119.1
/Artix 7 Banks/HDMI_D2-: C117.1
/Artix 7 Banks/HDMI_HPD: R57.1
/Artix 7 Banks/HDMI_SCL: R61.2, U12.3 (SCL1)
/Artix 7 Banks/HDMI_SDA: R62.2, U12.4 (SDA1)
/HDMI/HDMI_SCL_5V: J7.17 (SCL), R60.2, U12.6 (SCL2), U14.1, U14.10
/HDMI/HDMI_SDA_5V: J7.18 (SDA), R59.2, U12.5 (SDA2), U14.2, U14.9
GND: C120.2, C121.2, C122.2, C123.2, J7.4 (D2S), J7.7 (D1S), J7.10 (D0S), J7.13 (CKS), J7.16 (GND), J7.SH, U12.1 (GND), U14.3, U14.8, U15.3, U15.8, U16.3, U16.8; also elsewhere on the board
unnamed: C120.1, C121.1, D3.1 (K), J7.19 (+5V)
unnamed: C16.2, J7.12 (CK+), U16.4, U16.7
unnamed: C14.2, J7.14 (CK-), U16.5, U16.6
unnamed: C114.2, J7.9 (D0+), U16.1, U16.10
unnamed: C113.2, J7.11 (D0-), U16.2, U16.9
unnamed: C116.2, J7.6 (D1+), U15.4, U15.7
unnamed: C115.2, J7.8 (D1-), U15.5, U15.6
unnamed: C119.2, J7.3 (D2+), U15.1, U15.10
unnamed: C117.2, J7.5 (D2-), U15.2, U15.9
unnamed: J7.1 (HPD/HEAC-), R57.2, U14.5, U14.6
unnamed: C122.1, R58.2, U12.7 (VREF2), U12.8 (EN)

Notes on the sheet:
BOOST CONVERTER TO 5V??? JLC: "boost 5V", QX2303L50E maybe
Current limit resistor!

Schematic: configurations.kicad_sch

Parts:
C111: 100n; C_0402_1005Metric
C112: 1u; C_0402_1005Metric
C147: 47u; C_1206_3216Metric
C150, C151: 470n; C_0201_0603Metric
D1: KT-0805Y; LED_0805_2012Metric; MPN KT-0805Y; LCSC C2296
R2, R3, R14, R24: 1k; R_0402_1005Metric
R15: 1k; R_0402_1005Metric; not fitted
R19, R20, R21, R22, R27: 4k7; R_0402_1005Metric
SW1: SW_Push; SW_SPST_TS-1088-xR020; MPN TS-1088-AR02016; LCSC C720477
U1: XC7A50T-FGG484; Xilinx_FGG484
U7: MT25QL128ABA1EW7-0SIT; W-PDFN-8-1EP_6x5mm_P1.27mm_EP3x3mm; MPN MT25QL128ABA1EW7-0SIT; LCSC C2887898

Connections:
+3V3: C111.1, C112.1, C147.1, C150.1, C151.1, D1.2 (A), R2.1, R15.1, R19.1, R20.1, R21.1, R22.1, R27.2, U1.F12 (VCCO_0), U1.T12 (VCCO_0), U1.U8 (CFGBVS_0), U7.8 (VCC); also elsewhere on the board
/Artix 7 Banks/QSPI_CS: R19.2, U7.1 (~S); also elsewhere on the board
/Artix 7 Banks/QSPI_DQ0: U7.5 (DQ0); also elsewhere on the board
/Artix 7 Banks/QSPI_DQ1: U7.2 (DQ1); also elsewhere on the board
/Artix 7 Banks/QSPI_DQ2: R20.2, U7.3 (~W/DQ2); also elsewhere on the board
/Artix 7 Banks/QSPI_DQ3: R21.2, U7.7 (~RESET/DQ3); also elsewhere on the board
/Artix 7 Configurations and Flash/DONE: R24.1, U1.G11 (DONE_0)
/Artix 7 Configurations and Flash/JTAG_TCK: U1.V12 (TCK_0); also elsewhere on the board
/Artix 7 Configurations and Flash/JTAG_TDI: U1.R13 (TDI_0); also elsewhere on the board
/Artix 7 Configurations and Flash/JTAG_TDO: U1.U13 (TDO_0); also elsewhere on the board
/Artix 7 Configurations and Flash/JTAG_TMS: U1.T13 (TMS_0); also elsewhere on the board
/Artix 7 Configurations and Flash/PROG_B: R22.2, SW1.1, U1.N12 (PROGRAM_B_0)
/Artix 7 Configurations and Flash/QSPI_CLK: U1.L12 (CCLK_0), U7.6 (C)
GND: C111.2, C112.2, C147.2, C150.2, C151.2, R3.2, R14.2, SW1.2, U1.L9 (VREFN_0), U1.L10 (VP_0), U1.M9 (VN_0), U1.M10 (VREFP_0), U1.N9 (DXN_0), U1.N10 (DXP_0), U7.4 (VSS), U7.9 (PAD); also elsewhere on the board
unnamed: D1.1 (K), R24.2
unnamed: R27.1, U1.U12 (INIT_B_0)
unnamed: R2.2, U1.U11 (M0_0)
unnamed: R14.1, U1.U10 (M1_0)
unnamed: R3.1, R15.2, U1.U9 (M2_0)

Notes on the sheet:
< Manual configuration reset, it's a devboard so why not
< Optional for JTAG w/ built in artix memory
MAYBE ADD ADC??
Bank 14/15 need to be 3V3 because of CFGBVS
< Master SPI M[2:0] 001
< No temp sense, no internals, tying low (UG475)
< DONE sinks current, LED turns off when done

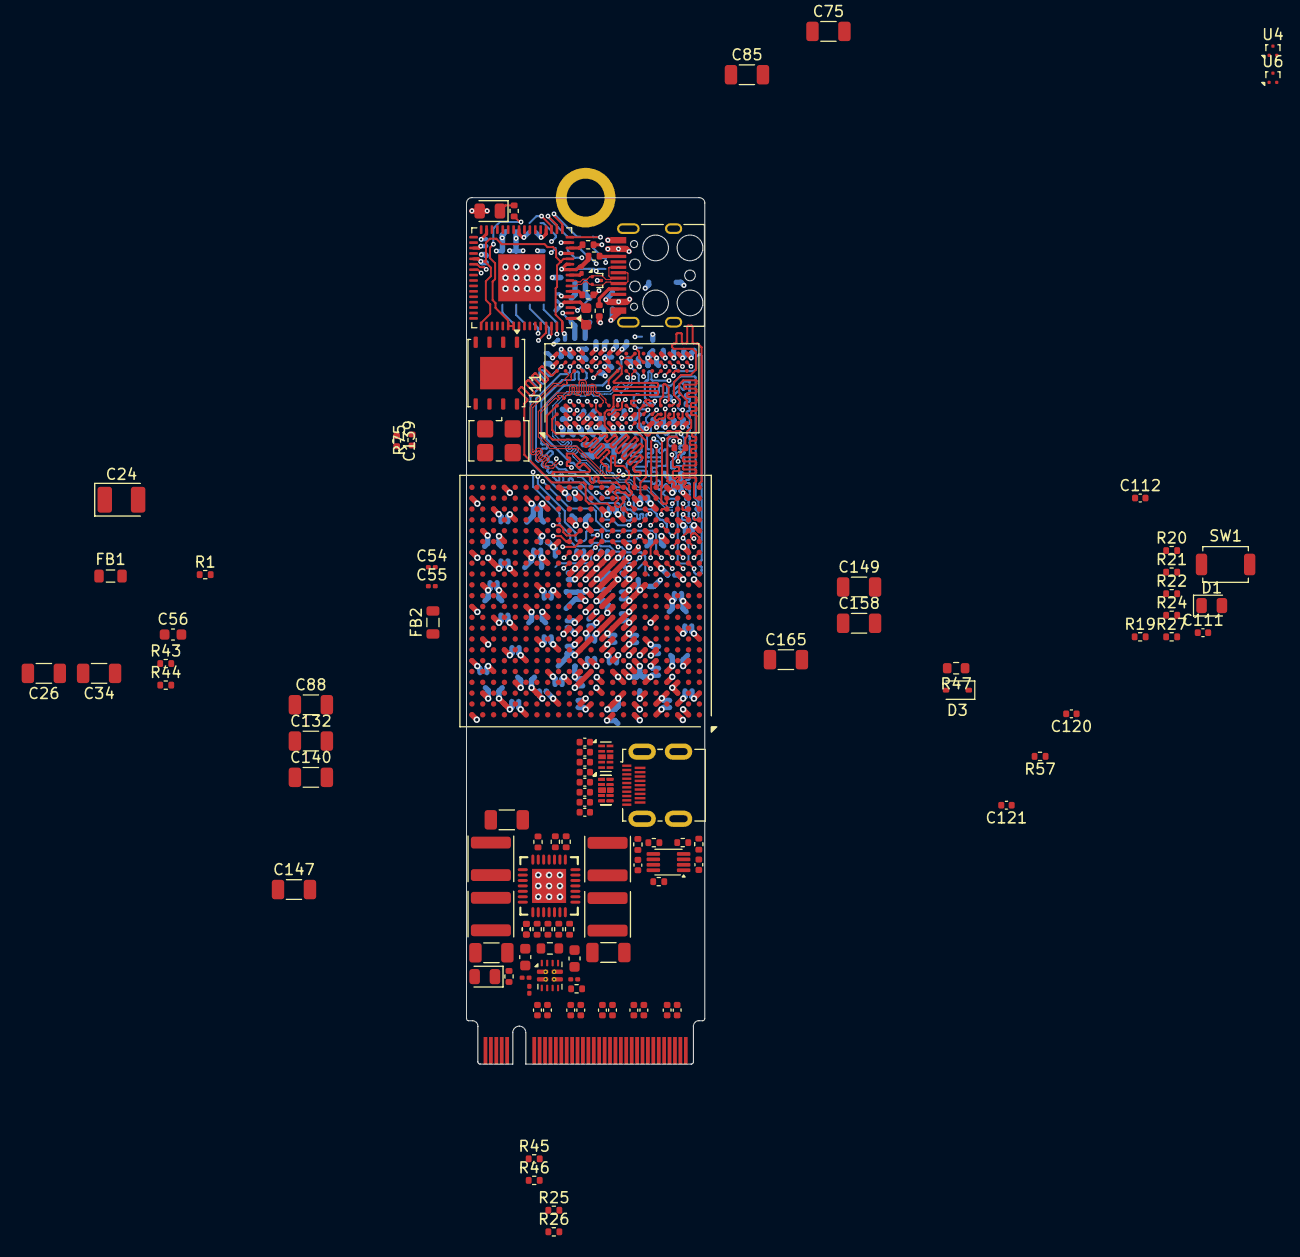
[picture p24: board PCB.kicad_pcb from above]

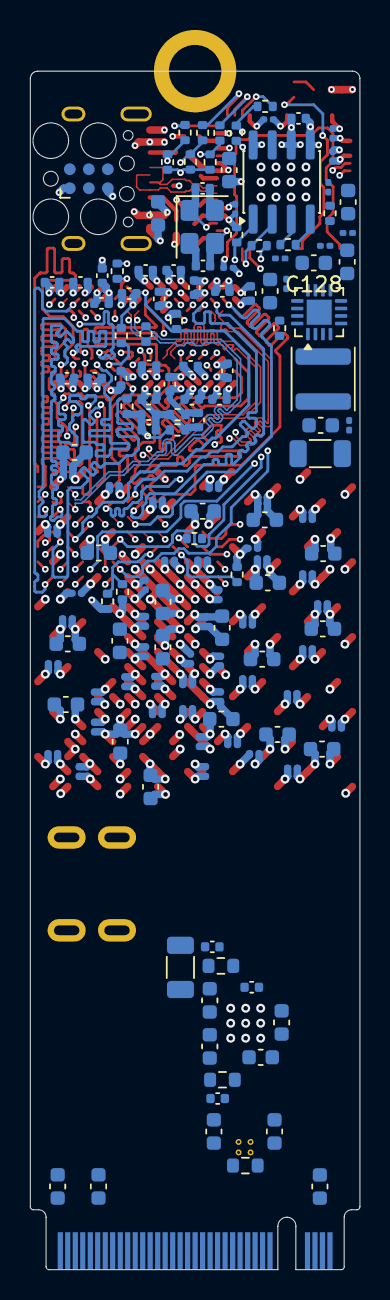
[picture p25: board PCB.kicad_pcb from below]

Board: 6 copper layers, 22.0 x 80.0 mm, 270 parts (153 on the bottom side), 168 nets.

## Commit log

2026-01-18 cleaning up USB-C, switching some of the decoupling and assigning a bunch of footprints
    [FPGA-power.kicad_sch, PCB.kicad_pcb, configurations.kicad_sch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]
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2026-01-18 fixed my FPGA footprint for use with my symbol
    [PCB.kicad_pcb, m.2-m-key.kicad_sch]
2026-01-18 set up my clearance for JLC
    [PCB.kicad_pcb]
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2026-01-19 fixing a bunch of footprints to standardize
    [PCB.kicad_pcb, ddr3.kicad_sch, usb.kicad_sch]
2026-01-19 organizing all the FPGA components on the PCB
    [PCB.kicad_pcb]
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2026-01-20 adding some MPN's in, searching for ethernet RJ45's
    [PCB.kicad_pcb, ethernet.kicad_sch, hdmi.kicad_sch]
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2026-01-21 switched to 6 layer board, starting to organize stuff
    [PCB.kicad_pcb]
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2026-01-21 completely organized the MAX20029 buck and cleaned up some silkscreen
    [PCB.kicad_pcb, power.kicad_sch]
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2026-01-22 cleaning up the silkscreen, inrush caps and other stuff
    [PCB.kicad_pcb]
2026-01-22 added a keep out to my m.2 edge connector, moving the AC/dampening and cleaning up back silkscreen
    [PCB.kicad_pcb]
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2026-01-22 forgot to create the bus alias definitions for uart and jtag
    [configurations.kicad_sch, usb.kicad_sch]
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2026-01-22 cleaning up the ft2232H decoupling, laying it out on the PCB too
    [PCB.kicad_pcb, usb.kicad_sch]
2026-01-22 cleaning up the silkscreen from the new components
    [PCB.kicad_pcb]
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2026-01-22 cleaning up the board, need to add a courtyard to my quad buck :/
    [PCB.kicad_pcb]
2026-01-22 heading to the next class, some minor changes
    [PCB.kicad_pcb, PCB.kicad_sch]
2026-01-22 wiring a terrible USB buck layout, buck might be too big?
    [PCB.kicad_pcb]
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2026-01-23 fixed my decoupling because I'm better than the datasheet
    [PCB.kicad_pcb, configurations.kicad_sch]
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2026-01-23 routing aa bunch of grounds for simple routing
    [PCB.kicad_pcb]
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2026-01-24 fixing my VREF decoupling, starting to route it!
    [PCB.kicad_pcb, ddr3.kicad_sch]
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2026-01-24 cleaning up silkscreen and isolating the traces some more
    [PCB.kicad_pcb]
2026-01-25 organizing stuff to get ready for DDR routing!
    [PCB.kicad_pcb]
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2026-01-27 working on DDR3 routing, this is going to be rough...
    [PCB.kicad_pcb]
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2026-01-27 minimizing crosstalk and adding in CLK net class
    [PCB.kicad_pcb]
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2026-01-29 managed to fit in all the traces, but ruined my cleaning up
    [PCB.kicad_pcb]
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2026-01-30 fixing my pads
    [PCB.kicad_pcb, ddr3.kicad_sch]
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2026-01-31 adjusted the top layer and inner a bit more
    [PCB.kicad_pcb]
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2026-01-31 found a couple stray pins not routed, finally did themgit add .
    [PCB.kicad_pcb]
2026-01-31 finished my DDR fanout after adding the pulldowns
    [PCB.kicad_pcb]
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2026-02-01 routed top and inner DDR, working on bottom!
    [PCB.kicad_pcb]
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2026-02-01 fixed the bbottom routinggit add .
    [PCB.kicad_pcb]
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2026-02-01 omg I'm so stupid, my routing is way easier because I had some pins routed on multiple layersgit add .
    [PCB.kicad_pcb]
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2026-02-03 starting to actually put the DDR traces to their pins
    [PCB.kicad_pcb, banks.kicad_sch]
2026-02-03 a bunch more routing and assigning, really messy but coming along
    [PCB.kicad_pcb, banks.kicad_sch]
2026-02-03 finished routing all the pins, very messy still
    [PCB.kicad_pcb, banks.kicad_sch]
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2026-02-06 technically layed out everything out I think finally
    [PCB.kicad_pcb]
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2026-02-08 5th time routing is the charm EHH :D
    [PCB.kicad_pcb, banks.kicad_sch, ddr3.kicad_sch]
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2026-02-09 OH MY, gotta move some bottom traces and then it'll be good :D
    [PCB.kicad_pcb]
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2026-02-11 cleaned up some stuff, heading to sleep :D
    [PCB.kicad_pcb, banks.kicad_sch]
2026-02-11 somehow put DQS pairs not on the specific data byte......................
    [banks.kicad_sch]
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2026-02-12 I'MMMMM crashing out
    [PCB.kicad_pcb, banks.kicad_sch]
2026-02-12 GOD TIER DQS pair layer switch to reduce reflections
    [PCB.kicad_pcb, banks.kicad_sch]
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2026-02-14 hopping off for now, I think this will come to me in the morning ;)
    [PCB.kicad_pcb, banks.kicad_sch]
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2026-02-14 cleaning up the traces even more, it's beautiful :D
    [PCB.kicad_pcb, banks.kicad_sch]
2026-02-14 BANNNG valid and cleaned up the schematic :D, next skew/length matching and finishing MIG
    [banks.kicad_sch]
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2026-02-15 some adjusting, trynna figure out how to do this :/
    [PCB.kicad_pcb]
2026-02-15 working on re-organizing for length matching, this is going to take a WHILE
    [PCB.kicad_pcb, banks.kicad_sch]
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2026-02-16 15mm and 33mm of max distance, only 18mmgit add . gotta get that smaller though :/
    [PCB.kicad_pcb, banks.kicad_sch]
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2026-02-16 adjusting all the via fanouts to 50R SE
    [PCB.kicad_pcb]
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2026-02-17 broke out my configuration pins, that took too long
    [PCB.kicad_pcb]
2026-02-17 fixing my length matching :D
    [PCB.kicad_pcb]
2026-02-17 trying to fit in all of the config passive :/
    [PCB.kicad_pcb]
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2026-02-18 technically routed up all my config passives, but it's a bit messy :/
    [PCB.kicad_pcb]
2026-02-18 OKAY THIS ACTUALLY WORKS, it's real jank though lol
    [PCB.kicad_pcb]
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2026-02-18 BANG! GGood to go breakout, more length matching time :D
    [PCB.kicad_pcb]
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2026-02-18 some quick length matching before I go to sleep I GOT THIS
    [PCB.kicad_pcb]
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2026-02-18 a bunch of work, length matching, moving traces
    [PCB.kicad_pcb]
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2026-02-20 I think that's all the data traces matched!
    [PCB.kicad_pcb]
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2026-02-20 GENUINE progress, getting so close, hardest last stretch now
    [PCB.kicad_pcb]
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2026-02-22 just a couple more traces to length match!
    [PCB.kicad_pcb]
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2026-02-23 Getting so crowded, barely any space left :/
    [PCB.kicad_pcb]
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2026-02-26 another line matched, just 2 left I think!
    [PCB.kicad_pcb]
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2026-02-26 restoring backup because my project crashed on school computers :/
    [PCB.kicad_pcb]
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2026-02-27 opening up space for the final length match!
    [PCB.kicad_pcb]
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2026-02-28 moving to V10, cleaning stuff up too :D
    [PCB.kicad_pcb]
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
